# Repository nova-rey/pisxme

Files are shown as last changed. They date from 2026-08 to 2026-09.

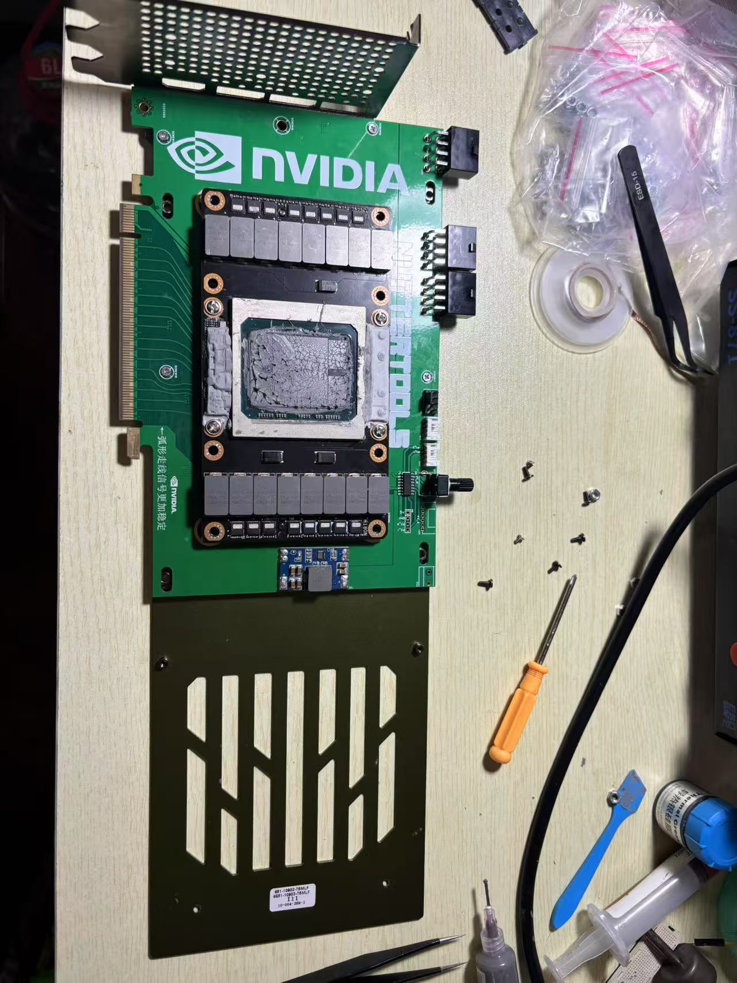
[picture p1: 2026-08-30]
references/LiuXinyu12378-SXM2_to_PCIE_adapter/images/WechatIMG451.jpg

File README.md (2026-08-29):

# PiSXMe

PiSXMe is an open-hardware compute-appliance carrier project for a Raspberry Pi Compute Module 5 and an NVIDIA Tesla V100 SXM2 module.

This public repository is a recovery/preservation snapshot prepared from verified local source files while the original iCloud-backed checkout contained unavailable File Provider placeholders. It preserves the Rev A design evidence and handoff material; it is not a claim that Rev A is fabrication-ready.

Read [HANDOFF_LINUX_WORKSTATION.md](HANDOFF_LINUX_WORKSTATION.md), [TOOLING_STATUS.md](TOOLING_STATUS.md), [references/REFERENCE_INDEX.md](references/REFERENCE_INDEX.md), and [plans/M6_LINUX_RESTART_CHECKLIST.md](plans/M6_LINUX_RESTART_CHECKLIST.md) before changing the design.

The authoritative active-design hashes and unavailable-source manifest are recorded in [RECOVERY_MANIFEST.md](RECOVERY_MANIFEST.md).

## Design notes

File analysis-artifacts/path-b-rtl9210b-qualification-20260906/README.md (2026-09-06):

# Path-B RTL9210B qualification fixture plan

Status: `PLAN_ONLY_NATIVE_FIXTURE_NOT_AUTHORIZED`

This is a disposable, read-only-first qualification artifact for the
RTL9210B-CG Path-B comparison. It is not production CAD, does not replace
Path A, and contains no copied or modified Path-A schematic/PCB content.

## Decision

Do not author a complete native Path-B KiCad fixture yet. The retained
community material is sufficient to state a narrow pin-identity contract, but
not sufficient to safely encode the support circuit, M-key sideband behavior,
power/isolation behavior, or virgin-chip provisioning assumptions. A partial
fixture would risk turning community guesses into electrical authority.

The smallest next fixture is a standalone RTL9210B bring-up board, authored
only after the gates in `fixture-plan.md` are closed. It must remain outside
the production project and must expose SPI-flash, UART/JTAG, reset, power,
mode, and M-key sideband test access.

## Artifact contents

- `fixture-plan.md` — bounded scope, facts, unknowns, gates, and acceptance plan.
- `pin-fact-boundary.csv` — machine-readable known/unknown boundary.
- `next-fixture-spec.json` — proposed smallest future standalone fixture.
- `baseline.md` — tool, stackup, correspondence, and fresh ERC/DRC evidence.
- `evidence-manifest.json` — source hashes and provenance boundaries.

No `.kicad_sch`, `.kicad_pcb`, library, project, rule, or production output is
authored by this artifact.

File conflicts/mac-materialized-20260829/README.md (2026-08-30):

# KiCad Codex Bridge

`kicad-codex-bridge` is a local MCP server that gives Codex a broad, observable control surface for KiCad 10. It uses the supported KiCad IPC API through `kicad-python` for live PCB work, the bundled `kicad-cli` for validation and exports, and a project-root-scoped file layer for KiCad source and generated files.

## Architecture

```text
Codex desktop / CLI
        |
        | Codex MCP config (stdio)
        v
server.py (FastMCP, 61 tools)
   |             |                  |
   |             |                  +--> scoped .kicad_* / libraries / outputs
   |             +--> bundled kicad-cli (DRC, ERC, exports, upgrades)
   +--> kicad-python 0.7.1 --> /tmp/kicad/api.sock --> KiCad PCB Editor
```

## Detected installation

- KiCad: `10.0.5`
- Application: `/Applications/KiCad/KiCad.app`
- CLI: `/Applications/KiCad/KiCad.app/Contents/MacOS/kicad-cli`
- Runtime: `/Users/Cooper/Documents/ChatGPT/sxm2/.venv311/bin/python` (Python 3.11)
- Binding: `kicad-python==0.7.1` (API build `10.0.1-0-g2db9e5a72b`)
- Project root: `/Users/Cooper/Documents/ChatGPT/sxm2`

`kicad-cli` is bundled but is not on the shell `PATH`. The bridge uses its absolute path and accepts `KICAD_CLI_PATH` as an override.

## Prerequisites and installation

KiCad must be installed. On this Mac, Homebrew Python 3.11 is used because the available KiCad Python binding and its dependency wheels are compatible with it.

```sh
cd /Users/Cooper/Documents/ChatGPT/sxm2
/usr/local/bin/python3.11 -m venv .venv311
.venv311/bin/python -m pip install -r requirements.txt
```

The checked-in environment was installed with `cryptography==44.0.3` because the newer source distribution attempted a Rust build on this Intel Mac. The pin is in `requirements.txt`.

## Start KiCad and the bridge

1. Start KiCad and open the target `.kicad_pcb` in PCB Editor.
2. In KiCad preferences, enable the KiCad API server under the Plugins/API settings.
3. Start the bridge as an MCP stdio process:

```sh
cd /Users/Cooper/Documents/ChatGPT/sxm2
KICAD_PROJECT_ROOT=/Users/Cooper/Documents/ChatGPT/sxm2 \
  .venv311/bin/python server.py
```

The process speaks MCP over stdin/stdout. Logs from FastMCP and KiCad are kept on stderr so the protocol stream remains clean.

## Codex registration

The supported local Codex mechanism is the `codex mcp` command, which writes the current user's MCP configuration. Register this exact server with:

```sh
codex mcp add kicad-codex-bridge \
  --env KICAD_PROJECT_ROOT=/Users/Cooper/Documents/ChatGPT/sxm2 -- \
  /Users/Cooper/Documents/ChatGPT/sxm2/.venv311/bin/python \
  /Users/Cooper/Documents/ChatGPT/sxm2/server.py
codex mcp list
```

The equivalent configuration is a `[mcp_servers.kicad-codex-bridge]` entry in `~/.codex/config.toml` with the same `command`, `args`, and an `[mcp_servers.kicad-codex-bridge.env]` table containing `KICAD_PROJECT_ROOT`. Codex desktop/CLI/IDE clients share this MCP configuration. A newly registered server may require a new Codex task or restart before its tools appear in an already-running task.

## Socket discovery and authentication

The bridge checks `KICAD_API_SOCKET` first, then discovers Unix sockets matching `/tmp/kicad/api.sock*` and the platform temporary directory. It connects with the official `kicad-python` client. If no token is supplied, the client follows KiCad's normal handshake: the first request has an empty token, KiCad returns the session token, and the bridge caches it for reconnects. `KICAD_API_TOKEN` can be supplied when an externally provisioned token is required.

KiCad 10's external IPC server requires the GUI/editor. The installed CLI has no headless `api-server` command; the headless API-server path is not claimed here.

## MCP surface

The server exposes 61 tools in the tested build:

- connection, version, open documents, open/reload/save/save-as, actions, selection;
- board summaries, dimensions, layers, stackup, design rules, net classes, nets, region queries;
- named list/inspect tools for footprints, pads, tracks, vias, zones, graphics, plus a generic item inspector;
- native footprint creation, movement, rotation, property edits, deletion, board text, graphics, tracks, vias, and item deletion;
- DRC, ERC, unrouted-item reports, CLI capability discovery, and structured CLI exports;
- scoped project-file list/read/write/validation;
- protobuf descriptor listing, object/method descriptions, property validation, and a raw protobuf call escape hatch.

All live edits use KiCad's create/update/delete and commit APIs where available, preserving native undo transactions. Failures are returned as explicit MCP errors.

The raw layer is descriptor-driven rather than arbitrary shell or memory access. Use `kicad_list_api`, `kicad_describe_object`, `kicad_describe_method`, `kicad_get_property`, `kicad_set_property`, and `kicad_raw_call` with fully qualified protobuf names when needed.

## Filesystem layer and validation

The root is restricted to `KICAD_PROJECT_ROOT`; path traversal outside it is rejected. `.kicad_pro`, `.kicad_sch`, `.kicad_pcb`, library files, project tables, rule files, and generated outputs can be listed/read/written. Direct edits are atomic, but they are not assumed valid: run `kicad_validate_file`, `kicad_drc`, or `kicad_erc` afterward.

The installed official `kicad-python` wheel has broad PCB bindings, but importing its schematic wrapper fails because the generated schematic types are incompatible (`BusEntryType` is missing), and no schematic command modules are shipped in the wheel. Schematic files are therefore available through the scoped file layer and KiCad CLI, not live schematic IPC editing, for this installation.

## End-to-end test

With the disposable board open in PCB Editor and the bridge registered or launched directly:

```sh
cd /Users/Cooper/Documents/ChatGPT/sxm2
.venv311/bin/python scripts/e2e_mcp_test.py
```

The test inspects the active board and layers through MCP, confirms footprint/pad/track/text state, saves, runs JSON DRC, reads the board back, invokes the raw version call, and generates Gerbers with `kicad-cli`. The disposable project is under `test-fixtures/disposable/`.

## Troubleshooting

- `no Unix socket was found`: start KiCad, open PCB Editor, and enable the API server.
- socket present but handshake fails: check that the socket belongs to the intended KiCad instance, close stale KiCad processes, or set `KICAD_API_SOCKET` explicitly.
- no PCB document: open a `.kicad_pcb`; the API server can be alive while the required editor/document is unavailable.
- CLI errors: call `kicad_cli_capabilities` and use the exact KiCad 10 help surface. Some exporters require an output directory, a layer list, or an operation-specific flag such as `--mode-single`.
- schematic IPC errors are expected for the installed `kicad-python==0.7.1` wheel; use scoped source edits plus `kicad-cli sch erc`/exports.

See [`CAPABILITY_MAP.md`](CAPABILITY_MAP.md) for the inventory and authoritative API references.

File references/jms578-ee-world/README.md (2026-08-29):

# EEWorld JMS578/M.2 reference capture

This directory contains a minimal, already-downloaded capture of the EEWorld
“M.2 SATA to hard drive adapter board based on JMS578” implementation used as
secondary engineering evidence for the PiSXMe storage island. The original
page is:

<https://en.eeworld.com.cn/Reference_Designs/detail/5f3ad50c>

The KiCad schematic/PCB/project and the source README are retained for
inspection. Firmware binaries, generated Gerbers, CAD shells, and the source
repository history were intentionally not copied. Treat this as reference
material, not as a PiSXMe-ready block; symbol/footprint/pin mapping and
licensing must be rechecked before reuse.

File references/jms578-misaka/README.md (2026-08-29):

# MiSaKa JMS578 reference capture

This directory preserves the schematic, PCB, extracted netlist, and local
analysis report from the MiSaKa JMS578 USB/SATA implementation used during the
PiSXMe disposable-island studies. It corroborates clock, reset, power, USB3,
and SATA topology but is secondary/empirical evidence. It is not a promoted
PiSXMe source block.

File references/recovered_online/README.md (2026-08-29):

# Locally Recovered Online References

These files were downloaded on 2026-08-29 from the authoritative Raspberry Pi
publication endpoints after the iCloud-backed copies in the working tree became
dataless placeholders. They are preserved here for Linux migration and do not
replace the active PiSXMe source.

| File | Source | SHA-256 |
|---|---|---|
| `CM5IO_rev2.zip` | <https://pip-assets.raspberrypi.com/categories/1098-design-files/documents/RP-008099-DD-1-CM5%20IO%20Board%2C%20revision%202%2C%20KiCAD%20files..zip> | `48b14a6757b0edc0ac110331445f35a4212b5ce432bdcec6605c99431b59496b` |
| `cm5-datasheet.pdf` | <https://datasheets.raspberrypi.com/cm5/cm5-datasheet.pdf> | `80070fefd8db6e8abc6e146c8b7b5fb318ba129cc1e28826936d547fde79c863` |
| `CM5IO_rev2_README.TXT` | Extracted from `CM5IO_rev2.zip` | `fda12849a155e136e43a299ff379dd54eb78375a5cc0e42b540d34400c2169ee` |

The archive contains the CM5IO Rev 2 KiCad schematic, PCB, symbols,
footprints, 3D models, and project files. The active PiSXMe schematic, PCB,
and symbol library remain separate and were not overwritten.

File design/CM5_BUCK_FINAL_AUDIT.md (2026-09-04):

# CM5 buck regulator audit

Selected module: TI `TPSM63606RDLR`, 6 A, 3–36 V input, 1–16 V output, no spread-spectrum variant. Primary authority: [TPSM63606 datasheet](https://www.ti.com/lit/ds/symlink/tpsm63606.pdf) and [TI product page](https://www.ti.com/product/TPSM63606).

## Correct pin contract

| Pins | Function | Required connection |
|---:|---|---|
| 1,16 | VIN1/VIN2 | protected 12 V; place separate close input capacitors at both pins |
| 2 | SW | no external copper beyond the minimum required; keep away from PCIe |
| 3,4 | CBOOT/RBOOT | leave per TI recommended application unless slew-rate tuning is explicitly needed |
| 5 | VLDOIN | tie to an appropriate output-bias point per TI; add the recommended local capacitor |
| 6,11 | AGND | connect to PGND at the module thermal/ground arrangement |
| 7 | VCC | internal LDO output; do not load externally |
| 8,9 | VOUT1/VOUT2 | 5 V output plane and output capacitors |
| 10 | FB | midpoint of feedback divider |
| 12 | RT | resistor to AGND; do not leave open |
| 13 | PG | open-drain power-good with 10–100 kΩ pull-up |
| 14 | EN/SYNC | defined enable/UVLO state; do not leave floating |
| 15 | NC | no-connect or ground exactly as TI permits |
| 17–20 | PGND | input/output capacitor return and thermal ground |

The prior custom symbol incorrectly represented several of these pins and omitted the required RT/VLDOIN semantics. It is not a production-ready buck symbol until corrected.

## Current clean-source correction

The native `REGULATORS.kicad_sch` source was audited against TI datasheet Rev.
B. The U3/U4/U5 pin-5 local labels were corrected from `12V_PROTECTED` to
their respective output rails (`CM5_5V`, `BRIDGE_3V3`, `BRIDGE_1V1`), using
the output as the VLDOIN bias point. Pin 14 remains the separately defined
`EN/SYNC` input on the intended 12 V enable policy. PCB materialization must
be regenerated from this corrected schematic; no PCB-only net swap is
authoritative.

## Rev A operating point

- Input: protected regulated 12 V.
- Output: 5.0 V for CM5, with a conservative 6 A-rated implementation even though CM5's expected requirement is lower.
- Feedback starting values from the TI 5 V example: `RFBT=40.2 kΩ`, `RFBB=10.0 kΩ`; include the required feed-forward capacitor only if it matches the selected layout/application values.
- Switching frequency: start at 1 MHz using the TI example RT value, approximately 13 kΩ, unless the final EMI review chooses a different value.
- Input: at least two close 10 µF, 50 V X7R/X7S capacitors, one associated with each VIN pin, plus local bulk.
- Output: design for at least 30 µF effective capacitance at 5 V after DC-bias and tolerance; use multiple capacitors rather than relying on one nominal value.
- PG pull-up: 10–100 kΩ to a defined logic rail.

## Placement and thermal gate

The module must sit in a dedicated CM5 buck zone, with a solid PGND/thermal copper region, thermal vias as permitted by the package/assembly process, and the shortest VIN/SW/VOUT loops shown in TI's recommended layout. The SW node is a hard keepout from the PCIe L1/L2 corridor. Thermal dissipation and load transient validation remain required on the prototype.

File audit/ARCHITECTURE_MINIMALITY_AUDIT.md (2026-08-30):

# PiSXMe architecture minimality audit

Status: complete, read-only audit of the active review board

Baseline: `c3e009f` / active-board SHA-256 recorded in `BASELINE_HASHES.md`

## Result

The active electrical architecture is minimal with respect to the stated
compute-appliance requirement: one CM5 host, one V100 SXM2 receptacle, one
PCIe Gen2 x1 lane, two independent CM5 USB3 ports, one USB2 service port,
power, cooling, and debug/recovery. No second GPU, NVLink, x16 PCIe, or
card-edge baggage was found in the active net structure.

The board is not yet *component-minimal*: the two Type-C FAST ports each pay
for an orientation mux and duplicate connector-side SuperSpeed branches. The
disposable USB-A trial in `experiments/usb-a-simplification/` demonstrates a
credible lower-complexity alternative. That is an architecture recommendation
for a future variant, not a mutation of this active review board.

## PCIe scope audit

| Check | Evidence | Classification |
|---|---|---|
| One lane electrically used | Active high-speed nets are `/PER0_P`, `/PER0_N`, `/PET0_P`, `/PET0_N`, `/REFCLK_P`, `/REFCLK_N`; control is `/PERST_N` and `/CM5_CLKREQ_N` | REQUIRED |
| Lane index | `design/PCIE_X1_INTERFACE_CONTRACT.md` and active CM5/SXM2 pin map identify lane 0 | REQUIRED |
| Lanes 1-15 | No active board net, segment, coupling capacitor, or footprint support block with lane 1-15 naming was found | ABSENT |
| Unused-lane AC coupling | C1/C2 are the two V100 TX coupling capacitors for lane 0; no additional PCIe lane coupling network remains | ABSENT |
| x16 support | No PCIe switch/bridge, x16 edge connector, lane fanout, or lane-specific support IC exists | ABSENT |
| Reference-clock scope | One differential REFCLK pair only | REQUIRED |

The raw PET0-side names are `/PET0_P_RAW` and `/PET0_N_RAW` at the two
source-side coupling capacitors; they are not additional lanes.

## SXM2/NVLink audit

- Exactly one `J1` `74221-101LF` exists.
- No second SXM2 connector, NVLink lane net, NVLink switch, retimer, or
  second-module power/control block exists.
- `MECH1` is a non-populated mechanical envelope annotation for the one V100
  module/cooler contract. It is not a second connector or an electrical net.
- The active connector net inventory contains no dead NVLink or second-module
  names.

Conclusion: the single-module scope is electrically respected.

## Suspicious or optional footprints

| Item | Current purpose | Classification | Disposition |
|---|---|---|---|
| D1 `SMBJ18A` | PCB-only provisional 12 V source TVS placeholder; excluded from BOM | UNKNOWN / pre-fabrication gate | Must be given schematic/BOM provenance or removed before fabrication; unchanged in this audit |
| TP1 | PERST# debug access marker | OPTIONAL_BUT_INTENTIONAL | Retain for bring-up; no high-speed stub |
| TP2 | REFCLK access marker/documentation point | OPTIONAL_BUT_INTENTIONAL | Retain only as a marker; no probe stub |
| TP3 | CM5 nRPIBOOT/recovery access | REQUIRED for recovery, optional for production assembly | Retain as the internal recovery path |
| R1 | DNP/POP CLKREQ link option | OPTIONAL_BUT_INTENTIONAL | Keep as a documented population option; do not populate without the defined strap decision |
| MECH1 | V100/SXM2 cooler/backplate envelope | OPTIONAL_BUT_INTENTIONAL | Keep as a mechanical contract annotation, never as a BOM item |

No item was proven to be legacy x16/NVLink baggage. D1 is a real release
closure issue, but its defect is provenance/implementation status rather than
evidence of a second-GPU architecture.

## CM5 feature minimality

| Feature | Active implementation | Classification |
|---|---|---|
| PCIe | One x1 lane plus clock/reset/request control | REQUIRED |
| USB3 | Two independent native ports, exposed as FAST-A/B Type-C | REQUIRED / intentionally exposed |
| USB2 | One SERVICE Type-C with DRP/recovery support | REQUIRED / intentionally exposed |
| eMMC | Consumed inside the CM5; no carrier circuitry needed | REQUIRED by recommended CM5 SKU, not separately routed |
| UART | Internal J8 header | REQUIRED debug |
| Recovery | nRPIBOOT and service-role circuitry | REQUIRED debug/recovery |
| Cooling | Two fans and optional pump header | REQUIRED for a 300 W-class appliance |
| Native Ethernet | Not implemented on PiSXMe | INTENTIONALLY_UNUSED; USB NIC is the selected modular path |
| HDMI/MIPI | Not implemented | UNUSED_AND_NOT_IMPLEMENTED |
| microSD | Not implemented | UNUSED_AND_NOT_IMPLEMENTED; eMMC/USB cover boot/storage |
| HAT/general GPIO expansion | Not implemented as a user connector | UNUSED_AND_NOT_IMPLEMENTED |
| Wi-Fi external circuitry | None | UNUSED_AND_NOT_IMPLEMENTED; Wi-Fi remains SKU-dependent |
| RTC/extra CM5 reference-board blocks | None identified | UNUSED_AND_NOT_IMPLEMENTED |

## Audit conclusion

The active board does not contain a hidden x16 or multi-GPU architecture. The
main inherited complexity is the chosen reversible Type-C implementation, not
unused accelerator circuitry. The USB-A disposable variant is therefore a
legitimate simplification candidate, but it should be treated as a new
architecture revision rather than silently applied to the current RC1.

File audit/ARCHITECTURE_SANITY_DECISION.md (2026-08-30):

# Architecture sanity decision

## Decision

**SWITCH_FAST_PORTS_TO_USB_A**

Architecture classification: **SIMPLIFICATION_RECOMMENDED_BEFORE_EXTERNAL_REVIEW**

This recommendation applies to a future PiSXMe architecture revision. The
active board and schematic were not modified by this audit.

## Basis

1. Raspberry Pi’s official CM5IO routes both native 5 Gbps CM5 USB3 ports
   directly to Type-A, with an explicit P/N naming swap for routing.
2. The official CM5 documentation makes the two USB3 ports independent; the
   connector shape does not reduce their rate or consume PCIe bandwidth.
3. The disposable two-port direct Type-A trial achieved 0 signal vias, 0
   unconnected items, and 0 DRC violations with maximum SuperSpeed skew
   0.109838 mm.
4. The active reversible Type-C design uses 80 USB3 signal vias, two muxes,
   duplicated connector-side branches, CC/source support, and four
   SuperSpeed ESD placements. Those are functional Type-C costs, not CM5
   transport requirements.
5. FAST-A storage and FAST-B commodity 2.5GbE are fully supported by ordinary
   USB3 Type-A at 5 Gbps. No USB-PD, reversible insertion, or PCIe storage
   path is required by the product requirement.

## Quantified simplification opportunity

For the two FAST ports, a fixed-host USB-A revision can remove:

- 2 HD3SS3212 muxes;
- 2 Type-C FAST CC/source control paths, subject to retaining suitable host
  VBUS switches;
- 2 of the 4 active SuperSpeed ESD branch devices if one SS ESD array per
  port is retained, or all 4 if the future protection review follows the
  official CM5IO USB3 sheet;
- 64 connector-side SuperSpeed signal vias, before any rerouting choice;
- the duplicated reversible branch conductors and local fanout constraints.

The focused trial removes 80 signal vias relative to the active two-port
USB3 signal-via total, but it omits final power/ESD and therefore must not be
used as a manufacturing BOM delta. A future schematic must re-add and verify
VBUS current limiting, USB2 companion behavior, ESD, connector footprints,
and the complete CM5 net mapping.

## Function lost

The only confirmed product-level loss is reversible USB-C plug orientation.
USB3 bandwidth, independent-port operation, storage use, optional 2.5GbE
USB-NIC use, and PCIe allocation are preserved. An internal dual-USB3 header
remains a valid enclosure-specific alternative but shifts SI/mechanical risk
into a cable and daughterboard, so it is not the primary recommendation.

## Active-board boundary

The active Type-C PiSXMe files remain byte-identical to the baseline. This
decision is a recommendation for the next design revision, not permission to
silently rewrite the current external-review package.

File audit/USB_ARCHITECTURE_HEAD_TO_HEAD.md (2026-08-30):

# USB architecture head-to-head

| Metric | Current PiSXMe USB-C | Disposable USB-A variant | Official CM5IO reference |
|---|---|---|---|
| Ports | 2 | 2 | 2 (one stacked J12) |
| Speed/port | 5 Gbps native CM5 USB3 | 5 Gbps native CM5 USB3 | 5 Gbps native CM5 USB3 |
| High-speed mux ICs | 2 HD3SS3212 | 0 | 0 |
| CC ICs | TPS25821 integrated FAST source paths; Type-C support | 0 for fixed host | 0 for Type-A |
| USB3 ESD | 2 four-line arrays/port in active board | omitted from focused trial; future variant may retain 1/port | no USB3 ESD TPD4 identified in highspeed sheet |
| USB2 companion ESD | 1/port | omitted from focused trial | no USB3-sheet companion ESD identified |
| Signal vias | 80 total (40/port) | 0 in trial | 16 total, 1.33/conductor |
| Return/stitching | 6 categorized active GND vias | 0 in focused coupon | 476 board-wide GND vias |
| Active ICs in one FAST port | mux + VBUS controller + 3 ESD devices = 5 | 0 in trial; direct variant needs chosen VBUS/ESD protection | shared VBUS switch allocation; no mux |
| Direct SuperSpeed topology | mux plus reversible branch fanout | host launch → Type-A | CM5 → stacked Type-A |
| DRC trial quality | accepted production USB-C routing, but complex | 0/0 direct SS trial | official fabricated design |
| User functionality | reversible plug | fixed/keyed plug | fixed/keyed plug |

The Type-A variant preserves the CM5 link capability and intended SSD/NIC
function while materially simplifying the SuperSpeed topology. The active
board remains unchanged and its Type-C architecture remains the current
review artifact.

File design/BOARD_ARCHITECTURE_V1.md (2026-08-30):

# PiSXMe board architecture V1

Status: placement and partitioning concept only. No production PCB placement, plane geometry, or routing is included.

## Zones

1. **SXM2 socket/module zone:** populated Meg-Array, V100 module mechanical envelope, adjacent ground/current contacts, and cooler contact keepout.
2. **PCIe x1 corridor:** one TX pair, one RX pair, REFCLK pair, and short reset escape. L1 over solid L2 GND; no high-current switching components.
3. **CM5 connector/module zone:** two board-to-board connectors, 40 × 55 mm module keepout, M2.5 mounting access, and external-antenna/RF decision.
4. **V100 high-current power zone:** dual high-current 12 V entry, fuse/protection, bulk capacitance, current distribution, and the V100 enable/power-good supervisor.
5. **CM5 5 V conversion zone:** 12 V-to-5 V synchronous buck, input/output bulk, EMI containment, and 5 V test points. Place it outside the PCIe corridor.
6. **Ethernet/USB I/O zone:** connector access, cable bend space, USB power switching, and magnetics. Route this around the PCIe corridor.
7. **Fan/pump/control zone:** fan headers, tach/PWM, pump header, temperature monitoring, and status LEDs.
8. **Debug/bring-up zone:** CM5 UART, reset/power-good test points, V100 enable visibility, and low-speed strap/control resistors.

## Placement relationships

```text
V100 thermal + SXM2 power  →  PCIe corridor  →  CM5 B2B/module  →  Ethernet/USB/debug edge
                         CM5 buck is lateral to the module, not beneath the corridor
```

The corridor is a protected geometric reservation, not merely a net class. The only high-speed components permitted in it are the two external 220 nF V100-TX capacitors. Keep inductors, switch nodes, MOSFET power loops, high-current vias, magnetics, and mounting-hole antipads out of it.

## Stack and return-path policy

- L1: PCIe/REFCLK and selected short controls.
- L2: uninterrupted GND beneath the corridor.
- L3/L6: power distribution and low-speed power islands, arranged so they do not split L2.
- L4: control and general signals.
- L5: solid GND.

The exact width/gap is deferred to the selected fabricator's controlled-impedance calculator and coupon. The official CM5IO 4-layer design is useful evidence that 90 Ω routing is practical, but it is not a geometry source for this different board.

## Modular USB-C I/O revision

The former generic Ethernet/USB placeholder is replaced by three real board-edge interfaces:

- `J9 USB3-A` / FAST A: independent CM5 USB3 port 0 for storage, including its USB2 companion D+/D− path.
- `J10 USB3-B` / FAST B: independent CM5 USB3 port 1 for a commodity USB 2.5GbE adapter, including its USB2 companion D+/D− path.
- `J11 SERVICE`: USB2 dual-role/recovery port with hardware VBUS interlock.

The ports occupy the right board edge outside the PCIe corridor. A second
`TPSM63606RDLR` module (`U16`) supplies the USB peripheral 5V rail; the CM5
rail remains isolated. No USB hub, native RJ45, microSD, or USB-PD circuitry is
part of this revision.

## Bring-up provisions

- CM5 UART/debug access and boot/configuration access.
- `TP_PERST`, `TP_CLKREQ`, `TP_PWR_EN`, `TP_V100_PWR_GOOD`.
- Low-speed reset control option and power-good indicators.
- V100 rail voltage/current test points and optional shunt monitor.
- Fan/tach and pump headers if cooling requires them.
- No direct probe stubs on PET/PER/REFCLK; high-speed measurement requires dedicated launch structures only in a later SI plan.

## Explicit exclusions

- no lanes 1–15;
- no conventional PCIe card edge;
- no slot-presence emulation;
- no redriver/retimer in V1;
- no final production USB-C vendor-CAD overlay until connector verification and assembly review;
- no production plane or route geometry in this phase.

## Rev-A cooler-agnostic placement update

The board now uses a formal cooler-owned contract rather than a selected V100
cooler. The serviceable provisional outline is 220 mm × 140 mm. Reserve
150 mm × 95 mm and at least +45 mm above the board for external cooling, with
the same XY footprint below for a possible backplate and retention hardware.
Keep CM5, power entry, tall inductors, I/O, and debug outside that volume.

The placement study contains actual part choices: Amphenol `74221-101LF`, two
Amphenol `10164227-1004A1RLF` CM5 connectors, dual Molex `39301082` Mini-Fit
headers, TI `TPSM63606RDLR` rails, TI `LM74700QDBVRQ1` + `CSD19536KCS`, three
Amphenol USB-C receptacles, and JST/Molex cooling/debug headers. The board is
six-layer, unrouted, and has no final power pours. The full contract is in
[`mechanical/COOLING_MECHANICAL_CONTRACT.md`](../mechanical/COOLING_MECHANICAL_CONTRACT.md).

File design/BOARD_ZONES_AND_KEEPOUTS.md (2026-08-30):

# PiSXMe board zones and keepouts

The placement-study board `pisxme/PiSXMe.kicad_pcb` is intentionally unrouted.
Zones are represented as `Dwgs.User`/`Cmts.User` rectangles. The cooler and
backplate rectangles are deliberately not KiCad copper/pad keepout zones,
because the SXM2 connector itself must occupy that XY region. Electrical
keepouts will be added after the real connector/retention geometry is frozen.
There are no production pours or final power planes.

## Provisional coordinate map

Board origin is the lower-left of a 220 mm × 140 mm serviceable outline.

| Name | Study rectangle (mm) | Purpose |
|---|---|---|
| `TOPSIDE_COOLER_KEEP_OUT` | x 10–160, y 22.5–117.5 | External cooler-owned top volume; 150 × 95 mm XY reservation |
| `UNDERSIDE_BACKPLATE_KEEP_OUT` | same XY footprint | Backplate, bolt, nut, washer, and underside component reservation |
| `SXM2_MODULE_ZONE` | inside cooler reservation | SXM2 receptacle, V100 package envelope, retention datum work |
| `PCIE_X1_CORRIDOR` | x 141–168, y 54–86 | One PCIe TX pair, one RX pair, REFCLK pair, reset escape |
| `CM5_ZONE` | x 160–210, y 45–108 | CM5 40 × 55 mm land pattern/body envelope and service edge |
| `HIGH_CURRENT_POWER_ZONE` | x 5–70, y 5–140 | Dual Mini-Fit inputs, fuses, reverse protection, V100 distribution |
| `CM5_BUCK_ZONE` | x 175–215, y 108–138 | TPSM63606 and its power-loop components |
| `IO_ZONE` | x 160–210, y 5–45 and I/O edge | Ethernet/USB access outside PCIe corridor |
| `COOLING_CONTROL_ZONE` | x 190–218, y 5–38 | 2 fan headers, pump/aux header, thermal/control wiring |
| `DEBUG_ZONE` | east/south service edge | UART, reset/power-good test points, indicators |

## Layer policy

- `L1/F.Cu`: future PCIe/REFCLK route and selected short controls; keep the
  corridor geometrically boring.
- `L2`: continuous GND under the PCIe corridor; no high-current split or
  switching return interruption.
- `L3/L4`: power and low-speed partitioning as determined by the final fab
  stackup; do not use the study stackup as production impedance authority.
- `L5`: preferred additional GND reference/return plane.
- `L6/B.Cu`: low-speed and power access, subject to the cooler/backplate and
  service constraints.

## Corridor prohibitions

The PCIe corridor prohibits switching inductors, buck switch nodes, high-
current connector pin fields, high-current via arrays, magnetic Ethernet
components, unrelated clocks, copper-plane transitions, test stubs, and
mounting-hole antipads. The two V100-transmitter AC-coupling capacitors may
sit at the corridor entrance only when the final impedance and return-path
review approves their exact placement.

## Mechanical representation limits

The current board contains representative CM5 STEP geometry from the official
CM5 package and a preserved reference SXM2 connector model. It does not contain
an authoritative V100 module/cooler/backplate model. The rectangle keepouts are
therefore deliberate collision contracts, not proof of fit for a named cooler.

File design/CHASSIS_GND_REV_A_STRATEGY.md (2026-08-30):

# USB-C shield / chassis strategy for Rev A

## Selected strategy

`DIRECT_USB_C_SHELL_TO_GND`

J9, J10, and J11 S1/S2 shell pads are intentionally bonded to the board
`/GND` net. No separate `/CHASSIS_GND` copper trunk, RC link, or chassis
bridge component is used in Rev A.

## Why this is the selected closure

- All five prior shell connectivity relationships close without a new copper
  route through the USB3/USB2 connector fields.
- A direct-GND trial produced no new short, clearance, crossing, or pad
  overlap class relative to the final-plane baseline.
- `cm5MiniITX` provides working open-hardware precedent for USB-C shell pads
  tied directly to GND.
- The alternate isolated-shell and edge-trunk choices are not electrically
  complete in the current placement; the edge trunk crossed accepted
  high-speed/service geometry.

## Mechanical/EMI note

The board-level connection does not define the enclosure bonding method. A
metal enclosure should receive its own controlled mechanical bond if it is
used as a shield. A plastic enclosure has no enclosure return to bond. This
is a Rev-A simplification and a documented EMI risk, not an unresolved PCB
connectivity record.

## Verification gate

The six shell pads must appear on `/GND` in the active PCB, and the three
schematic shell labels must be `GND`. The final DRC may retain inherited
library/cosmetic/dangling findings, but it must contain no
`CHASSIS_GND` unconnected record and no new true electrical class.

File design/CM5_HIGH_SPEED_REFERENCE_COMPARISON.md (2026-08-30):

# CM5 high-speed reference comparison

Date: 2026-08-23

## Official Raspberry Pi CM5IO

The official CM5IO project is the highest-authority CM5 carrier evidence in
this set. It uses Type-A connectors rather than a Type-C orientation mux, so it
does not provide a direct mux fanout template. It does provide two important
facts:

* `CM5_HighSpeed.kicad_sch` explicitly says `USB 3 Pairs P/N swapped to help
  routing`.
* Its USB3 footprint mapping visibly assigns the physical Type-A pad order to
  swapped P/N net names, confirming that physical polarity remapping is part of
  the official CM5 carrier layout practice.

A read-only PCB inspection found a small number of USB3 layer transitions: the
two ports use F.Cu/B.Cu as needed, with roughly one or two vias per conductor
depending on the path. This is evidence that a via is acceptable when needed,
not a target for PiSXMe’s short local fanout.

## ModuCard CM5 Module

Source: MIT-licensed `references/cm5/moducard-cm5-module/`, commit
`2d96d2e238e6e020c98220d49595c7a6028a35cf`. The README reports fabrication,
assembly and bring-up completion.

Read-only PCB metrics for the USB SuperSpeed nets:

| Group | Observation |
|---|---|
| `USB_SS_0` | F.Cu only, zero vias, approximately 8.3–9.9 mm paths in the local CM5-to-connector/hub region |
| `USB_SS_1` | F.Cu/B.Cu, one via per net, approximately 31–45 mm paths |

This is useful working-hardware evidence that direct CM5 USB3 routing can be
short and simple, but its connector and board geometry differ from PiSXMe.

## cm5MiniITX

Source: `references/cm5/cm5MiniITX/`, commit
`479fee1dd5831eab652e72c031d0c806a2091c44`. The checkout describes itself as a
prototype and has no clear project-level license, so it is reference-only.

Read-only metrics show longer USB3 paths, with some F.Cu/B.Cu transitions and
several vias on one port. This demonstrates that a working-looking carrier can
trade length/vias for board-level placement, but it is not a justification for
PiSXMe’s former 40–46-via Type-C fanout.

## Lessons applied to PiSXMe

1. CM5 physical escape order must be treated as a first-class constraint.
2. P/N labels are not sacred physical order; the official CM5IO itself records
   swaps for routing.
3. A zero-via or low-via local route is plausible when mux/ESD/connector order
   is designed together.
4. A second layer is an allowed fallback, not a substitute for fixing an
   avoidable polarity/order mismatch.
5. No CM5 reference justifies altering the frozen PCIe routing in this phase.

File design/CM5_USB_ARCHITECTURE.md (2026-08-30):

# CM5 USB architecture

Status: **Rev-A architecture resolved; PCB remains placement-only and unrouted.**

Primary authority: Raspberry Pi, [Compute Module 5 datasheet](https://pip.raspberrypi.com/categories/944-raspberry-pi-compute-module-5/documents/RP-008180-DS/cm5-datasheet.pdf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), and [Compute Module documentation](https://www.raspberrypi.com/documentation/computers/compute-module.html).

## Confirmed CM5 interfaces

| PiSXMe port | CM5 pins | CM5 function | Intended role |
|---|---|---|---|
| USB-C FAST A | 128/130 RX, 134/136 D+/D-, 140/142 TX | USB3 port 0 | USB 3 storage |
| USB-C FAST B | 157/159 RX, 163/165 D+/D-, 169/171 TX | USB3 port 1 | USB 3 Ethernet adapter |
| USB-C SERVICE | 103/105 D-/D+, 101 USB_OTG_ID | independent USB2 | host/service and recovery |
| CM5 control | 111 VBUS_EN, 93 nRPIBOOT | USB power enable and boot strap | fast-port power / rpiboot procedure |

The datasheet specifies two independent USB3 interfaces, each capable of 5Gbps and capable of simultaneous operation, plus one independent USB2 high-speed interface. The PCIe interface is a separate Gen2 x1 host interface; the USB architecture does not consume PCIe bandwidth.

FAST A and FAST B are therefore not two connectors behind a hub or a shared USB upstream link. Each has its own CM5 SuperSpeed TX/RX pair, USB2 companion pair, Type-C CC/source controller, SuperSpeed orientation mux, VBUS switch, two four-line `TPD4EUSB30` SuperSpeed ESD arrays (one per orientation branch), and one `TPD2EUSB30A` USB2 companion-pair ESD array. The companion D+/D− pair is required to terminate the USB3 Type-C port correctly; it is not the separate CM5 USB2 interface.

## SERVICE role

SERVICE is a USB2-only Type-C dual-role port using `TUSB320LAIRWBR`. In normal appliance operation it is configured as a host and can drive a small hub or keyboard/mouse. For CM5 provisioning, the board exposes the CM5 USB2 path and preserves `nRPIBOOT` and internal UART access. Raspberry Pi's documented flow is to assert `nRPIBOOT`, connect the USB slave path to a host, run `rpiboot`, and use the resulting mass-storage gadget to provision eMMC.

The service VBUS switch is hardware-interlocked with the TUSB320 ID/status signal. It is enabled only when the CM5 is acting as a source/host, preventing VBUS backfeed when the port is used as a device for recovery. The exact bootloader/firmware mode remains a bring-up configuration item; the schematic does not claim that a single port can simultaneously be host and device.

CM5 USB2 host mode can be selected with the documented `dtoverlay=dwc2,dr_mode=host` configuration. The internal UART remains available even if SERVICE is occupied or USB enumeration fails.

## Important constraints

- CM5 pins 94/96 are CM5 power-input PD CC pins, not the external USB port CC pins; they are not reused here.
- CM5 pin 111 is a 3.3V active-high USB3 power-enable control shared by the two fast-port source switches.
- CM5 USB3 TX coupling is internal per the datasheet; no second external TX capacitor is added.
- USB3 and USB2 are routed as 90-ohm-class interfaces. USB3 reversible orientation is handled by `HD3SS3212`; USB2 does not need a SuperSpeed mux.
- No USB hub, native RJ45, USB-PD profile, or microSD slot is added.

## Confidence

CM5 interface count, pin numbers, independence from PCIe, and USB2 OTG/recovery signals are **official Raspberry Pi documentation**. SERVICE dual-role implementation is an engineering implementation using TI's Type-C controller and hardware VBUS interlock; it still requires Rev-A software/bring-up validation.

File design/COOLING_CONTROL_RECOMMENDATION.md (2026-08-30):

# Cooling-control recommendation

Rev-A should expose three standard 4-pin headers:

- `J5` fan 1: 12 V, GND, tach, PWM.
- `J6` fan 2: 12 V, GND, tach, PWM.
- `J7` pump/aux: 12 V, GND, tach, PWM, with a cooler-specific current limit.

The selected header family is JST `B4B-XH-A`, 2.50 mm pitch. The board should
provide local bulk/decoupling and a documented current limit, but it should
not promise that the raw V100 12 V rail can start an arbitrary pump. A later
power review may add a separate protected pump branch or a soft-start switch.

For Rev-A, CM5 software control is preferred over adding an MCU: it avoids a
new firmware/update path and is sufficient for a non-safety-critical prototype
if the system has a hardware thermal shutdown independent of fan software.
Use the tach inputs for monitoring and PWM for command. A dedicated fan
controller or external pump controller remains a user-defined option for an
enclosure that must regulate cooling while CM5 is off or booting.

Do not place high-speed probe points or stubs in the PCIe/REFCLK corridor. If a
future thermal monitor is needed, add low-speed sensor headers in the cooling-
control zone.

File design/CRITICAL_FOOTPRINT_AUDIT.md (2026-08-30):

# Critical footprint audit

## Status

**Incomplete; not a fabrication signoff.** The project contains architectural/custom footprints and several critical manufacturer footprints whose pad numbering, mating height, or 3D model orientation has not been verified against current manufacturer drawings in the hydrated KiCad project.

| Item | Selected part | Audit result |
|---|---|---|
| SXM2 | Amphenol `74221-101LF` | Electrical identity and 400-position count corroborated; exact land pattern, module mating height, and 3D orientation still require manufacturer CAD/drawing review. |
| CM5 BTB | 2 × Amphenol `10164227-1004A1RLF` | 100-position, 0.4 mm, 4 mm stack verified from manufacturer page; exact STEP and final land-pattern review remain open. |
| 12 V header | Molex `39301082` | Corrected from the erroneous `39301062`; pad pitch/orientation and mating-housing clearance must be checked in the actual footprint. |
| 12 V receptacle | Molex `39012085` | Mating housing selected; cable/contact sourcing and assembly access remain to be validated. |
| Fuse | Littelfuse `178.6165.0001` + `0297015.U` | Rating choice documented; holder footprint, fuse extraction clearance, and thermal copper remain open. |
| Ideal diode | LM74700-Q1 + CSD19536KCS | Current schematic placeholder is not acceptable; exact symbol pin numbering, MOSFET orientation, and gate loop need replacement and review. |
| Buck | TPSM63606RDLR | TI pinout and layout requirements identified; current custom symbol must be corrected. |
| AC coupling | Murata `GRM21BR71H224KA01#` candidate | 220 nF/50 V/0805 verified from Murata; validate DC-bias and footprint before release. |
| Fan headers | Molex `22-23-2041` | 4-pin, 2.54 mm, vertical, partially shrouded, 4 A/contact from Molex data; use as standard PC-fan-compatible candidate. |

Critical footprints are not cleared until their actual pad numbering, courtyard, solder-mask/paste rules, 3D orientation, mating direction, and rework access are checked in KiCad and against the manufacturer drawing.

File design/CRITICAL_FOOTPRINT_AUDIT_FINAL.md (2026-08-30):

# Critical footprint audit — final pre-routing pass

Date: 2026-08-21
Decision: **CLOSED FOR ROUTING; USB CONNECTOR CAD OVERLAY REMAINS A RELEASE GATE**

No fabrication-critical item remains `LIBRARY_ONLY` or `UNRESOLVED`. The
classifications below mean either manufacturer land-pattern authority was
checked directly or the package was checked against the manufacturer
datasheet/reference layout. This is not a final PCBA quote or stencil release.

| Ref / part | Active footprint / status | Classification | Evidence and remaining process note |
|---|---|---|---|
| J1 / Amphenol 74221-101LF | `SXM2_74221-101LF_MANUFACTURER_DERIVED`; 400 pads, 1.27 mm grid | **MANUFACTURER_VERIFIED** | Manufacturer drawing/spec/application spec; see SXM2 land-pattern signoff. Hidden joints require X-ray/AOI and stencil review. |
| J2A, J2B / Amphenol 10164227-1004A1RLF | `CM5_10164227-1004A1RLF_MANUFACTURER_DERIVED`; 2 × 50-pad rows, 0.4 mm pitch | **MANUFACTURER_VERIFIED** | Official 10164227 drawing; 0.20 × 1.50 mm lands, row centers ±1.19 mm in model; instances deliberately rotated 90° mechanically, not mirrored. |
| J3, J4 / Molex 39301082 | `MiniFitJr_8_RA` placement footprint; 2 × 4 positions at 4.20 mm pitch | **DATASHEET_DERIVED_AND_CHECKED** | Molex product/drawing data checked for 8-circuit right-angle family, keying and through-hole assembly intent. Final cable-entry and solder-fill review remains required. |
| J3/J4 mating / Molex 39012085 | cable housing, no PCB land pattern | **DATASHEET_DERIVED_AND_CHECKED** | Mating-housing record checked; it is not a PCB footprint. |
| U1 / TI TPSM63606RDLR | `TPSM63606RDLR_MANUFACTURER_DERIVED`; 20 pads with central PGND 17–20 | **DATASHEET_DERIVED_AND_CHECKED** | TI RDL package drawing and reference layout checked. Thermal-via array and paste segmentation are intentionally deferred to routing/assembly phase. |
| U2, U3 / TI LM74700QDBVRQ1 | `LM74700_DBV` SOT-23-6 | **DATASHEET_DERIVED_AND_CHECKED** | TI DBV package/pin numbering checked. |
| Q1, Q2 / TI CSD19536KCS | `CSD19536KCS_TO220` | **DATASHEET_DERIVED_AND_CHECKED** | TI TO-220 pin order and body/lead orientation checked; heatsink/assembly envelope remains a manufacturing note. |
| F1, F2 / Littelfuse 178.6165.0001 | `ATO_FLR_1786165_0001_MANUFACTURER_DERIVED`; 8 solder holes + central retention NPTH | **DATASHEET_DERIVED_AND_CHECKED** | Official 1786165 drawing checked: 1.4 mm solder holes at ±5.8/±2.3 mm and ±1.25 mm; 2.4 mm retention hole. Eight duplicate-numbered pads are the deliberate parallel-leg grouping for the two-pin fuse symbol. |
| C1, C2 / Murata GRM21BR71H224KA01# | 0805 / 2012 metric | **DATASHEET_DERIVED_AND_CHECKED** | Murata 0805 land-pattern class checked; voltage/DC-bias/SI suitability remains a circuit review item. |
| J5–J7 / Molex 22-23-2041 intent | `Fan_2x2_2.54mm`, 1 × 4 at 2.54 mm pitch | **DATASHEET_DERIVED_AND_CHECKED** | Pin order is documented GND/+12V/TACH/PWM; final shroud/key choice must be confirmed with assembly vendor. |
| J8 / JST B4B-PH-K-S intent | `UART_1x04`, 1 × 4 at 2.0 mm pitch | **DATASHEET_DERIVED_AND_CHECKED** | JST PH pitch and 1×4 land pattern checked; cable/keying remains a harness detail. |
| J9/J10 / Amphenol 10137064-00011LF | `USB_C_FAST_10137064`, 24 contacts, 0.5 mm contact pitch | **DATASHEET_DERIVED_AND_CHECKED** | Official Amphenol product page and drawing URL establish USB3 Gen2, 24P, 5A VBUS, 1.5A GND, 0.8mm PCB and 10k cycles. Local placement model uses the manufacturer drawing family; obtain the vendor CAD overlay before release. |
| J11 / Amphenol 10171746-00021LF | `USB_C_SERVICE_10171746`, 16 contacts | **DATASHEET_DERIVED_AND_CHECKED** | Official Amphenol product page and drawing URL establish USB2 Type-C 16P, 5A, 0.60mm PCB and 10k cycles. Local placement model preserves A/B duplicated USB2 contacts; obtain the vendor CAD overlay before release. |
| U4/U8 / TI TPS25821DSSR | `TPS25821_DSS`, WSON/DSS 12 | **DATASHEET_DERIVED_AND_CHECKED** | TI pin configuration, DSS body and exposed-pad requirements checked from official datasheet. |
| U5/U9 / TI HD3SS3212IRKSR | `HD3SS3212_RKS`, VQFN/RKS 20 | **DATASHEET_DERIVED_AND_CHECKED** | TI RKS pin configuration and high-speed channel numbering checked from official datasheet. |
| U6/U7/U10/U11 / TI TPD4EUSB30 | `TPD4EUSB30_DQA`, USON/DQA 10 | **DATASHEET_DERIVED_AND_CHECKED** | TI package/pinout and two orientation-branch arrays per reversible FAST port checked. |
| U17/U18 / TI TPD2EUSB30A | `TPD2EUSB30A_DQA`, USB2 ESD 10-pad model | **DATASHEET_DERIVED_AND_CHECKED** | TI USB2 companion-pair package/pinout and connector-side placement checked. |
| U12 / TI TUSB320LAIRWBR | `TUSB320LAI_RWB`, X2QFN/RWB 12 | **DATASHEET_DERIVED_AND_CHECKED** | TI package/pinout and DRP/ID behavior checked. |
| U13 / TI TPS2553DBVR | `TPS2553_DBV`, SOT-23/DBV 6 | **DATASHEET_DERIVED_AND_CHECKED** | TI DBV package/pinout and ILIM pin checked. |
| U14 / TI SN74LVC1G04DCKR | `SN74LVC1G04_DCK`, SC70/DCK 5 | **DATASHEET_DERIVED_AND_CHECKED** | TI DCK package/pinout checked. |
| U15 / TI TPD2EUSB30A | `TPD2EUSB30A_DQA` | **DATASHEET_DERIVED_AND_CHECKED** | TI USB2 ESD package family checked; exact vendor CAD overlay remains a release gate. |
| U16 / TI TPSM63606RDLR | `TPSM63606_USB` | **DATASHEET_DERIVED_AND_CHECKED** | Same manufacturer-derived RDL0020 package basis as U1; dedicated USB rail placement added without changing U1 topology. |
| R5/R6/R7 / 0603 resistors | `Resistor_SMD:R_0603_1608Metric` | **DATASHEET_DERIVED_AND_CHECKED** | Standard IPC/JEDEC 0603 land-pattern class; manufacturer MPNs recorded in schematic/BOM. |

## Mechanical and assembly checks

- J1's 5.10 mm perimeter rework allowance is represented and remains clear.
- J2A/J2B hidden 0.4 mm joints remain accessible only through the intended
  module installation path; X-ray is recommended.
- F1/F2 are through-hole/retention-style components and may require selective
  solder or hand placement.
- U1's exposed thermal area is represented by the four central PGND lands;
  the final copper/via implementation is a routing-phase task, not a reason to
  use a library-only package.
- USB-C receptacles are on the right board edge outside the cooler-owned and
  PCIe zones; J8 was moved inward for cable/debug clearance.
- No current critical component overlaps the cooler-owned or underside
  backplate volume in the placement study.

## Preserved manufacturer resources

- `references/manufacturer/Amphenol_74221-101LF/`
- `references/manufacturer/Amphenol_10164227-1004A1RLF/`
- `references/manufacturer/Littelfuse_1786165/`
- `references/manufacturer/TI_power_parts/`
- `references/manufacturer/TI_USB/`

Amphenol USB drawing links and access status are recorded in
`references/manufacturer/MANUFACTURER_RESOURCES_MANIFEST.md`. The direct CDN
download returned HTTP 403 in this environment; this is why the USB rows are
classified datasheet/drawing-derived rather than claiming an imported vendor
CAD overlay.

The board is still a placement study with zero production tracks, vias, and
copper zones. Final assembly approval remains distinct from routing readiness.

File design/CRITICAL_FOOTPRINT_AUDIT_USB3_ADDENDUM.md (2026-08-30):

# Critical USB3 footprint audit addendum

Date: 2026-08-23

This addendum supersedes any earlier “library-only” or “usable with
reorientation” conclusion for the two local USB3 fanout packages.

| Reference family | Active footprint | Evidence | Final status |
|---|---|---|---|
| HD3SS3212IRKSR | `PiSXMe:HD3SS3212_RKS` | TI HD3SS3212 RKS0020A package drawing and imported TIDA-00987 source | **NOT_VERIFIED — geometry mismatch** |
| TPD4EUSB30 | `PiSXMe:TPD4EUSB30_DQA` | TI TPD4EUSB30 official DQA package drawing | **NOT_VERIFIED — geometry mismatch** |

The mismatch is physical pad placement, not merely a missing 3D model or
silkscreen detail. These two footprints are fabrication-critical and must be
replaced/verified before USB3 copper is authorized.

The other previously closed footprint audits are not reopened by this
addendum. PCIe, SXM2, power, CM5, and board-edge mechanical anchors were not
changed.

## Source-archive closure update — 2026-08-23

The attached TI source archive was imported and the corrected analysis-only
footprints were checked in a disposable coupon. The coupon passes with zero
violations and zero unconnected items under its explicit bounded local escape
rule. This validates the corrected package model and flow-through ESD
experiment; it does not reclassify the active footprints. The active board
remains unchanged and the two active USB3 footprints remain `NOT_VERIFIED`.

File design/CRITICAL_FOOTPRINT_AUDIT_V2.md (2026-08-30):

# Critical footprint audit v2

Date: 2026-08-20

## Decision

The audit is **not a fabrication signoff**. The project-local footprints are structurally parseable, but several are synthetic placement-study footprints and the manufacturer land patterns have not all been matched to released drawings. No critical item is labelled `LIBRARY_ONLY`; unresolved items are explicitly `UNRESOLVED` rather than being promoted by assumption.

## Audit method

Each footprint was inspected in the KiCad source and compared with the manufacturer's public product page, datasheet/specification, or released drawing where available. The Amphenol CDN returned HTTP 403 to direct command-line downloads on this host, so the official URLs are preserved in `references/manufacturer/MANUFACTURER_RESOURCES_MANIFEST.md`; the PDFs were read through the official web publication where text extraction was available. A blocked download is not treated as a verified land pattern.

## Critical items

| Design item | MPN / local footprint | Local structural observation | Manufacturer evidence | Confidence |
|---|---|---|---|---|
| SXM2 receptacle J1 | Amphenol `74221-101LF` / `SXM2_74221-101LF` | 400 pads, 40×10 array, 1.27 mm nominal pitch, 0.64 mm circular pads; local footprint is a placement-study reconstruction | Official product/spec confirms 400-position 4 mm MEG-Array receptacle, 1.27 mm grid, 0.45 A/contact; the released GS-12-100 spec also defines its stated all-contact/single-contact test cases. Official drawing/app-spec links are preserved but the exact land-pattern/mask/paste/orientation match is not locally captured | **UNRESOLVED** |
| CM5 carrier connectors J2/J3 | Amphenol `10164227-1004A1RLF` / `CM5_1004` and embedded A/B variants | 100-position connector geometry is represented twice; local combined study footprint has 200 signal pads | Official CM5 datasheet specifies 100-pin connectors and this MPN as 4.0 mm stack height with 2.5 mm underneath clearance; the exact released Amphenol land pattern is not yet overlaid against the local footprint | **DATASHEET_DERIVED / RELEASE CHECK OPEN** |
| 12 V headers J3/J4 | Molex `39301082` / `MiniFitJr_8_RA` | corrected to 8 through-hole pads on 4.2 mm pitch, 12.6×4.2 mm contact-center rectangle; drill, shroud, locator, courtyard, and pin-1 orientation are still not matched to the released drawing | Official Molex page confirms 8 circuits, two rows, right-angle, polarized/shrouded, 4.20 mm pitch, 13 A/contact | **DATASHEET_DERIVED / RELEASE CHECK OPEN** |
| Cable housing | Molex `39012085` | no separate PCB footprint | Official Molex page confirms 8-circuit, two-row, 4.20 mm mating pitch; cable assembly still requires pin-1 keying review | **DATASHEET_DERIVED** |
| CM5 buck U1 | TI `TPSM63606RDLR` / `TPSM63606` | local 20-pad module footprint, 0.5 mm pad pitch, thermal/layout study footprint; schematic now references the local footprint | TI datasheet and reference layout are the authority; pad land, paste segmentation, exposed thermal area, and via pattern must be checked against the current datasheet revision before routing | **DATASHEET_DERIVED** |
| Ideal-diode controllers U2/U3 | TI `LM74700QDBVRQ1` / local `LM74700_DBV` available | local footprint has six pads; schematic uses the KiCad SOT-23 library footprint and needs one final library-vs-datasheet match | TI DBV package drawing is the authority; no manufacturer drawing locally preserved | **DATASHEET_DERIVED** |
| Protection MOSFETs Q1/Q2 | TI `CSD19536KCS` / local `CSD19536KCS_TO220` | three through-hole pads represented | TI package drawing and pinout are available; heatsink/assembly clearance not yet manufacturer-matched | **DATASHEET_DERIVED** |
| Fuse holders F1/F2 | Littelfuse `178.6165.0001` | study footprint is a generic two-pad holder outline | Manufacturer holder/fuse drawings and current interrupt/inrush selection not matched | **UNRESOLVED** |
| PCIe AC capacitors C1/C2 | Murata `GRM21BR71H224KA01#` | 0805 schematic footprint; two 220 nF coupling parts | Murata MPN/package authority is recorded; final DC-bias/SI and assembly land pattern still needs release check | **DATASHEET_DERIVED** |
| Buck capacitors C3–C6 | TDK/Murata selected MPNs | schematic references were corrected to installed KiCad `C_1206_3216Metric` for C3/C4 and `C_1210_3225Metric` for C5/C6 | component package families are consistent with selected MPN naming, but final vendor land/courtyard check remains | **DATASHEET_DERIVED** |
| Fan/pump J5–J7 | Molex `22-23-2041` intent / embedded `Fan_2x2_2.54mm` study footprint | 4-pin 2.54 mm concept; local library file is not present under that name | Standard fan pinout is known; exact selected MPN footprint is not yet matched to manufacturer drawing | **UNRESOLVED** |
| UART J8 | JST `B4B-PH-K-S` / `JST_PH_4` | local 4-pin study footprint | JST part/land pattern not independently matched in this phase | **UNRESOLVED** |
| Ethernet/USB J9 | study `USB3_HOST` | board contains a placement-study connector, not a frozen connector MPN | no selected manufacturer part | **UNRESOLVED** |

## Amphenol SXM2-specific finding

The local `74221-101LF` footprint passes the coarse structural checks: 400 pads exist, the pad centers are on a 1.27 mm grid, and the 40×10 naming spans the expected connector array. That is not equivalent to manufacturer land-pattern verification. The local pad diameter, solder-mask margin, paste aperture strategy, courtyard, and A1/orientation convention remain unverified against the Amphenol drawing. The official [MEG-Array GS-12-100 specification](https://cdn.amphenol-cs.com/media/wysiwyg/files/documentation/gs-12-100.pdf) supplies contact-performance test conditions, not a substitute for the part-specific land-pattern overlay. Because the connector is hidden BGA-style after reflow, this is a routing blocker.

## Molex correction

The previous local Mini-Fit study footprint had a 4×2 pad arrangement spread over 12.6×12.6 mm, inconsistent with Molex's official 4.20 mm two-row pitch. The local and embedded placement footprints were corrected to a 4×2 array at 4.20 mm pitch, with the 39301082 MPN in the local value. The contact-center geometry is now consistent with the official page, but exact drill, locator, shroud, and pin-number orientation still require the released Molex drawing.

## Corrections made in this phase

- The schematic and placement PCB now identify the selected buck footprint as
  `PiSXMe:TPSM63606`; the previous PCB-only `TI_RDL_20_5x5.5mm` name was a
  stale study identifier.
- The SXM2 audit now treats K19 as an unresolved auxiliary/pull-up contact,
  not GND, because the preserved reference schematic and article show a local
  +3V3 pull-up network.
- The Mini-Fit study footprint was corrected to the official 4.20 mm two-row
  contact geometry, but is not yet an assembly release footprint.

## Signoff gate

`74221-101LF`, the CM5 fine-pitch connectors, the fuse holders, fan headers, and the Ethernet/USB study connector are not yet manufacturer-verified. Do not route or release this board until each `UNRESOLVED` item is replaced by an approved manufacturer land pattern and the KiCad footprint is checked against it.

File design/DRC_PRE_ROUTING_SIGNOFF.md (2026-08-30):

# DRC pre-routing signoff — modular USB-C I/O revision

Date: 2026-08-21  
Decision: **PASS — ZERO GENUINE PRE-ROUTING BLOCKERS**

Receipt: `validation/DRC_PRE_ROUTING_RECEIPT.md`  
Current board: `pisxme/PiSXMe.kicad_pcb`

The lock-free KiCad 10.0.5 pass reports 36 warnings, all
`lib_footprint_issues` caused by the isolated CLI configuration not enabling
the project-local `PiSXMe` nickname. It reports zero geometric errors,
zero courtyard overlaps, zero clearance/pad overlaps, zero solder-mask
bridges, zero silkscreen violations, and zero unconnected items.

The generated placement study remains deliberately unrouted:

- tracks: 0
- vias: 0
- copper zones: 0

The three USB-C receptacles are outside the cooler/backplate contract and the
PCIe corridor. The USB revision therefore adds no pre-routing placement
blocker. Full DRC is required again after controlled-impedance routing,
power copper, and final vendor CAD overlays are introduced.

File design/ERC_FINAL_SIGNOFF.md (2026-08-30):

# ERC final signoff — routed high-speed rework

Date: 2026-08-22  
Decision: **PASS WITH DOCUMENTED TOOL-CONTEXT WARNINGS**

Receipt: `validation/ERC_ROUTED_REWORK_RECEIPT.md`  
Current schematic: `pisxme/PiSXMe.kicad_sch`

| Gate | Result |
|---|---:|
| ERC errors | **0** |
| ERC warnings | **46**, all explained |
| Multiple-net-name findings | **0** |
| Pin-not-connected errors | **0** |
| Dangling no-connect markers | **0** |
| Warnings requiring design change | **0** |

Warning debt is limited to 30 reproducible KiCad CLI local-footprint-library
context warnings and 16 intentional isolated boundary labels. A routed-board
rerun found and corrected the only real violation in the pre-fix copy: J2 pin
104 (`PCIE_nWAKE`) had been left without a no-connect marker while a stale
marker remained at a different coordinate. The corrected marker is at
`(233.68, 121.92)`.

The remaining warning classes are documented in the routed rework receipt and
are not evidence of a missing electrical connection.

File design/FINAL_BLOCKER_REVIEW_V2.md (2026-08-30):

# Final blocker review v2

Date: 2026-08-20
Question: is there any evidence-backed reason that routing now would be
premature?

## Findings

| Area | Hostile check | Result |
|---|---|---|
| KiCad validation | Can ERC/DRC produce machine-readable evidence? | Yes, via lock-free copy; results are not clean (185 ERC warnings, 231 DRC findings). |
| SXM2 pins | Are K18/K19 classifications consistent with the preserved source? | Corrected: K18/K19 are unresolved auxiliary/protection contacts; K19 is no longer incorrectly classified as GND. |
| SXM2 footprint | Is the 400-pad land pattern manufacturer-matched? | No. Coarse pitch/count passes, exact land/mask/paste/orientation/courtyard remains open. |
| contact current | Does the 0.45 A/contact arithmetic fail? | No: 25–27.5 A V100 load distributes to 0.192–0.212 A per 12 V contact and 0.147–0.162 A per ground contact. PCB thermal/current sharing remains open. |
| PCIe topology | Are TX/RX, coupling, REFCLK, reset, and CLKREQ internally consistent? | Yes at contract level. V100 endpoint acceptance and timing remain empirical. |
| V100 sequence | Is there public NVIDIA timing/enable authority? | No. OCP/OEM material supports platform concepts; simple-carrier evidence supports a direct first attempt. Hardware validation remains required. |
| impedance | Is 85 Ω geometry calculated from a real stackup? | Yes, JLC API returned 84.9966 Ω at 5.2 mil / 2.7847 mil. Fab tolerance and rounded release geometry are not yet quote-confirmed, and the official CM5 90 Ω guidance still needs reconciliation with the requested 85 Ω target. |
| footprints | Are all critical footprints release quality? | No. SXM2, CM5 connector, fuse, fan, UART, and I/O study footprints remain open or unresolved. |
| power | Is high-current input fully pin/thermal resolved? | No. The topology is defined, but final LM74700/MOSFET/fuse/bulk implementation and copper are not routed or thermally signed off. |
| placement | Does the corridor remain plausible? | Yes conceptually; the placement PCB still has no production traces, vias, or zones and has DRC placement violations. |

## Why routing remains premature

1. The hidden 400-joint SXM2 connector has not been matched to an official
   land pattern in the local KiCad footprint.
2. ERC warnings and placement DRC errors are observable, reproducible, and not
   all benign.
3. The JLC calculator result is strong routing input but not a final fab
   tolerance/coupon confirmation.
4. K18/K19 and exact V100 power/reset sequence are still module-validation
   questions. The corrected audit prevents a wrong K19-to-GND connection but
   does not prove that leaving both contacts NC is safe.
5. Several assembly-critical footprints are still study geometry.

## Review result

There is an evidence-backed reason to defer routing. The correct status is
**NOT_READY_FOR_ROUTING**.

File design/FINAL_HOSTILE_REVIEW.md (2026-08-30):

# Final hostile electrical/manufacturing review

## Findings

- **SXM2:** lane-0, REFCLK, PERST#, 12 V, and ground identities are sufficiently mapped for a contract, but the public source is reverse-engineered and K18/K19 remain unresolved.
- **PCIe:** TX/RX direction and CM5 pin identities are coherent. The clock is common-clock and direct. V100 endpoint acceptance of CM5 SSC/clock-management behavior is still a bring-up risk.
- **AC coupling:** the old capacitor MPN was wrong by three orders of magnitude; it is a confirmed design issue and must be corrected before schematic release.
- **CLKREQ#:** the local ground strap makes CM5 request the clock continuously, but it does not prove V100 low-power compatibility. Firmware must initially disable clock power management/ASPM.
- **PERST#:** direct connection is reasonable as a topology, but timing and voltage-domain behavior are not experimentally verified for the V100 module.
- **Power:** the prior connector MPN was wrong; the high-current schematic is still no-pin/architectural in places. This alone prevents routing readiness.
- **Buck:** the prior custom TPSM63606 symbol omitted or misrepresented pins. VIN1/VIN2, VLDOIN, VCC, RT, PG, EN/SYNC, AGND, PGND, and SW must be corrected before ERC can mean anything.
- **Manufacturing:** real six-layer candidates exist, but the current geometry is not a fab-returned impedance result. The 74221-101LF and 0.4 mm CM5 connectors need DFM/X-ray review.
- **Mechanics:** the cooler-agnostic and backplate contracts remain compatible with adjacent CM5 placement in concept, but the exact assembly collision model is not a reason to relax electrical signoff.

## Disposition

No production routing should start from the current schematic/PCB. Correct the component MPNs and pin-level symbols, hydrate the project, rerun ERC/DRC in KiCad, obtain the fab-returned stackup/geometry, and repeat the review.

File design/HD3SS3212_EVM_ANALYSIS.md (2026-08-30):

# HD3SS3212 EVM analysis

Date: 2026-08-23  
Source: `references/usb3/TIDA-00987/HD3SS3212EVM-user-guide.pdf`, TI product
documentation, and the HD3SS3212 datasheet.

## What the EVM isolates

The EVM uses SMP connectors for the high-speed A/B/C interfaces rather than a
reversible Type-C receptacle. This removes the Type-C A/B contact fanout from
the experiment and exposes the preferred mux package treatment directly.

The user guide specifies:

* equal-length signal traces of 1119 mil;
* 50-ohm single-ended trace intent for the SMP environment;
* equal calibration-trace length so calibration fixtures do not dominate the
  measurement;
* 220 nF capacitors on B/C by default and a 0-ohm path on A in the EVM setup,
  because the mux requires the appropriate biasing arrangement.

## What the EVM does not prove

The acquired guide does not include an editable KiCad/Altium PCB source or
full Gerber package. It therefore does not provide a second independently
measured 0.5 mm Type-C fanout geometry. It is strong evidence for the mux
being a transparent high-speed device and for disciplined equal-length
calibration routing, but not a numeric source for PiSXMe’s local escape rule.

## PiSXMe lesson

Use the EVM as a package/measurement precedent:

1. keep the A/B/C paths electrically symmetric where they are intended to be
   compared;
2. do not place coupling capacitors on both sides without considering the
   mux biasing requirement;
3. accept a symmetric layer transition if needed rather than creating an
   asymmetric P/N transition;
4. keep the fine-pitch package region short and transition to the intended
   main-route geometry quickly.

This supports a coupon gate, not automatic authorization to use the EVM’s
50-ohm SMP trace value on the PiSXMe USB3 route.

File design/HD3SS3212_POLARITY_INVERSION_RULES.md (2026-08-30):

# HD3SS3212 polarity-inversion rules

Date: 2026-08-23  
Authority: [HD3SS3212 datasheet](https://www.ti.com/lit/ds/symlink/hd3ss3212.pdf)
and TI TIDA-00987 documentation.

## Datasheet rule

The HD3SS3212 tolerates differential polarity inversion on all differential
signals of Ports A, B and C. The critical constraint is relational: for a
selected channel, the polarity presented on Port A must be maintained
consistently on the corresponding B/C paths. In other words, if the A-side
signal is inverted for a channel, the corresponding B and C paths must use the
same inversion relationship. The mux is otherwise a transparent SuperSpeed
switch; no USB protocol conversion is involved.

The device data sheet also makes the Port-A-versus-Ports-B/C relationship
explicit: a polarity inversion is legal on the differential channels, but the
same polarity relationship must be maintained across the selected path. This
does not mean that arbitrary B/C lane reassignment is free; B/C selection is
still controlled by `SEL`. PiSXMe keeps the existing B/C branch identities and
only remaps P/N within each corresponding channel.

## Design consequences

* A P/N swap may be used to avoid a physical crossover at the mux, ESD array or
  Type-C receptacle.
* A swap must be applied to the complete selected channel relationship, not to
  a single isolated conductor.
* The CM5 does not need a software setting to know about the physical swap.
  USB3 polarity handling is part of the electrical path.
* USB2 D+/D− is separate and is not changed by a SuperSpeed P/N remap.
* The remap does not authorize crossing the TX and RX channels or changing the
  selected A/B/C channel topology. It only changes differential polarity.
* ESD devices remain shunt protection devices. A physical trace-through
  arrangement around/through the footprint must not be represented as a
  series electrical connection to an NC pin.

## PiSXMe application rule

PiSXMe will use the following trial rule: keep one polarity relationship for
each HD3SS3212 channel across A and B/C, make any swap visible in the
schematic/net map, and validate the resulting physical fanout on disposable
copies before changing the active design. This is a routing optimization, not
a license to hide a net swap in PCB-only pad assignments.

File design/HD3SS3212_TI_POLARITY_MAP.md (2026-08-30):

# HD3SS3212 polarity map in TI TIDA-00987

Date: 2026-08-23  
Primary evidence: `references/usb3/TIDA-00987/TIDRND0A-schematic.pdf`,
`TIDUC55A-design-guide.pdf`, and `HD3SS3212-datasheet.pdf`.

The table below is transcribed from the TI schematic. `P/N` in a TI net name
describes the intended USB signal identity; it is not a requirement that every
physical mux pin be approached in the nominal visual order.

## Mux mapping

### Direct TI design-guide observation

TI's design guide identifies the apparent polarity mismatch as deliberate. In
its HD3SS3212 table, the B0/C0 TX paths are named with the opposite polarity
from the nominal mux pin suffixes, and the corresponding A-side TX polarity is
switched as well. This is the precise mechanism used to keep the mux-to-ESD-
Type-C fanout straight; it is not a transcription error. The B1/C1 RX paths
retain the corresponding non-inverted relationship.

| HD3SS3212 port/pin | TI net | Physical Type-C signal | TI polarity relative to nominal name | Corresponding relationship |
|---|---|---|---|---|
| A0P pin 3 | `SSRX_P` | host/device receive path | normal | A0 vs B0/C0 is consistent |
| A0N pin 4 | `SSRX_N` | host/device receive path | normal | same |
| A1P pin 7 | `SSTX_N` | host/device transmit path | intentionally inverted | A1 inversion is also represented on the B/C TX paths |
| A1N pin 8 | `SSTX_P` | host/device transmit path | intentionally inverted | same |
| B0P pin 19 | `SSTX2_N` | Type-C B orientation TX | intentionally inverted | matches A1 TX polarity relationship |
| B0N pin 18 | `SSTX2_P` | Type-C B orientation TX | intentionally inverted | same |
| B1P pin 17 | `SSRX2_P` | Type-C B orientation RX | normal | matches A0 RX polarity relationship |
| B1N pin 16 | `SSRX2_N` | Type-C B orientation RX | normal | same |
| C0P pin 15 | `SSTX1_N` | Type-C A orientation TX | intentionally inverted | matches A1/B0 TX relationship |
| C0N pin 14 | `SSTX1_P` | Type-C A orientation TX | intentionally inverted | same |
| C1P pin 13 | `SSRX1_P` | Type-C A orientation RX | normal | matches A0/B1 RX relationship |
| C1N pin 12 | `SSRX1_N` | Type-C A orientation RX | normal | same |

## Type-C/ESD correspondence

TI’s J3 labels are:

| Type-C pins | TI signal |
|---|---|
| A2/A3 | `SSTX1_P/N` |
| A10/A11 | `SSRX2_N/P` |
| B2/B3 | `SSTX2_P/N` |
| B10/B11 | `SSRX1_N/P` |

The two TPD4E05U06 DQA arrays use the signal pads as follows:

| TI ESD device | D1+ pin 1 | D1− pin 2 | D2+ pin 4 | D2− pin 5 |
|---|---|---|---|---|
| U5, Type-C B branch | `SSTX2_N` | `SSTX2_P` | `SSRX2_P` | `SSRX2_N` |
| U6, Type-C A branch | `SSTX1_N` | `SSTX1_P` | `SSRX1_P` | `SSRX1_N` |

The TPD4E05U06 NC pins 6/7/9/10 are not electrically connected to those
signals. They are available to permit a straight physical trace path through
the package area when the layout uses them as a pass-through corridor.

## B/C selection constraint

The HD3SS3212 select input still defines which side is selected: Port B for
the low select state and Port C for the high select state. The polarity study
therefore does **not** swap the B and C branch identities. It only changes the
P/N relationship within a differential channel. A B/C branch swap would also
require an explicit select/control change and is outside this study.

## What is being reused

PiSXMe does not copy TI net names or coordinates. It reuses the validated
electrical principle: choose the polarity relationship across A versus B/C so
the physical branch order is straight, then make the remap explicit in the
schematic. The PiSXMe channel assignment and endpoint geometry are different,
so its optimized mapping is documented separately and remains trial-pending.

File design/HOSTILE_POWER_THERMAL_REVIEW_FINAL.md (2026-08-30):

# Hostile power / thermal review after high-speed studies

Date: 2026-08-22

## Findings

| Attack | Result |
|---|---|
| 12 V branch rating | Two 15 A protected branches are adequate for the nominal arithmetic only when both are present; the 13.75 A stress branch leaves little margin. |
| SXM2 contacts | 0.192/0.212 A average per +12 V contact is below the 0.45 A Amphenol test rating, but sharing and spreading are unmeasured. |
| distributed feed | 13 feed transitions at 1.92/2.12 A idealized average are plausible; 26 vias imply two per feed, but local current crowding remains possible. |
| narrowest copper | `/VPROT_12V` contains short 0.25 mm pad-escape segments. They are the controlling local bottlenecks. |
| protection | LM74700/MOSFET and fuse dissipation remain unmeasured and can dominate local heating. |
| CM5/USB buck | Both TPSM63606 regions have a 6 A rating and local support routing; actual loss/airflow/transient performance is unmeasured. |
| high-speed interaction | No active power edit was made during this phase; the baseline high-current manifolds remain outside the intended PCIe corridor. |

## Decision

The power architecture is plausible for a monitored Rev-A bring-up, with
documented current/thermal risk. It is not enough to override the high-speed
blockers or to claim fabrication readiness. The first prototype would require
temperature measurements at the SXM2 connector field, fuse terminals,
protection MOSFETs, and both regulator modules under sustained load.

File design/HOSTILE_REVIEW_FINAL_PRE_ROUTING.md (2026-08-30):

# Hostile review — final pre-routing gate

Date: 2026-08-21
Question: is there a concrete evidence-backed reason not to route the board?

## Findings

| Attack area | Result | Evidence |
|---|---|---|
| SXM2 pad count/orientation | PASS | active J1 is the 400-pad Amphenol-derived model; A1, 1.27 mm pitch, 0.635 mm pad, 0.150 mm mask margin, no pad vias, and rework courtyard are recorded. |
| CM5 connector orientation | PASS | official 10164227 drawing-derived two-row 100-pad model is active on J2A/J2B; both are deliberate 90° placements, not mirrored. |
| TX/RX and polarity | PASS AS REV-A BASIS | standard endpoint contract remains internally consistent: CM5 TX→V100 RX and V100 TX→CM5 RX; V100 TX has two external 220 nF capacitors. |
| REFCLK/PERST/CLKREQ | PASS AS REV-A BASIS | direct common-clock REFCLK, direct active-low PERST#, local CM5 CLKREQ# assertion; no mandatory V100-side CLKREQ or WAKE route identified. |
| Impedance definition | PASS | live JLC calculation for JLC06161H-7628 gives 90 Ω at W1 0.13208 mm and S1 0.085328 mm; independent coated calculation is 90.14944 Ω. |
| ERC | PASS WITH EXPLANATIONS | 0 errors, 184 warnings; 0 multiple-net names; every remaining warning is grouped and documented as tool limitation or intentional boundary labeling. |
| DRC placement | PASS | 0 errors, 0 courtyard/clearance/silk/unconnected findings; 20 local-library warnings only. |
| Power path | PASS FOR ROUTING | contact-current arithmetic remains below the Amphenol all-contact test rating under nominal and 330 W V100 scenarios; copper spreading and thermal design remain routing tasks. |
| Cooler/backplate contract | PASS | no fixed placement violates the published topside or underside reserved volume; final cooler remains user-defined. |
| Manufacturability | PASS FOR ROUTING | critical footprints are manufacturer-verified or datasheet-derived-and-checked; hidden joints/X-ray and selective solder are production controls. |

## Residual risks, not blockers

- V100-specific power sequencing is supported by working-carrier empirical
  evidence and the standard-endpoint policy, but has not been exercised on the
  user's hardware.
- Private NVIDIA timing documentation is unavailable; Rev-A uses conservative
  common-clock/reset behavior and records that limitation.
- U1 thermal-via/paste implementation and high-current copper geometry still
  require the next routing phase.
- KiCad CLI reports 12 PCB footprint-link warnings and 12 corresponding
  schematic link warnings because of project-local library resolution in the
  isolated CLI context. These are reproducible and explicitly classified.

## Decision

No concrete unresolved design defect was found. The board is ready for
controlled-impedance routing, subject to the explicit “no Gerbers/order” stop
condition of this phase.

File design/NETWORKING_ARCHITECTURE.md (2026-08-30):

# Networking architecture

Native RJ45 is omitted from PiSXMe Rev A. FAST B is reserved as a native CM5 USB3 host port for a commodity USB 2.5GbE adapter.

## Why this is practical

USB3 Gen1 provides a 5Gbps physical link, enough headroom for a 2.5GbE adapter after protocol overhead. Real throughput is adapter-, host-load-, driver-, and enclosure-dependent; the design does not promise line-rate 2.5GbE.

Common adapters use Realtek RTL8156/RTL8156B-class or ASIX 2.5GbE USB3 controllers. Linux support is generally available in modern kernels, but the deployed CM5 image must include the relevant driver and firmware behavior. Adapter thermals and link negotiation remain external deployment concerns.

FAST B has its own CM5 USB3 port 1 pins. FAST A can simultaneously host storage on USB3 port 0 without sharing a single USB hub upstream. The V100 still uses the independent PCIe Gen2 x1 link.

## Mechanical consequence

Removing RJ45 avoids magnetics, high-speed Ethernet routing, a large board-edge connector, and a fixed enclosure cutout. Builders may use direct onboard USB-C, a short panel-mount USB-C extension, or an internal adapter.

The board does not require Wi-Fi. A CM5 SKU with optional Wi-Fi can be used, but Ethernet remains an explicit external USB accessory.

Confidence: CM5 USB-port independence is official Raspberry Pi documentation; practical 2.5GbE compatibility is an ecosystem/driver conclusion and should be tested with the chosen adapter during deployment.

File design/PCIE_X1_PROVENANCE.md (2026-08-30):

# PCIe x1 clean-room provenance

Status: observation record and design-provenance guardrail. This file documents what was studied and what may be used as evidence; it does not grant rights to redistribute third-party files.

## Clean-room rule

The future V100-to-CM5 board must start from a new, blank KiCad project. No PCB file from a routed commercial, OSHWHub, or reverse-engineered carrier may be imported, cropped, mechanically transformed, used as a tracing canvas, or edited into the project. No distinctive bend, meander, via field, component placement, or substantial layout section may be reproduced.

The design team may use the references to extract:

- logical connectivity and signal naming;
- observed connector identity and mechanical datums;
- high-level layer, plane, power-zone, and manufacturing lessons;
- publicly documented CM5 electrical requirements;
- independent physical constraints for our own one-lane board.

The resulting x1 architecture deliberately changes the problem: no PCIe card edge, one lane, CM5 adjacent/under the former edge region, and a newly derived corridor.

## Evidence classes

| label | meaning | allowed design use |
|---|---|---|
| OBSERVED | read directly from a source file, live KiCad state, or image | quote as an observation; do not treat as a passing design |
| AUTHOR CLAIM | statement by an author/seller/project maintainer | record with attribution; never use alone as an electrical guarantee |
| INFERRED | conclusion derived from observations | use as a hypothesis, marked for validation |
| SPEC-DERIVED | official Raspberry Pi, PCI-SIG, or fab documentation | use to set requirements, subject to endpoint compatibility |
| UNKNOWN | insufficient evidence | do not silently fill with a reference-board assumption |

## Primary SXM2 source

| source | acquisition/pin | what was used | what was not used |
|---|---|---|---|
| [bbenchoff/SXM2toPCIe](https://github.com/bbenchoff/SXM2toPCIe) | immutable clone at `/Users/Cooper/Documents/ChatGPT/sxm2/references/SXM2toPCIe`; commit `3173b02c085218d66c4a2a9e5492853fb53ee097`; acquired 2026-08-20 | J2/J3 connector identity, source pin map, net names, partial lane landmarks, declared stackup, KiCad parse/DRC/ERC evidence | no PCB geometry, no trace coordinates, no via placement, no component placement, no claim that its copper is a complete high-speed route |
| [Benchoff reverse-engineering article](https://bbenchoff.com/pages/SXM2PCIe.html) | accessed 2026-08-20 | author-reported SXM2 pin table, `PERST#` E18, populated single Meg-Array, absent NVLink connector, conventional slot presence tie, power/fan observations | no NDA material, no unverified undocumented pin behavior treated as fact |
| [l4rz field report](https://l4rz.net/running-nvidia-sxm-gpus-in-consumer-pcs/) | accessed 2026-08-20 through Benchoff link | independent evidence that commercial SXM2-to-PCIe adapters have been operated with V100-class modules; high-level connector/power context | no layout copying; photographs are not measurements of our board |

The primary KiCad source was opened and inspected through KiCad 10.0.5 in a separate working copy. The live bridge reported 38 footprints, 1,104 pads, 129 tracks, 7 vias, 5 zones, 429 graphics, 558 nets, and four copper layers. DRC reported 73 violations and 285 unconnected items; ERC reported 472 violations. These are **OBSERVED** properties of that source and remain unmodified.

The source's lane-0 route is incomplete: only partial edge/capacitor-row copper exists. Its 0.1016 mm/0.127 mm `PCIe_Diff` class is not an impedance proof, has no explicit length/skew/impedance constraints, and does not consistently match post-coupling net names. This is why the source is a pinout/mechanical/topology reference, not a known-good high-speed layout.

The source repository has no root `LICENSE` file in the pinned commit. Benchoff's article states that the hardware files are WTFPL 3.0 and the article text is CC-BY-SA-4.0; the embedded SnapMagic model file has separate terms. This project preserves the clone as immutable reference material and does not redistribute or modify its files in the new design.

## Additional SXM2 carrier evidence

| source | status | extracted fact | classification and limit |
|---|---|---|---|
| [LiuXinyu12378/SXM2_to_PCIE_adapter](https://github.com/LiuXinyu12378/SXM2_to_PCIE_adapter) | shallow clone at `/Users/Cooper/Documents/ChatGPT/sxm2/references/LiuXinyu12378-SXM2_to_PCIE_adapter`; commit `27dd1229889f4f0c03324b419931d2d466fccde4`; no license file found | README claims V100/P100 compatibility, x16 operation, 3×8-pin plus PCIe power with theoretical 525 W, and offers 4-layer and 6-layer ENIG boards; photographs show high-current connectors and a separate power module on one revision | README performance/power claims are **AUTHOR CLAIM**; photographs are **OBSERVED** high-level placement/power evidence only; no route geometry or coordinates used |
| [OSHWHub routed/tested carrier](https://oshwhub.com/chenrunyu/sxm2-pcie-adapter-turbo-fan-vers) | direct OSHWHub fetch was unavailable with HTTP 403; reviewed the linked [LCSC article](https://www.szlcsc.com/info/16304.html) and its photographs | article states P100/V100/A100 support, 300 W+ power, active cooling, NVLink extension, TPS56624x regulator, LMK00334 level converter; photographs show a real fabricated board | performance and topology statements are **AUTHOR CLAIM**; image observations are coarse and not layout measurements; no source geometry imported |
| [current commercial six-layer listing](https://www.ai-cooling.com/?product=198) | seller page accessed 2026-08-20 | seller claims dual 6+2-pin power, 300 W tested without downclocking, six-layer impedance optimization, and zero signal loss | **AUTHOR CLAIM** only; not used to set trace width, impedance, or current capacity |

These routed/fabricated references are corroboration that power delivery, cooling, and controlled high-speed construction are real design concerns. They are not templates for our board.

## Official CM5 sources

| source | use | classification |
|---|---|---|
| [Raspberry Pi CM5 datasheet](https://datasheets.raspberrypi.com/cm5/cm5-datasheet.pdf) | PCIe Gen2 host limitation; optional/unsupported Gen3; TX/RX crossing for direct IC connection; 220 nF AC-coupling ownership; 90 Ω; 0.1 mm within-pair match; required `CLKREQ#` and `PERST#`; `WAKE#` software limitation; CM5 pins 102, 104, 106, 109–124; module mechanics | **SPEC-DERIVED** |
| [Raspberry Pi CM5IO datasheet](https://datasheets.raspberrypi.com/cm5/cm5io-datasheet.pdf) | official carrier block diagrams, M.2 sideband topology, 5 V CM5 power context, and official reference-design status | **SPEC-DERIVED / OBSERVED** |
| Raspberry Pi official CM5IO revision-2 KiCad archive, acquired 2026-08-20 from the [official design-files page](https://pip.raspberrypi.com/categories/1098-design-files) | preserved locally at `/Users/Cooper/Documents/ChatGPT/sxm2/references/RaspberryPi-CM5IO-rev2`; ZIP SHA-256 `48b14a6757b0edc0ac110331445f35a4212b5ce432bdcec6605c99431b59496b`; inspected `CM5IO.kicad_pcb`, `CM5IO.kicad_pro`, and PCIe schematics | official 4-layer example uses 1.6 mm board data and a `90R` class with 0.147 mm width, 0.253 mm differential gap, 0.45/0.20 mm vias; its M.2 schematic connects `CLKREQ#`, `WAKE#`, `PWR_EN`, and `PERST#` to CM5. These are **OBSERVED official reference-design facts**, not copied geometry |

KiCad CLI 10.0.5 successfully parsed the official CM5IO schematic and exported a netlist. It also parsed the board and produced a DRC report with 67 violations and 0 unconnected items in this environment. Those DRC results are not a cleanliness claim about the official design and were not used to change it.

The official CM5IO design archive is kept outside the outer Git history and ignored as a large reference. Its local presence does not change the clean-room rule.

## Official PCIe and fabrication sources

| source | use | classification |
|---|---|---|
| [PCI-SIG PCIe 2.0 FAQ](https://pcisig.com/faq?field_category_value%5B%5D=pci_express_2.0) | 2.5/5.0 GT/s backward-compatible Gen2 behavior | **SPEC-DERIVED** |
| [PCI-SIG PCIe generation FAQ](https://pcisig.com/faq?field_category_value%5B%5D=pci_express_3.0) | 8.0 GT/s Gen3 context and manufacturability tradeoff | **SPEC-DERIVED** |
| [JLCPCB impedance-calculator guide](https://jlcpcb.com/help/article/user-guide-to-the-jlcpcb-impedance-calculator) | official input model: finished thickness, copper weights, target impedance, pair spacing, layer, and reference planes | **SPEC-DERIVED** |
| [JLCPCB controlled-impedance stackup reference](https://jlcpcb.com/impedance) | published 4-layer and 6-layer impedance-control stackup families | **SPEC-DERIVED**, subject to current fab quotation |
| [PCBWay standard layer-stack reference](https://www.pcbway.com/pcb_prototype/What_is_layer_stack_up.html) | alternative mainstream-fab stackup comparison | **SPEC-DERIVED**, subject to current fab quotation |

No production trace width is taken from a search result, photograph, or reference PCB. The final width/gap will be generated from the selected fabricator's current laminated stackup and impedance coupon request.

## Independent derivations recorded in this phase

1. **Lane 0 candidate:** lane 0 is the leftmost/topmost and shortest natural route to the former edge region in the source geometry. This is an **INFERRED** placement convenience, not a claim that the source lane is routed or electrically validated.
2. **CM5 placement:** adjacent CM5 is provisionally preferred for access, cooling, and assembly; underside CM5 remains plausible if the 4.0 mm connector/2.5 mm underside-clearance option and V100 cooler envelope permit it. **INFERRED / UNKNOWN.**
3. **Six layers:** six layers are recommended primarily for the 300 W-class power distribution and clean ground planes, not because one short Gen2 lane needs x16-style escape density. **INFERRED.**
4. **No redriver/retimer:** a short Gen2 x1 channel does not presently justify an active repeater. Add one only after SI/bring-up evidence. **INFERRED.**

## Forbidden provenance shortcuts

- Do not copy the Benchoff, OSHWHub, Liu, l4rz, or seller-board PCB into a new project.
- Do not crop the former card-edge area and call it the x1 starting layout.
- Do not reproduce distinctive commercial bends, meanders, via rows, fanouts, or power placement.
- Do not infer that multiple commercial boards independently prove a detail if they may share one source design.
- Do not call a seller's “zero signal loss,” “300 W tested,” or “stable” statement a measured SI/current rating.
- Do not call the pinned Benchoff PCB a completed routed reference; live DRC and track evidence contradict that interpretation.

## Provenance gate for the next phase

The next KiCad phase may create a new schematic and mechanical study only after this document and [PCIE_X1_DERIVED_REQUIREMENTS.md](PCIE_X1_DERIVED_REQUIREMENTS.md) are accepted as the design authority. The new layout must be independently generated around the x1 topology, CM5 placement, chosen stackup, and V100 power/thermal constraints.

## Phase 2: interface and mechanical provenance

The official CM5 electrical and mechanical data used for the interface contract were obtained from the [CM5 datasheet](https://datasheets.raspberrypi.com/cm5/cm5-datasheet.pdf), [CM5IO datasheet](https://datasheets.raspberrypi.com/cm5/cm5io-datasheet.pdf), [firmware overlay documentation](https://github.com/raspberrypi/firmware/blob/master/boot/overlays/README), and the [official Raspberry Pi design-files page](https://pip.raspberrypi.com/categories/1096-design-files). The CM5 STEP ZIP was preserved locally at `/Users/Cooper/Documents/ChatGPT/sxm2/references/RaspberryPi-CM5-step/`; its SHA-256 is `2b4d26c6b30607c68099ad60df6fb8b8c8d04e9461f325c7c77dc421d2855005`.

The independent schematic at `/Users/Cooper/Documents/ChatGPT/sxm2/pisxme/PiSXMe.kicad_sch` was created from KiCad's generic blank EuroCard template, not from any SXM2 carrier or CM5IO schematic. The template supplied only the KiCad document container; the interface text, nets, coupling components, local clock-request policy, and power/debug notes were authored for this project. No reference PCB geometry, routed pair, via field, component placement, or restricted layout fragment was imported.

Public NVIDIA data was used only to bound the V100 power/mechanical risk. The [V100 datasheet](https://images.nvidia.com/content/technologies/volta/pdf/tesla-volta-v100-datasheet.pdf) identifies the SXM2 system interface as NVIDIA NVLink and gives a 300 W-class maximum for the SXM2 product; it does not publish the reverse-engineered standalone PCIe clock/sideband contract. That gap is recorded as a bring-up gate rather than filled from commercial geometry.

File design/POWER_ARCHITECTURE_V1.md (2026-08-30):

# PiSXMe power architecture V1

Status: coherent first-schematic power policy, not a released 300 W power design. Copper width, thermal rise, connector derating, fuse curves, and sequencing must be validated before hardware release.

## Recommended input architecture

Use one regulated external 12 V supply feeding two keyed, high-current Mini-Fit-family 8-position connectors (GPU-style dual 8-pin harness arrangement). Molex documents the Mini-Fit family at up to 13 A per circuit depending on the exact terminal, wire, and application conditions; the final connector, crimp, PCB land, temperature, and harness derating remain design inputs. **SPEC-DERIVED family capability:** [Molex Mini-Fit connectors](https://www.molex.com/en-us/products/connectors/wire-to-board-connectors/mini-fit-connectors).

At 300 W, the V100 load is approximately 25 A at 12 V before conversion and transient margin. Splitting the input across two connectors gives a practical contact/current path and avoids obsolete peripheral Molex wiring. A modern 12V-2x6 connector is technically attractive but less convenient for a first prototype and should be reconsidered if the enclosure/harness requires it.

The input chain should be:

```text
dual 12 V connectors
      │
      ├─ branch fusing / current distribution (value TBD by measured inrush)
      ├─ reverse-polarity / ideal-diode protection
      ├─ TVS and input bulk sized to the actual PSU/harness
      ├─ V100 12 V plane + local bulk/ceramic decoupling
      └─ 12 V → CM5 5 V synchronous buck
```

Do not route the input switch node or its high-current return through the PCIe corridor. Keep the bulk-current return adjacent to the SXM2 power contacts and use L2/L5 ground continuity under the high-speed channel.

## CM5 rail

The CM5 datasheet specifies a regulated 5 V input, a monotonic rise, and a design budget accommodating up to approximately 2.5 A on 5 V. **SPEC-DERIVED:** [CM5 datasheet](https://datasheets.raspberrypi.com/cm5/cm5-datasheet.pdf). Use a dedicated 12 V-to-5 V synchronous buck rated for at least 5 A continuous in the final thermal environment, with current limit, soft-start, UVLO, and power-good. The 5 A choice is margin, not a claim that the CM5 consumes 5 A continuously.

Target first-pass budget:

| rail | load assumption | policy |
|---|---:|---|
| V100 12 V | up to 300 W / ~25 A nominal, with transient margin | direct protected distribution; verify actual module power behavior |
| CM5 5 V | up to 2.5 A design envelope plus margin | 5 A buck target; route separately from PCIe corridor |
| CM5 3.3 V / 1.8 V | CM5-generated and limited external loads | do not use as a high-power peripheral rail |
| fans/pump/USB | application-specific | separate switched branches and current monitoring where useful |

The modular USB revision resolves the USB portion of this table: `U16`
provides a dedicated 5V peripheral rail, FAST A/B each have a 1.5A Type-C
source switch, and SERVICE has a 0.5A USB2 current limiter with source/sink
backfeed interlock. See `design/USB_POWER_BUDGET.md`.

CM5 power sequencing follows the datasheet: 5 V rises first, `PMIC_EN`/power control then permits internal rails, with the documented minimum timing relationship. The exact PiSXMe supervisor implementation is still to be selected.

## V100 enable and sequencing

`PCIE_PWR_EN` from CM5 pin 106 goes only to a low-voltage supervisor/control block. It must not directly drive the SXM2 300 W rail. The V100 rail should be enabled after input protection is valid and before CM5 releases `/PERST`; `V100_PWR_GOOD` should be a defined input to the reset policy. Exact V100 enable polarity, current-limit behavior, and module-specific sequencing are **UNKNOWN** and must be established from the actual module or a validated carrier.

## Protection and monitoring

Reserve, but do not freeze values yet:

- input fuses or resettable/current-limited branches;
- reverse-polarity/ideal-diode stage;
- TVS selected for the actual 12 V supply and cable inductance;
- input and SXM2-side bulk capacitors with ripple-current rating;
- CM5 buck UVLO/soft-start/current limit;
- shunt or Hall current monitor on the V100 branch;
- V100 12 V, CM5 5 V, and supervisor power-good test points;
- temperature sensors at the V100 power entry, buck inductor, and board hot spots.

## High-current geometry policy

- Use broad, short copper from both connector branches to the SXM2 contacts.
- Keep switch-node copper minimal and physically far from L1 PCIe/REFCLK.
- Do not place power MOSFET thermal vias or an inductor directly beneath L1 PCIe pairs if they would disrupt the L2 return plane.
- Use multiple ground contacts and stitching around power transitions, but do not punch arbitrary via fences through the high-speed corridor.
- Validate temperature rise with the actual connector, copper weight, plane neck-downs, and enclosure airflow.

## Power blockers

The 300 W figure is an NVIDIA V100 SXM2 maximum-power specification, not proof that a chosen module needs exactly 300 W in this board. **SPEC-DERIVED maximum:** [NVIDIA V100 datasheet](https://images.nvidia.com/content/technologies/volta/pdf/tesla-volta-v100-datasheet.pdf). Before release, measure module behavior, confirm the rail/enable interface, and validate the connector and fuse system under load. The power architecture is therefore coherent enough for a schematic, but not yet a production current rating.

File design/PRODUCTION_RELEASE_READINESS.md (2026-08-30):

# Production release readiness

Date: 2026-08-22  
Board: `pisxme/PiSXMe.kicad_pcb`

## Decision

**NOT_READY_FOR_REV_A_FAB_PACKAGE**

This phase deliberately preserved the routed board after rejecting shorter
PCIe and lower-skew FAST-B trial geometries that introduced real DRC errors.
The current board is therefore not a silently changed release candidate; it
remains the auditable first-pass routed study.

The first production-quality routing pass is materially complete and
reviewable, but the board is not ready to package for fabrication.

## Gate matrix

| Gate | Result | Evidence |
|---|---|---|
| PCIe x1 routed | POOR PHYSICAL ROUTE | `routing/HIGH_SPEED_FINAL_METRICS.md`, `routing/PCIE_REWORK_RECEIPT.md` |
| USB3 FAST-A/B routed | FAST-A reviewable; FAST-B NOT ACCEPTABLE | `routing/HIGH_SPEED_FINAL_METRICS.md`, `routing/USB3_FAST_B_REWORK_RECEIPT.md` |
| 12 V V100 distribution | PASS WITH DOCUMENTED THERMAL RISK | `routing/THERMAL_CURRENT_ANALYSIS.md` |
| CM5/USB power | PASS TO THERMAL REVIEW | power-route receipts and current budget |
| Routed DRC | PASS WITH DOCUMENTED CONTEXT | 0 geometric errors; 54 local-library warnings; 22 remaining intentional connectivity records |
| Routed ERC | PASS WITH DOCUMENTED WARNINGS | 0 errors; 46 explained warnings in `validation/ERC_ROUTED_REWORK_RECEIPT.md` |
| PCB/schematic parity | NOT MACHINE-CLEAN | 321 warnings, including 199 intentional J1 full-connector abstraction records; see `validation/PCB_SCHEMATIC_PARITY_RECEIPT.md` |
| Mechanical contract | PASS | cooler/backplate keepouts remain preserved |
| BOM/CPL/release files | NOT RELEASED | this phase does not generate release Gerbers or send files externally |

## Concrete blockers

1. FAST-B SuperSpeed pair matching and connector-side breakout are not
   sufficiently demonstrated for a conservative USB3 production release.
2. PCIe remains in the project's POOR band: 107--122 mm with two transitions
   per conductor. The fixed J2/cooler relationship must be reconsidered before
   a controlled-impedance production route can be called deliberate.
3. The routed board still contains 22 DRC connectivity records across the
USB shield net, F.Cu GND-zone islands, and USB VBUS zones, plus 54
project-local library warnings. The shared `/NC` net defect is fixed; the
remaining records need a deliberate shield/zone copper disposition rather
than a blanket waiver or treating DRC exit code 0 as a clean release.
4. The 400-pad J1 connector is electrically assigned on the PCB but is
   intentionally abstracted in the schematic; full machine parity must be
   resolved or explicitly waived in the release review.
5. Thermal qualification of the 300 W-class SXM2 feed and regulator regions
   is still a hardware/fab-build validation task.

## Accepted prototype risks

The standard PCIe endpoint assumption, V100 sequence behavior, hidden-joint
reflow quality, and exact cooler implementation remain Rev-A prototype risks.
They are not being represented as proven production facts.

## Next gated work

Rework or field-solve the USB3 layer strategy, rerun the high-speed audit,
rerun KiCad ERC/DRC on the exact board, then regenerate a fabrication-only
package review. Do not order this revision from the current state.

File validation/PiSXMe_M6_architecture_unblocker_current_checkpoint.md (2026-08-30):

# PiSXMe M6 Architecture-Unblocker Current Checkpoint

Date: 2026-08-28

Status: DISPOSABLE STUDIES COMPLETE; M6 NOT PASSED; ACTIVE SOURCE UNCHANGED

## Scope

This receipt supersedes the earlier provisional Ethernet/SATA replan evidence for
current-source parity. The active Rev A schematic and PCB were not modified. No
architecture was promoted and no M7-M10 work was started.

Source basis:

- staged M2 source snapshot: `/private/tmp/pisxme_m6_staged_m2_source.kicad_pcb`
- SHA-256: `b6e7e78ec8fa516eff15bbfda51dd848399073d2d4b47474e1d7e6fbf1a2fc78`
- outline: 240 x 140 mm in the staged M2 snapshot
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

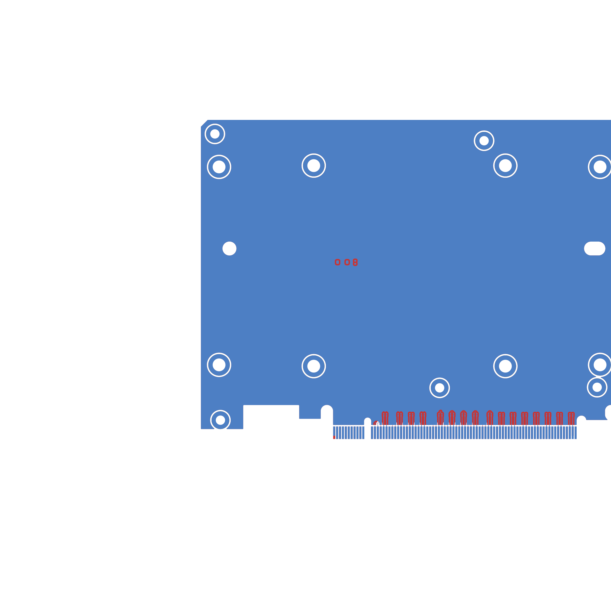
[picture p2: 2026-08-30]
analysis-artifacts/SXMtoPCIe-front.svg.png

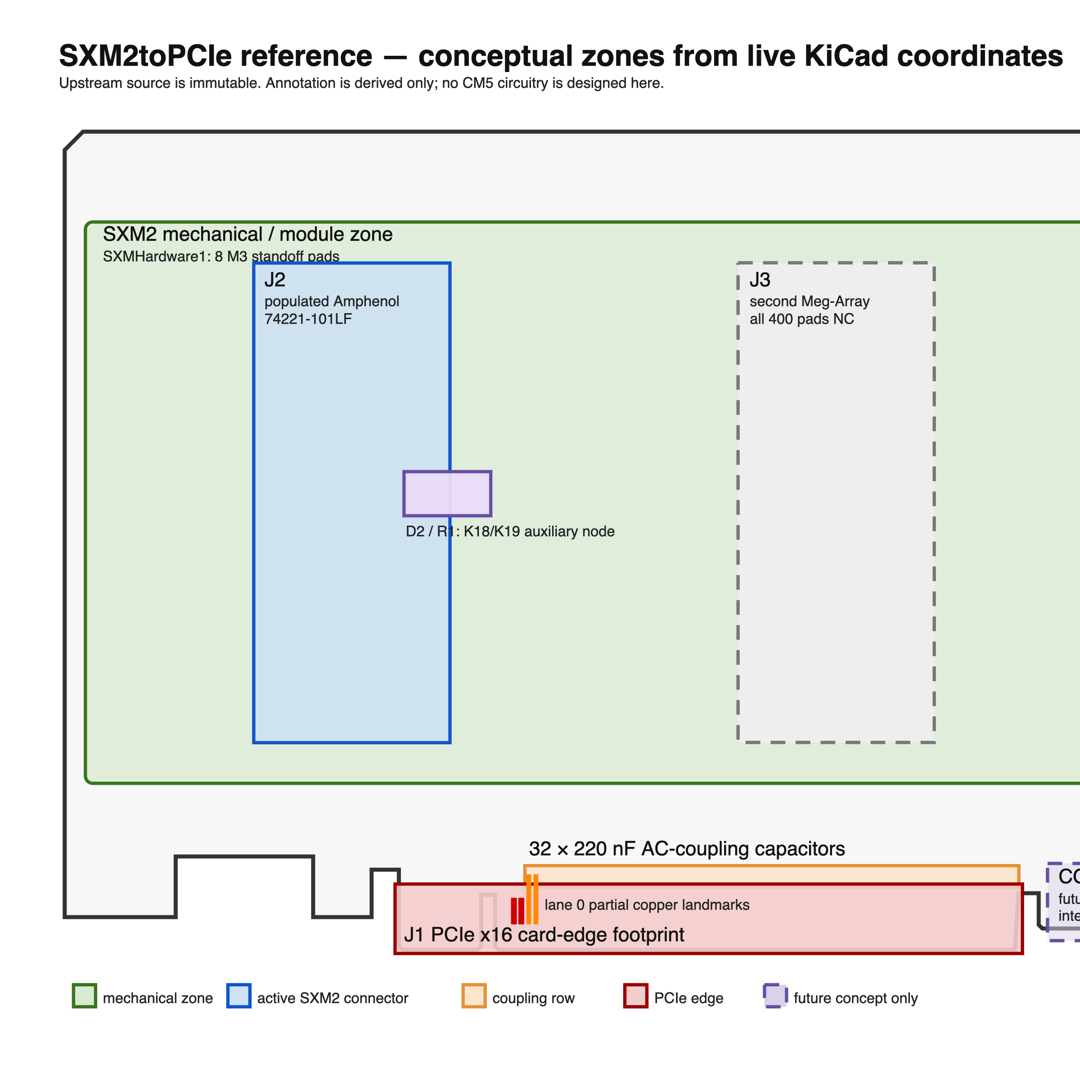
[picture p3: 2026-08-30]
analysis-artifacts/SXM2-reference-zones.svg.png

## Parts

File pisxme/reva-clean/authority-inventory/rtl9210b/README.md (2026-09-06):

# RTL9210B-CG Path-B qualification evidence

Retrieved 2026-09-06 for the isolated Path-B comparison. This directory is
not production CAD and does not replace Path A.

## Evidence retained

| Artifact | Provenance | Use | Limitation |
|---|---|---|---|
| `community-lz1/rtl9210b.pdf` | HynixCJR/LZ-1-Backplane, commit `18444b9d584036ff8e0221d5eacb3fb2a0d3fbd5` | Rev. 1.1 pin, mode, power, timing and package evidence | Community-hosted copy; verify with Realtek before release |
| `community-lz1/RTL9210b_0.kicad_sch` | Same repository | Corroborating complete implementation | Repository labels the PCB WIP; not a production oracle |
| `community-lz1/easyeda2kicad.kicad_sym` | Same repository | Corroborating symbol/pin naming | Requires independent pin audit |
| `community-lz1/QFN-68...kicad_mod` | Same repository | Package geometry cross-check | Incorrectly marked `through_hole`; never reuse unchanged |
| `firmware-tools/README.md` and configs | bensuperpc/rtl9210, commit `265d4727a29e9c443f5ff567107556924c1879c2` | Firmware/config/programming/recovery procedure | Community tools, Windows-only updater, device-specific configs |
| `firmware-tools/*bin` and `RTL9210B_CG_upqi.cfg` | damnnfo/rtl9210b-firmware, commit `c381c0e56ad37ab40d5e56f690417d0942c061d7` | Demonstrates obtainable firmware artifacts | Provenance/licensing and virgin-chip compatibility remain open |

The PDF is the strongest available technical source in this qualification;
the CAD and firmware repositories are corroboration, not manufacturer
authorization. SHA-256 values for retained files are recorded in the
procurement/qualification report and should be regenerated before release.

KiCad 10.0.5 natively exported XML netlists from the retained
`RTL9210b_0.kicad_sch` and `M.2_0.kicad_sch`; the receipts are
`RTL9210B_0.xml` and `M.2_0.xml`. They confirm native parsing and expose the
community schematic's RTL9210B pin/net names and M.2 PEDET contact 69. This
is schematic parse evidence, not a completed PCB or ERC/DRC pass.

The HynixCJR project root was also copied into `community-lz1/root-reference`
with its RTL9210B and M.2 child sheets. KiCad 10.0.5 exported a native root
XML receipt as `RTL9210B_ROOT.xml`, confirming the hierarchy names and child
sheet references. Missing unrelated child sheets mean this is hierarchy and
source-lineage evidence only, not a complete root ERC/netlist closure.

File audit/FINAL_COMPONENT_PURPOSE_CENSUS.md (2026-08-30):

# Final component-purpose census

All 54 active PCB footprints are listed. “Remove candidate” means a future
variant question, not authorization to modify the active board.

| Ref | Part/value | Block | Purpose | Required? | Historical origin | Remove candidate? |
|---|---|---|---|---|---|---|
| J1 | Amphenol 74221-101LF | SXM2 | One V100 module receptacle | Yes | SXM2 interface | No |
| J2 | 2× Amphenol 10164227-1004A1RLF | CM5 | CM5 host connectors | Yes | CM5 carrier | No |
| J3,J4 | Molex 39301082 | 12 V input | Dual high-current input | Yes | power architecture | No |
| J5,J6 | Molex 22-23-2041 | cooling | Four-wire fan headers | Yes | cooling contract | No |
| J7 | Molex 22-23-2041 | cooling | Optional pump/auxiliary fan | Intentional | cooling contract | Optional |
| J8 | JST B4B-PH-K-S | debug | Internal UART | Yes | bring-up contract | Optional only after hardware maturity |
| J9,J10 | Amphenol 10137064-00011LF | FAST USB3 | USB-C external fast host ports | Current design yes | modular Type-C decision | Future USB-A variant candidate |
| J11 | Amphenol 10171746-00021LF | SERVICE | USB2 DRP/service port | Yes | recovery/service requirement | No |
| U1 | TPSM63606RDLR | CM5 power | CM5 5 V buck | Yes | power tree | No |
| U2,U3 | LM74700QDBVRQ1 | 12 V protection | ideal-diode/reverse protection | Yes | power tree | No |
| U4,U8 | TPS25821DSSR | FAST USB3 power | Type-C host VBUS/source control | Current Type-C design yes | modular Type-C decision | Removed in fixed-host Type-A variant |
| U5,U9 | HD3SS3212IRKSR | FAST USB3 | reversible SuperSpeed mux | Current Type-C design yes | Type-C orientation requirement | Removed in fixed-host Type-A variant |
| U6,U7,U10,U11 | TPD4EUSB30 | FAST USB3 | four-line ESD arrays for Type-C orientations | Current protection yes | Type-C branch implementation | Reduce/re-evaluate in Type-A variant |
| U12 | TUSB320LAIRWBR | SERVICE | USB-C DRP/CC controller | Yes | service recovery design | No |
| U13 | TPS2553DBVR | SERVICE | USB2 VBUS limiter | Yes | service power safety | No |
| U14 | SN74LVC1G04DCKR | SERVICE | VBUS role interlock inverter | Yes | service dual-role design | No |
| U15 | TPD2EUSB30A | SERVICE | USB2 ESD | Yes | service protection | No |
| U16 | TPSM63606RDLR | USB power | dedicated USB peripheral 5 V buck | Yes | modular USB power budget | No |
| U17,U18 | TPD2EUSB30A | FAST USB3 | USB2 companion ESD | Current Type-C design yes | fast-port protection | Re-evaluate in Type-A variant |
| Q1,Q2 | CSD19536KCS | 12 V protection | low-loss power MOSFETs | Yes | ideal-diode path | No |
| F1,F2 | Littelfuse 178.6165.0001 / 0297015.U | 12 V input | per-input fusing | Yes | high-current safety | No |
| C1,C2 | GRM21BR71H224KA01# | PCIe | V100 TX AC coupling | Yes | PCIe endpoint contract | No |
| C3,C4 | 10 uF 50 V | buck input | local buck input bypass | Yes | regulator layout | No |
| C5,C6 | 22 uF 25 V | buck output | local buck output bypass | Yes | regulator layout | No |
| C7 | 100 nF VLDOIN | CM5 power | regulator VLDOIN bypass | Yes | TI layout | No |
| C8,C9 | 100 nF LM74700 VCAP | 12 V protection | controller charge-pump bypass | Yes | ideal-diode layout | No |
| R1 | 0R CLKREQ link | PCIe control | documented DNP/POP option | Intentional option | PCIe bring-up | Yes, if strap is frozen |
| R2 | 40.2 k | CM5 power | buck feedback | Yes | regulator setting | No |
| R3 | 10.0 k | CM5 power | buck feedback | Yes | regulator setting | No |
| R4 | 13.0 k | CM5 power | buck RT | Yes | regulator setting | No |
| R5,R6 | 100 k | FAST USB3 | TPS25821 REF support | Current Type-C design yes | Type-C controller support | Removed with Type-C path |
| R7 | 52.3 k | SERVICE | TPS2553 current limit | Yes | service power safety | No |
| D1 | SMBJ18A | 12 V input | provisional un-netted TVS placeholder | Unknown/provisional | source protection study | Yes after replacement/provenance closure |
| TP1 | PERST# marker | debug | low-speed reset observation | Optional intentional | bring-up | Optional |
| TP2 | REFCLK marker | debug | documentation/access marker without probe stub | Optional intentional | bring-up | Optional |
| TP3 | nRPIBOOT marker | recovery | internal CM5 recovery access | Yes for recovery | bring-up contract | No |
| MECH1 | V100/SXM2 envelope | mechanical | cooler/backplate contract | Intentional mechanical | mechanical validation | Not a BOM item; may be omitted from release library |

The grouped rows expand to 54 physical references. No footprint’s only reason
was an x16 carrier, second GPU, NVLink, card-edge, Ethernet, HDMI, MIPI, or
microSD feature. The Type-C-specific rows are the only broad simplification
cluster identified.

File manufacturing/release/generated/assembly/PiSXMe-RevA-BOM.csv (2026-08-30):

reference | value | footprint | manufacturer | mpn | dnp
C1 | 220nF X7R 50V PCIe AC coupling | Capacitor_SMD:C_0805_2012Metric | Murata | GRM21BR71H224KA01# | no
C2 | 220nF X7R 50V PCIe AC coupling | Capacitor_SMD:C_0805_2012Metric | Murata | GRM21BR71H224KA01# | no
C3 | 10uF 50V X7R buck input capacitor 1 | Capacitor_SMD:C_1206_3216Metric | TDK | CGA6P1X7R1H106K250AC | no
C4 | 10uF 50V X7R buck input capacitor 2 | Capacitor_SMD:C_1206_3216Metric | TDK | CGA6P1X7R1H106K250AC | no
C5 | 22uF 25V X7R buck output capacitor 1 | Capacitor_SMD:C_1210_3225Metric | Murata | GRM32ER71E226ME15L | no
C6 | 22uF 25V X7R buck output capacitor 2 | Capacitor_SMD:C_1210_3225Metric | Murata | GRM32ER71E226ME15L | no
C7 | 100nF 50V X7R VLDOIN capacitor | Capacitor_SMD:C_0603_1608Metric | Murata | GRM188R71H104KA93D | no
C8 | 100nF 50V X7R LM74700 VCAP capacitor A | Capacitor_SMD:C_0603_1608Metric | Murata | GRM188R71H104KA93D | no
C9 | 100nF 50V X7R LM74700 VCAP capacitor B | Capacitor_SMD:C_0603_1608Metric | Murata | GRM188R71H104KA93D | no
F1 | Littelfuse 178.6165.0001 + 0297015.U branch A | PiSXMe:ATO_FuseHolder | Littelfuse | 178.6165.0001 + 0297015.U | no
F2 | Littelfuse 178.6165.0001 + 0297015.U branch B | PiSXMe:ATO_FuseHolder | Littelfuse | 178.6165.0001 + 0297015.U | no
J1 | Amphenol 74221-101LF SXM2 receptacle | PiSXMe:SXM2_74221-101LF | Amphenol | 74221-101LF | no
J10 | Amphenol 10137064-00011LF USB-C USB3 FAST B | PiSXMe:USB_C_FAST_10137064 | Amphenol | 10137064-00011LF | no
J11 | Amphenol 10171746-00021LF USB-C USB2 SERVICE | PiSXMe:USB_C_SERVICE_10171746 | Amphenol | 10171746-00021LF | no
J2 | 2x Amphenol 10164227-1004A1RLF BergStak 4mm | PiSXMe:CM5_1004 | Amphenol | 10164227-1004A1RLF x2 | no
J3 | Molex 39301082 Mini-Fit Jr 8-circuit input A | PiSXMe:MiniFitJr_8_RA | Molex | 39301082 | no
J4 | Molex 39301082 Mini-Fit Jr 8-circuit input B | PiSXMe:MiniFitJr_8_RA | Molex | 39301082 | no
J5 | Molex 22-23-2041 2.54mm PC PWM fan header 1 | PiSXMe:Fan_2x2_2.54mm | Molex | 22-23-2041 | no
J6 | Molex 22-23-2041 2.54mm PC PWM fan header 2 | PiSXMe:Fan_2x2_2.54mm | Molex | 22-23-2041 | no
J7 | Molex 22-23-2041 2.54mm pump/aux header | PiSXMe:Fan_2x2_2.54mm | Molex | 22-23-2041 | no
J8 | JST B4B-PH-K-S CM5 UART/debug | PiSXMe:JST_PH_4 | JST | B4B-PH-K-S | no
J9 | Amphenol 10137064-00011LF USB-C USB3 FAST A | PiSXMe:USB_C_FAST_10137064 | Amphenol | 10137064-00011LF | no
Q1 | CSD19536KCS 100V low-loss N-MOSFET branch A | Package_TO_SOT_THT:TO-220-3_Vertical | Texas Instruments | CSD19536KCS | no
Q2 | CSD19536KCS 100V low-loss N-MOSFET branch B | Package_TO_SOT_THT:TO-220-3_Vertical | Texas Instruments | CSD19536KCS | no
R1 | 0R POP CLKREQ always-requested clock strap | Resistor_SMD:R_0603_1608Metric | Yageo | RC0603FR-070RL | no
R2 | 40.2k 1% feedback upper resistor | Resistor_SMD:R_0603_1608Metric | Yageo | RC0603FR-0740K2L | no
R3 | 10.0k 1% feedback lower resistor | Resistor_SMD:R_0603_1608Metric | Yageo | RC0603FR-0710KL | no
R4 | 13.0k RT frequency resistor | Resistor_SMD:R_0603_1608Metric | Yageo | RC0603FR-0713KL | no
R5 | 100k 0.5% TPS25821 REF resistor FAST A | Resistor_SMD:R_0603_1608Metric | Yageo | RC0603FR-07100KL | no
R6 | 100k 0.5% TPS25821 REF resistor FAST B | Resistor_SMD:R_0603_1608Metric | Yageo | RC0603FR-07100KL | no
R7 | 52.3k 1% TPS2553 0.5A current-limit resistor | Resistor_SMD:R_0603_1608Metric | Yageo | RC0603FR-0752K3L | no
TP3 | CM5 nRPIBOOT / internal rpiboot test point | PiSXMe:TestPoint | Keystone Electronics | 5000 | no
U1 | TPSM63606RDLR 6A 12V-to-5V module | PiSXMe:TPSM63606 | Texas Instruments | TPSM63606RDLR | no
U10 | TPD4EUSB30 FAST B SuperSpeed ESD array 1 | PiSXMe:TPD4EUSB30_DQA | Texas Instruments | TPD4EUSB30 | no
U11 | TPD4EUSB30 FAST B SuperSpeed ESD array 2 | PiSXMe:TPD4EUSB30_DQA | Texas Instruments | TPD4EUSB30 | no
U12 | TUSB320LAIRWBR SERVICE USB-C DRP controller | PiSXMe:TUSB320LAI_RWB | Texas Instruments | TUSB320LAIRWBR | no
U13 | TPS2553DBVR SERVICE VBUS current limiter | PiSXMe:TPS2553_DBV | Texas Instruments | TPS2553DBVR | no
U14 | SN74LVC1G04DCKR SERVICE VBUS role inverter | PiSXMe:SN74LVC1G04_DCK | Texas Instruments | SN74LVC1G04DCKR | no
U15 | TPD2EUSB30A SERVICE USB2 ESD array | PiSXMe:TPD2EUSB30A_DQA | Texas Instruments | TPD2EUSB30A | no
U16 | TPSM63606RDLR 6A dedicated USB peripheral 5V rail | PiSXMe:TPSM63606_USB | Texas Instruments | TPSM63606RDLR | no
U17 | TPD2EUSB30A FAST A USB2 companion ESD array | PiSXMe:TPD2EUSB30A_DQA | Texas Instruments | TPD2EUSB30A | no
U18 | TPD2EUSB30A FAST B USB2 companion ESD array | PiSXMe:TPD2EUSB30A_DQA | Texas Instruments | TPD2EUSB30A | no
U2 | LM74700QDBVRQ1 branch A reverse-current controller | Package_TO_SOT_SMD:SOT-23 | Texas Instruments | LM74700QDBVRQ1 | no
U3 | LM74700QDBVRQ1 branch B reverse-current controller | Package_TO_SOT_SMD:SOT-23 | Texas Instruments | LM74700QDBVRQ1 | no
U4 | TPS25821DSSR FAST A Type-C source controller | PiSXMe:TPS25821_DSS | Texas Instruments | TPS25821DSSR | no
U5 | HD3SS3212IRKSR FAST A SuperSpeed orientation mux | PiSXMe:HD3SS3212_RKS | Texas Instruments | HD3SS3212IRKSR | no
U6 | TPD4EUSB30 FAST A SuperSpeed ESD array 1 | PiSXMe:TPD4EUSB30_DQA | Texas Instruments | TPD4EUSB30 | no
U7 | TPD4EUSB30 FAST A SuperSpeed ESD array 2 | PiSXMe:TPD4EUSB30_DQA | Texas Instruments | TPD4EUSB30 | no
U8 | TPS25821DSSR FAST B Type-C source controller | PiSXMe:TPS25821_DSS | Texas Instruments | TPS25821DSSR | no
U9 | HD3SS3212IRKSR FAST B SuperSpeed orientation mux | PiSXMe:HD3SS3212_RKS | Texas Instruments | HD3SS3212IRKSR | no

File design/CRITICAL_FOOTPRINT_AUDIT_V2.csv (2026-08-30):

item | mpn | local_footprint | local_observation | manufacturer_evidence | confidence | blocking
SXM2 receptacle | 74221-101LF | SXM2_74221-101LF | 400 pads; 40x10; 1.27 mm grid; 0.64 mm local pads | Official 400-position/4 mm/0.45 A data; exact land pattern not matched | UNRESOLVED | YES
CM5 connectors | 10164227-1004A1RLF | CM5_1004 | Two 100-position connector regions | Official CM5 datasheet confirms 4.0 mm stack and 2.5 mm underside clearance; drawing match pending | DATASHEET_DERIVED | YES
12V headers | 39301082 | MiniFitJr_8_RA | 8 pads corrected to 4.20 mm two-row pitch | Official Molex page confirms 8 circuits, right-angle, polarized/shrouded, 4.20 mm pitch | DATASHEET_DERIVED | YES
Cable housing | 39012085 | N/A | No PCB footprint | Official Molex page confirms 8-circuit 4.20 mm mating pitch | DATASHEET_DERIVED | NO
CM5 buck | TPSM63606RDLR | TPSM63606 | 20-pad 0.5 mm local study footprint | TI datasheet/reference layout authority; final land/paste check pending | DATASHEET_DERIVED | YES
Ideal diode | LM74700QDBVRQ1 | LM74700_DBV | 6-pad DBV local footprint available | TI DBV drawing authority; final match pending | DATASHEET_DERIVED | YES
MOSFET | CSD19536KCS | CSD19536KCS_TO220 | 3-pad through-hole study footprint | TI package drawing authority; clearance pending | DATASHEET_DERIVED | YES
Fuse holder | 178.6165.0001 | ATO_FuseHolder | Generic two-pad study outline | Holder drawing not matched | UNRESOLVED | YES
PCIe AC capacitors | GRM21BR71H224KA01# | C_0805_2012Metric | 0805 study footprint | Murata package/MPN recorded; final land check pending | DATASHEET_DERIVED | YES
Buck capacitors | CGA6P1X7R1H106K250AC and GRM32ER71E226ME15L | C_1206_3216Metric/C_1210_3225Metric | Package references corrected | Manufacturer package family still needs release check | DATASHEET_DERIVED | YES
Fan headers | 22-23-2041 | Fan_2x2_2.54mm | 4-pin 2.54 mm study footprint | Exact Molex drawing/land pattern not matched | UNRESOLVED | YES
UART | B4B-PH-K-S | JST_PH_4 | 4-pin study footprint | JST drawing not matched | UNRESOLVED | YES
Ethernet/USB | N/A | USB3_HOST | Study connector; MPN not frozen | No manufacturer part selected | UNRESOLVED | YES

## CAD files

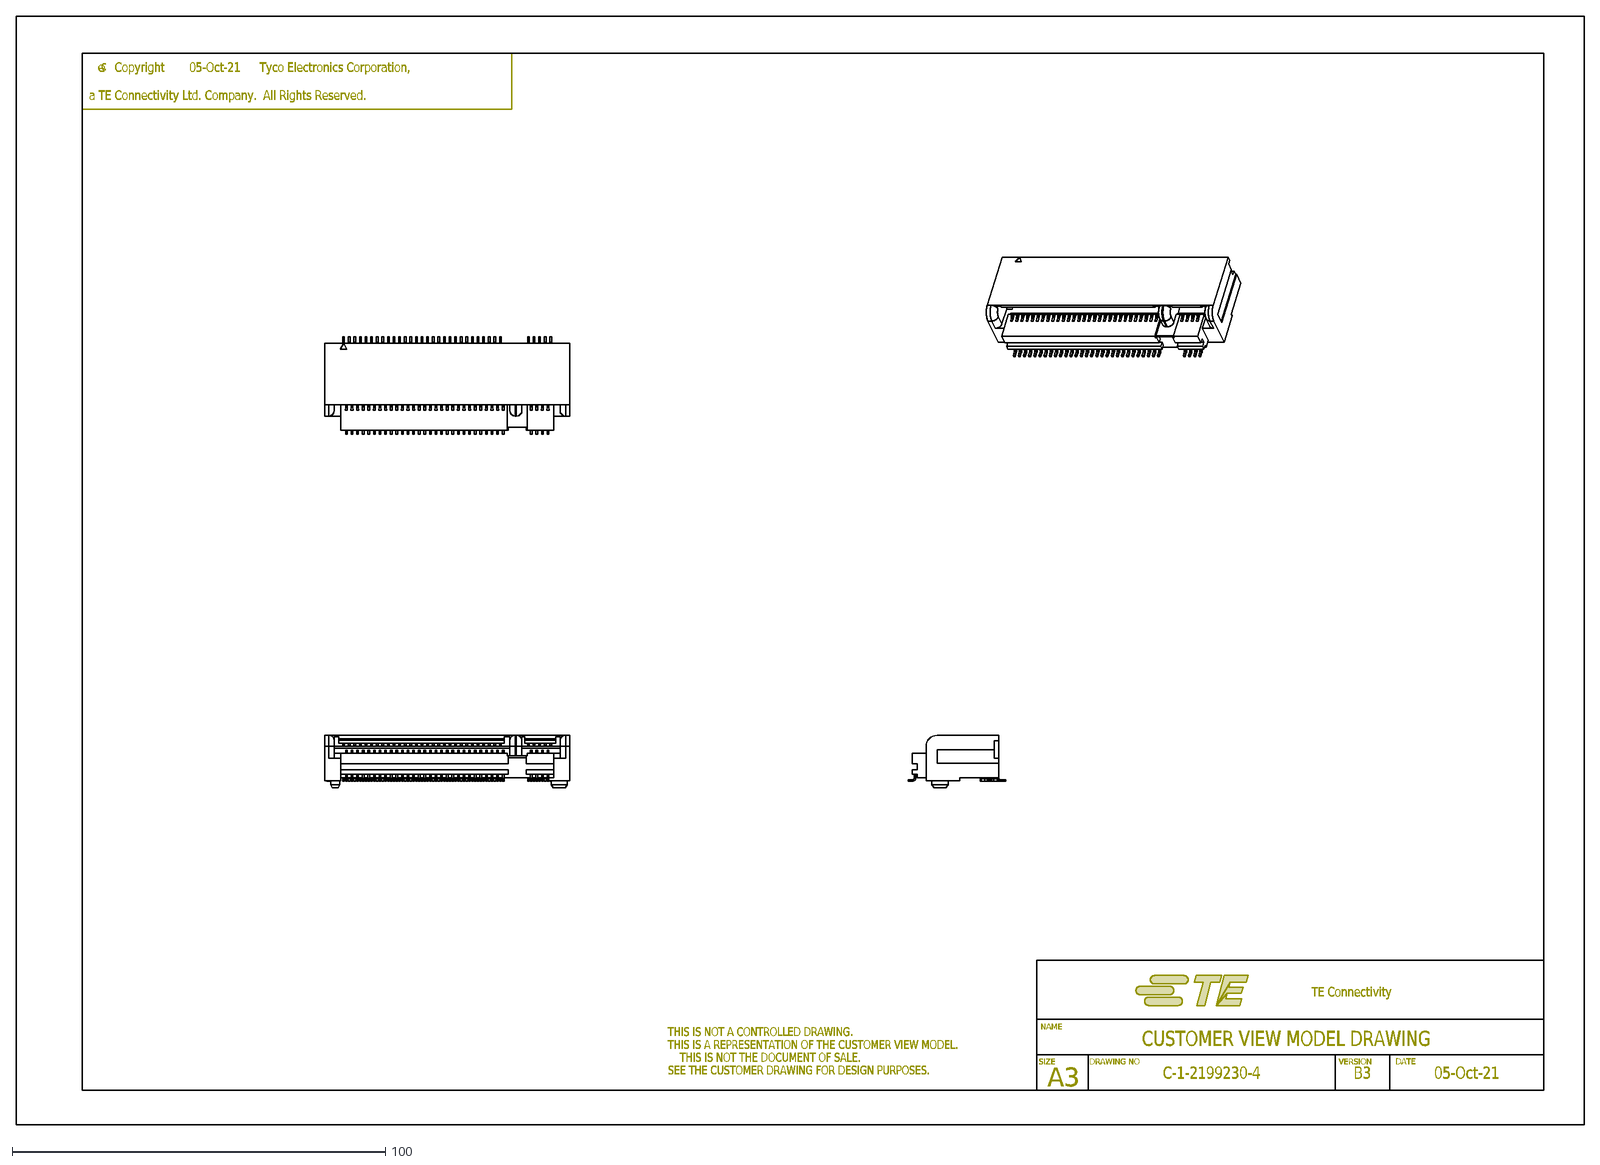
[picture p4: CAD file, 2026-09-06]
pisxme/reva-clean/authority-inventory/primary-docs/storage-upgrade/connectors/te/cad/c-1-2199230-4-b3-2d.dxf
SIZE
DRAWING NO
VERSION
NAME
A3
CUSTOMER VIEW MODEL DRAWING
TE Connectivity
DATE
THIS IS NOT A CONTROLLED DRAWING.
THIS IS A REPRESENTATION OF THE CUSTOMER VIEW MODEL.
THIS IS NOT THE DOCUMENT OF SALE.
SEE THE CUSTOMER DRAWING FOR DESIGN PURPOSES.
c
C-1-2199230-4
B3
05-Oct-21
Copyright
Tyco Electronics Corporation,
a TE Connectivity Ltd. Company. All Rights Reserved.

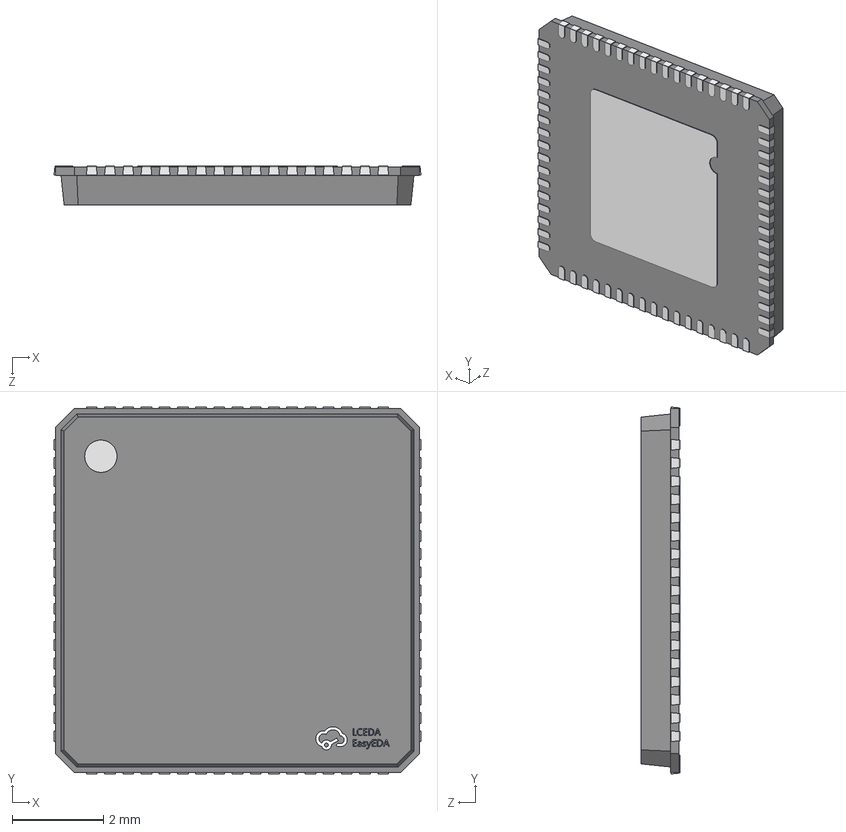
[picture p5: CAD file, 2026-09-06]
pisxme/reva-clean/authority-inventory/rtl9210b/community-lz1/QFN-68_L8.0-W8.0-P0.40-BL-EP4.8.step
8.06 x 8.06 x 0.861 mm

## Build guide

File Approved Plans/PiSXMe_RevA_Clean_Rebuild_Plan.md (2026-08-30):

# PiSXMe Rev A Clean Rebuild Plan

## Summary

Create the new design at `pisxme/reva-clean/` as `PiSXMe_RevA_Clean`. Freeze the existing `pisxme/PiSXMe.*`, legacy libraries, experiments, conflicts, and validation artifacts as `LEGACY_DONOR_REFERENCE`; never route or repair them further.

Phase 0 is currently open: NYX is on `recovery/mac-import-20260829` at `359a568`, with `bible.md` modified and 172 recovered files untracked. The recovery staging checksum passes for all 208 entries, the legacy KiCad sources retain their handoff hashes, KiCad 10.0.5 and the SKiDL→PCB fixture pass, and the recovered bridge suite is 11/12 due to one hard-coded Mac path.

Create private `nova-rey/pisxme-private` for checkpoint branches. Keep public `origin` unchanged until the external-review gate.

## Project and Interface Contract

- New project-local schematic, rules, symbols, footprints, models, validation receipts, and generated connectivity live under `pisxme/reva-clean/`.
- All new or transplanted custom assets use the project-local library namespace `PiSXMeRevAClean`, backed by `PiSXMe_RevA_Clean.kicad_sym` and `PiSXMe_RevA_Clean.pretty`.
- No legacy `PiSXMe:` symbol or footprint library identifier may appear in the clean schematic or PCB. Donor assets must be copied into the new namespace and independently revalidated before use.
- Official KiCad library identifiers may be used only when intentionally selected and included in the library/asset audit; no unresolved or machine-local global-library dependency may pass Phase 3.
- Hierarchy: `CORE_CM5`, `V100_PCIE`, `V100_POWER`, `POWER_INPUT`, `REGULATORS`, `ETHERNET`, `STORAGE`, `SERVICE`, `COOLING`, and `DEBUG`.
- CM5 exposes only PCIe Gen2 x1, native Gigabit Ethernet, one USB3 storage path, USB2 SERVICE, required control/debug, and power. No USB hub, USB Ethernet, 2.5GbE, external USB3, NVLink, PCIe switch, or unused PCIe lanes.
- Storage is CM5 USB3 → selected USB/SATA bridge → underside B-key SATA M.2. Use 2280 as the primary envelope and allow a 2242 retention point if it remains mechanically clean. Mark the board `M.2 SATA ONLY — NVMe NOT SUPPORTED`.
- SERVICE is USB2 UFP only: DP/DM, connector-boundary ESD, two 5.1 kΩ Rd resistors, and host VBUS sense/test. It never sources VBUS.
- Power contract: two mandatory 12 V inputs from a regulated, current-limited cold-plug bench supply; hot-plug is unsupported for Rev A.
- Layer contract: F.Cu signals/components, In1 solid GND, In2 low-voltage power, In3 protected 12 V/high-current power, In4 solid GND, B.Cu secondary signals/components. Ordinary through vias only; no ordinary signals on plane layers.
- SKiDL may own an island only after its hierarchy, custom pin mapping, and generated KiCad parity fixtures pass. Otherwise native hierarchical KiCad owns that island. There will be exactly one connectivity authority per block, with native KiCad reopen/ERC/netlist/PCB parity as the universal acceptance gate.

## Phased Implementation

| Phase | Purpose and allowed work | Frozen areas, deliverable, and pass gate |
|---|---|---|
| 0 — Recovery checkpoint | Classify every recovered file, preserve quarantine, verify hashes/rules/30 footprints, scan checkpoint contents, and create the private mirror. Commit the byte-preserving import first; then branch `reva-clean`, fix the nonportable bridge test, and rerun validation. | No legacy design edits. Push `recovery/mac-import-20260829` and `reva-clean` only to `private`. Pass requires provenance-complete status, 12/12 bridge tests, passing external toolchain fixture, native legacy parse, recorded legacy ERC/DRC baseline, and tag `PISXME_RECOVERY_CHECKPOINT_20260829`. |
| 1 — Donor extraction | Produce `KEEP`, `FIX_WHILE_TRANSPLANTING`, and `DISCARD` manifests for PCIe, SXM2 mechanics/power, CM5, protection, regulators, footprints, and rules. Reconcile stale via and hash records. | Legacy source remains immutable. KEEP includes PER0, PET0 raw legs/caps, REFCLK/PERST architecture, connector land patterns after verification, cooler/backplate contract, and distributed power. Dual-USB routing, proxy nets, old outline assumptions, and inner-plane signals are DISCARD. |
| 2 — Authority inventory | Extract/register the complete official CM5IO archive and obtain exact-revision authorities for the bridge, SATA M.2 mapping, socket, MagJack/ESD, power/protection, CM5/SXM2 connectors, cooler mechanics, and current JLC stack. | No production schematic synthesis. Treat the identical EEWorld/MiSaKa JMS578 files as one lineage. JMS578 remains preferred only if documentation, firmware, Linux UAS, package, and procurement close; otherwise evaluate ASM1153E under the same gate. Use [Raspberry Pi’s CM5IO design authority](https://www.raspberrypi.com/documentation/computers/compute-module.html) and [JMicron’s JMS578 product authority](https://www.jmicron.com/products/list/1) as primary starting points. |
| 3 — Schematic architecture and library isolation | Create the clean hierarchy, interface ledger, net classes, source-authority manifest, and project-local `PiSXMeRevAClean` symbol/footprint libraries. Copy approved donor assets individually into the new namespace; revalidate symbol pins, footprint pads, land patterns, models, and provenance. Prove flat, real hierarchy, custom pin-to-pad, and schematic→PCB fixtures. | No placement or routing. A namespace scan must find zero legacy `PiSXMe:` IDs, unresolved library links, or machine-local paths in the clean source. Pass also requires native KiCad reopen, ERC, netlist export, machine-readable symbol-pin↔footprint-pad parity, and zero PCB-only/proxy nets. |
| 4 — Accelerator transplant | Rebuild only V100 lane 0, transmitter-side AC coupling, REFCLK, PERST, SXM2 mapping, and associated control contract using revalidated `PiSXMeRevAClean` assets. | Conventional islands remain untouched. Pass requires direction/polarity audit, only lane 0 present, no NVLink/x16 baggage, verified SXM2 mapping, and explicit `REV_A_EMPIRICAL_RISK` records. |
| 5 — Power architecture | Build dual input protection, protected 12 V merge, CM5 5 V, storage 3.3 V, other required rails, and distributed V100 feed from vendor circuits. | Accelerator pin contract frozen. Pass requires complete rail/current/sequence budget, correct LM74700 polarity, fuse/TVS coordination for the cold-plug supply, regulator component calculations, PG/fault policy, and no 12 V at M.2. |
| 6 — Ethernet island | Adapt CM5IO pair mapping, MagJack center taps/LEDs, shield, ESD, and support circuitry nearly directly. | CM5 and power contracts frozen. Pass requires exact schematic/pin/footprint parity and traceability to the official CM5IO source; no routing yet. |
| 7 — Storage island | Build CM5 USB3 → bridge → SATA → B-key M.2, including bridge rails, clock, reset, configuration/firmware, and SSD 3.3 V. | Ethernet and prior contracts frozen. Pass requires verified USB/SATA direction and polarity, bridge package mapping, M.2 SATA pins/keying, Linux/UAS assumptions, real socket model, and proof that the selected bridge does not require the CM5 USB2 SERVICE link. |
| 8 — SERVICE island | Build the minimal USB2 recovery interface and recovery/rpiboot controls. | Storage and prior islands frozen. Pass requires UFP role proof, VBUS isolation, connector-boundary ESD, two Rd resistors, and no DRP/source/SuperSpeed circuitry. |
| 9 — Mechanical models | Load exact models for SXM2, V100 cooler/backplate, CM5 and cooler, MagJack, USB-C, M.2/SSDs, fuses, 12 V and cooling connectors. Define cable and mating envelopes. | Electrical connectivity frozen. Courtyards alone are not evidence; missing critical models block progression. |
| 10 — CM5 orientation study | Build topside and underside arrangements against identical V100, connector, and enclosure anchors. | No production routing. Reject any candidate with cooler, floor, SSD, standoff, cable, insertion/removal, or assembly-order conflicts. If both pass, choose fewer high-speed transitions; then shorter aggregate PCIe+USB3+Ethernet corridors; then greater thermal/service independence—prefer the orientation that allows CM5 cooling or removal without disturbing the V100 assembly; finally use general CM5 serviceability as the tie-breaker. |
| 11 — Acreage floorplan | Place functional neighborhoods without a fixed outline, then derive an oversized outline—approximately 300 × 180 mm only if supported by the envelopes. Perform local escape feasibility, not production routing. | Orientation decision frozen. Pass requires direct corridors, local support parts, non-overlapping mechanical zones, clean power flow, and no density-driven compromise. |
| 12 — Hostile floorplan review | Review connector access, mating clearance, cooler/backplate volume, assembly order, crossing corridors, regulator locality, M.2 service, and board-side consistency. | No routing around placement defects. All blockers must be corrected in placement before continuing. |
| 13 — Stack finalization | Refresh and select a current JLCPCB six-layer ordinary-through-via stack. Field-solve PCIe, USB3, SATA, Ethernet, and USB2 geometries; define widths, gaps, antipads, via fields, references, and return-via rules. | Floorplan and layer roles freeze here. No high-speed routing until stack and constraints pass independent review. |
| 14 — V100 power routing | Route input and distributed SXM2 current paths with broad copper and deliberate transition arrays. | Signal corridors and regulator islands protected. Pass requires current-density, voltage-drop, sharing, connector-contact, and thermal evidence with no single-neck feed. |
| 15 — Regulator routing | Route every regulator from its vendor layout: local high-dI/dt loops, feedback, grounding, thermal vias, and keepouts. | V100 power frozen. Pass requires reference-layout overlays and calculated effective capacitance/thermal margins. Later signals may not enter regulator keepouts. |
| 16 — PCIe routing | Preserve PER0’s zero-via geometry where compatible; preserve PET0 raw legs/caps and rebuild post-cap/REFCLK transitions with symmetric local return vias. Route PERST without a high-speed stub. | Power/regulators frozen. Pass requires lane direction/polarity, length/skew/via metrics, continuous references, transition geometry, and a focused PCIe specialist verdict. |
| 17 — Ethernet routing | Adapt CM5IO placement and routing philosophy from CM5 to ESD/MagJack. | PCIe frozen. Pass requires 100 Ω geometry, pair ordering, intra-pair metrics, reference continuity, connector-boundary ESD, shield/return review, and no improvised maze routing. |
| 18 — USB3 routing | Route CM5 to bridge as one short local corridor. | Earlier high-speed routes frozen. Pass requires 90 Ω geometry, bounded skew, symmetric transitions/returns, and no plane-layer signals. |
| 19 — SATA routing | Route bridge to M.2 as a distinct local corridor. | USB3 frozen. Pass requires 100 Ω geometry, polarity/direction, bounded skew, reference continuity, and absence of stubs or connector conflicts. |
| 20 — SERVICE routing | Route USB2 directly from CM5 through ESD to USB-C. | All faster channels frozen. Zero signal vias is the target; pass requires one reference layer, short matched routing, and no switch-node exposure. |
| 21 — Low-speed/control | Route enables, faults, PG, reset, recovery, UART, fan/pump controls, and other required low-speed nets locally. | High-speed and regulator keepouts frozen. No layer-policy violations or unnecessary transitions. |
| 22 — GND/returns/zones | Finalize solid In1/In4, power zones, ESD returns, connector stitching, transition-return clusters, SXM2 grounding, and high-current spreading. | Signal topology frozen. Every standalone via receives a functional category; indiscriminate via sprinkling fails review. |
| 23 — Test/debug | Add safe pads for raw/fused/protected 12 V, CM5 5 V, storage 3.3 V, PG/fault/enable, PERST, recovery, UART, and nearby grounds. | No high-speed stubs. Pass requires accessible probing with the real cooler/enclosure installed. |
| 24 — Acreage validation | Run native ERC/DRC, schematic↔PCB parity, clean-library namespace audit, open/short checks, layer census, route metrics, return review, PI/current/thermal analysis, regulator overlays, 3D/assembly, DFM, and hostile routing review. | No shrinking. Any real defect, missing critical authority, unresolved mapping, legacy-library leakage, or mechanical interference blocks the board. |
| 25 — Acreage freeze | Record hashes, outline, placements, routes, vias, margins, power results, models, assembly sequence, library census, and all validation receipts. | Commit, append `bible.md`, push privately, and tag `ACREAGE_REFERENCE_VALIDATED`. This is design-validation evidence, not fabricated-hardware proof. |
| 26+ — Compression | Shrink only the highest-slack edge by 5 mm per iteration. Make minimal translations and rerun every affected check against the acreage baseline. | Record `SHRINK_ACCEPTED` or `SHRINK_REJECTED`. Reject increases in unjustified high-speed vias, route gymnastics, broken references/vendor layouts, reduced approved clearances, worse power/thermal behavior, congestion, or new DRC difficulty. Also reject meaningful assembly complexity: awkward insertion angles, trapped M.2 screws, unreachable latches, disturbed cooler/service order, inaccessible fasteners, or opposite-side placement that creates avoidable double-sided reflow/fixture problems. The first rejection ends compression; the previous accepted outline is final. |
| Final review | Perform independent schematic, library/mapping, PCIe/SI, PI, thermal, mechanical, assembly, DFM, serviceability, and historical-debt reviews. | `PISXME_REVA_CLEAN_READY_FOR_EXTERNAL_REVIEW` requires no verified P0, clean real ERC/DRC, authoritative connectivity, zero legacy-library leakage, deliberate transitions, valid mechanics and assembly sequence, a validated acreage ancestor, and recorded compression history. Otherwise declare `PISXME_REVA_CLEAN_BLOCKED`. |

## Ownership, Commits, and Validation

- Root coordinates gates and Git. One `kicad_engineer` owns all mutable KiCad work.
- Use `pcb_architect` through the architecture/placement/stack freeze, `power_integrity_engineer` after Phases 14–15, `pcie_specialist` after Phase 16, `dfm_engineer` at Phase 24, and one final `hardware_auditor`.
- Permit one focused correction cycle per specialist gate. Do not continue after `FAIL` or unverifiable critical evidence.
- Make checkpoint commits only for validated recovery, architecture/reference closure, completed source islands, stack freeze, major routed subsystems, acreage freeze, accepted shrink iterations, and final review. Append `bible.md` in every such commit.
- Push pre-review commits only to the private mirror. Do not fabricate/order hardware or push clean-rebuild branches to public `origin` before the external-review gate.
- Preserve `REV_A_EMPIRICAL_RISK` for undocumented V100 endpoint/sequencing behavior. Design evidence cannot claim physical enumeration, thermal success, or hardware operation before fabrication and bring-up.

## Assumptions and Locked Defaults

- Git: protected recovery and `reva-clean` branches backed by new private `nova-rey/pisxme-private`.
- Libraries: custom production assets are isolated under `PiSXMeRevAClean`; legacy `PiSXMe:` IDs are forbidden in the clean project.
- Fabrication basis: refreshed current JLCPCB six-layer stack, ordinary through vias.
- Input power: regulated, current-limited cold-plug 12 V supply; both inputs mandatory.
- Storage: JMS578 preferred but not selected until Phase 2 authority closes; B-key SATA M.2, 2280 primary, optional 2242 retention.
- CM5 side and temporary acreage dimensions remain evidence-derived decisions under the deterministic Phase 10/11 gates.
- The legacy 240 × 140 mm outline, old dual-USB architecture, and historical routing are not constraints on the clean project.

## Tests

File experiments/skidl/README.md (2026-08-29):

# SKiDL spike fixtures

These small source files preserve the Mac-side SKiDL experiments used to test
electrical-authority generation. They are disposable fixtures, not PiSXMe
source and not release artifacts.

Known environment from the experiment: Python 3.11, SKiDL 2.3.0,
kinet2pcb 1.1.4, KiCad 10.0.5. The flat fixture generated a KiCad schematic
and netlist and its disposable PCB mapping was structurally correct. The
hierarchy fixture did not close the native ERC/hierarchy gate; do not treat it
as proof of hierarchical authority. Reproduce on Linux before using SKiDL for
M6.

Some generated outputs may remain in the ignored local `work/skidl_spike/`
directory, but they are not required for a clone. Re-run the checked-in source
files to regenerate them. Do not copy virtual environments or caches into the
repository.

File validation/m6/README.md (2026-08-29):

# Durable M6 evidence

These reports are preserved from the Mac-side disposable studies so the Linux
workstation does not depend on `/private/tmp`. They are evidence, not active
source and not release signoff. The authoritative restart boundary is
`plans/M6_LINUX_RESTART_CHECKLIST.md`.

- `M6_ARCHITECTURE_BLOCKER_REPORT.md` — latest architecture/routability status
- `M6_RECONSTRUCTION_STATUS.md` — source-bound reconstruction disposition
- `M6_ETHERNET_SATA_REPLAN_CHECKPOINT.md` — provisional Ethernet/SATA decision
- `M6_ESD_TRUTH_CHECKPOINT.md` — corrected ESD pad facts
- `M6_USB_REBUILD_CHECKPOINT.md` — failed USB reconstruction evidence
- `U16_BLOCKER_STATUS.md` and `U16_PACKAGE_CHECKPOINT.md` — regulator status
- `SCHEMATIC_ISLAND_ATTEMPT_REPORT.md` — failed source-bound island attempt
- `SCHEMATIC_AUTHORING_TOOLING_REPORT.md` — direct-backend authority gap
- `SKIDL_EVALUATION_RESULT.md` — Mac SKiDL result and Linux gate

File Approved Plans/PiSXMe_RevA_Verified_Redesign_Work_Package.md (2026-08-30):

# PiSXMe Rev A Verified Redesign Work Package

## 1. Verification summary

Audit basis: active branch `codex/usb-a-active-migration`, KiCad 10.0.5. Active-source hashes were captured before review. A disposable copy was opened, zone-refilled, saved by KiCad, and checked without changing the project: 49 DRC violations, 56 unconnected records, 308 schematic/PCB parity records, and 44 ERC violations. Forty-five unconnected records are zone/plane context; eleven are genuine signal discontinuities.

Important corrections:

- “Five GND vias” is literally accurate, although 16 additional GND connector/shell through-hole pads exist.
- The reported blind vias are false positives. All 165 active vias normalize as ordinary through vias.
- FAST-B really uses In3 in the current USB-A design.
- Eleven true signal gaps exist, caused by incorrect ESD symbol/footprint assumptions.
- U16 is a verified P0.
- Additional verified P0s exist in the TPS2553, TUSB320, USB ESD, and LM74700/MOSFET pin maps.
- No contradictory V100 evidence was found; the PCIe concern is empirical, not architectural.

## 2. PCIe design-basis disposition

Retain CM5 → V100 PCIe Gen2 x1 and treat the SXM2 interface as an ordinary PCIe endpoint on a non-standard connector. Absence of private NVIDIA sequencing documentation is not contradictory evidence. Track exact SXM2 pin mapping, common-clock/SSC behavior, reset timing, and V100 power sequencing as `REV_A_EMPIRICAL_RISK`; require external review and first-hardware enumeration evidence, but do not reopen the architecture without new contradictory evidence.

## 3. Corrected severity table

| Finding | Disposition | Priority | Decision |
|---|---|---:|---|
| U16 incomplete regulator | Confirmed | P0 | Rebuild complete TPSM63606 circuit |
| Q1/Q2 source/drain orientation | Confirmed | P0 | Correct LM74700/MOSFET topology |
| TPS2553 U4/U8/U13 pin maps | Confirmed | P0 | Correct symbol/footprint mapping; U13 removed |
| TUSB320 U12 pin map | Confirmed | P0 | Remove under fixed-device SERVICE decision |
| U6/U10 USB3 ESD topology | Confirmed | P0 | Correct DQA mapping and routes |
| U15/U17/U18 package mismatch | Confirmed | P0 | Replace with TPD2EUSB30A DRT |
| Eleven endpoint records | Confirmed true gaps | P0 | Close all signal gaps |
| F1/Q1 cooler intrusion | Confirmed | P0 mechanical | Relocate |
| J5/J6/J7 overlap | Confirmed | P0 mechanical | Re-space |
| U1 | Functional, layout concern | P1 | Keep placement; rebuild local support |
| Signals on In1/In4 | Confirmed | P1 | Make both layers solid GND |
| FAST-B on In3 | Confirmed | P1 | Reroute off In3 |
| USB2 asymmetry | Confirmed | P1 | Reroute all three pairs |
| PCIe transition returns | Confirmed | P1 | Repair PET0/REFCLK transition fields |
| 12 V TVS/bulk/inrush | Partial | P1 | Cold-plug policy; coordinated protection |
| Main 12 V neck-downs | Confirmed | P1 | Widen bulk-current trunks |
| Test/debug access | Confirmed insufficient | P1 | Add rail/control test pads |
| V100 sequencing uncertainty | Confirmed, reduced | REV_A_EMPIRICAL_RISK | External review and first hardware |
| Blind-via count | False positive | — | Normalize to through vias |
| Historical D1/USB-C/mux records | Stale active references | P2 | Purge during regeneration |

## 4. Verified layer/via facts

### GROUND_VIA_VERIFICATION

- Total vias: 165.
- Literal `/GND` vias: 5.
- `/CHASSIS_GND` vias: 0.
- Additional GND connector/shell through-hole pads: 16.
- The five standalone vias are at approximately `(190.8,86.8)`, `(197.8,123)`, `(207.2,139)`, `(205.5,68.5)`, `(197.8,52.2)`.
- None is a close return transition for PCIe PET0 or REFCLK.

The previous “five GND vias” statement was accurate literally, but its functional classification was misleading.

### VIA_CONSTRUCTION_VERIFICATION

The source contains 141 F.Cu–B.Cu records, eight F.Cu–In1, eight F.Cu–In2, and eight F.Cu–In3 records. None is explicitly blind, buried, or microvia. KiCad normalizes all 165 as F.Cu–B.Cu through vias. Use standard through-via fabrication only.

### LAYER_USAGE_VERIFICATION

| Layer | Segments | Length | Actual role |
|---|---:|---:|---|
| F.Cu | 305 | 1484.090 mm | Components, local signals/power, PER0 |
| In1 | 14 | 220.177 mm | Long USB2/control signals inside GND zone |
| In2 | 32 | 680.472 mm | Mixed signals, VPROT, SERVICE, controls |
| In3 | 34 | 623.007 mm | VPROT plus FAST-B USB3 and controls |
| In4 | 45 | 911.025 mm | Long signals inside GND zone |
| B.Cu | 90 | 1266.603 mm | USB3, PET0/REFCLK, power/control |

FAST-A/B USB2 pairs use different inner layers; SERVICE USB2 spans F.Cu/In2/In3/B.Cu. These claims are verified.

## 5. Target layer policy

| Layer | Target role |
|---|---|
| F.Cu | Components, primary breakouts, PCIe/USB, short local signals and regulator loops |
| In1 | Uninterrupted GND only |
| In2 | CM5_5V, USB_5V and 3V3 power zones only |
| In3 | FUSED/VPROT 12 V power zones only |
| In4 | Uninterrupted GND only |
| B.Cu | USB3/PET0/REFCLK trunks and bounded low-speed overflow, referenced to In4 |

All vias remain normal through vias. No blind, buried, microvia, or via-in-pad process is planned.

## 6. Verified schematic fixes

### U16 TPSM63606 — P0

Add 2×10 µF/50 V input capacitors, 2×47 µF/10 V X7R output capacitors, 40.2 kΩ/10.0 kΩ feedback divider, 13.0 kΩ RT resistor, 100 nF VLDOIN bypass, and a 47 kΩ PG pull-up/test point. Correct VCC/NC handling and keep EN/SYNC policy explicit.

### U1 TPSM63606 — P1

The circuit is electrically complete. Keep U1 but place input/output capacitors directly at the module, move the divider adjacent to FB/AGND, and prove worst-case effective output capacitance is at least the TI minimum. Use 2×47 µF/10 V unless DC-bias data proves the existing parts sufficient.

### Q1/Q2 — P0

Connect FUSED_A/B to MOSFET source and VPROT to drain, consistent with LM74700 ANODE/source and CATHODE/drain.

### U4/U8 — P0

Correct TPS2553 DBV pin mapping: 1 IN, 2 GND, 3 EN, 4 FAULT, 5 ILIM, 6 OUT. Add 100 nF input bypass and port-side transient/bulk capacitance.

### USB ESD — P0

U6/U10 use TPD4EUSB30 DQA actual signal pads 1/2/4/5 and GND pads 3/8; pads 6/7/9/10 are NC. U15/U17/U18 use the actual three-pin TPD2EUSB30A DRT implementation.

### SERVICE — fixed recovery UFP

Remove U12 TUSB320, U13 TPS2553 and U14 inverter. Retain J11 as USB2 recovery/device-only port, add 5.1 kΩ Rd resistors from CC1 and CC2 to GND, select device mode explicitly, place 1 µF VBUS-to-GND at the connector, and never source VBUS.

## 7. Proposed floorplan

Use exact manufacturer bodies and mating housings before implementation.

| Block | Approximate target |
|---|---|
| F1/Q1 | `(80,123)` / `(110,123)` below cooler boundary |
| F2/Q2 | `(80,134)` / `(110,134)` second row |
| J5/J6/J7 | Horizontal row near `(174,12)`, `(190,12)`, `(206,12)` |
| U1 | Keep near `(168,128)`; rebuild local field |
| U16 | Lower-right region near `(204,130)` |
| U4/U8 | Immediately beside FAST-A/B VBUS paths |
| U6/U17 | Within 5 mm of FAST-A connector pins |
| U10/U18 | Within 5 mm of FAST-B connector pins |
| SERVICE CC/ESD | Immediately beside J11 |
| Test pads | Board-edge accessible power/control corridors |

F1/Q1 currently intrude approximately 1.5 mm into the cooler keepout. J5/J6/J7 currently overlap at 8 mm pitch; 16 mm pitch is the minimum planning envelope pending housing verification.

## 8. Proposed power redesign

### 12 V input

Rev A is cold-plug bench-only using a regulated, current-limited 12 V source. Per branch:

`J3/J4 → 15 A fuse → post-fuse TVS/CIN → corrected LM74700/MOSFET → VPROT`

Use one branch TVS after each fuse. SMBJ15A-class footprints are the baseline only when the approved PSU maximum is below the TVS stand-off; final selection must keep clamp voltage below downstream absolute maximum. Add 100 nF plus 1 µF local ceramic input capacitance per LM74700 and two 470 µF/25 V low-ESR protected-bus bulk positions plus optional DNP positions. LM74700 EN is not complete forward-path isolation. Both 12 V connectors are mandatory for full V100 operation; single-branch operation is unsupported.

### V100

Preserve distributed SXM2 feeds. Use In3 and broad copper/via arrays, remove duplicate coincident records, widen bulk-current trunks, and validate connector/contact-field temperature and sharing using IPC-2152 and PI analysis.

### CM5 and USB 5 V

Keep separate rails. Complete U1/U16 circuits, use direct pin-adjacent capacitors, and feed each FAST port through corrected TPS2553 switches. Provide at least 120 µF effective port-side bulk per Type-A host path.

## 9. Proposed PCIe changes

- PER0: KEEP exactly; current 74.358/74.389 mm, zero vias, good skew.
- PET0 raw legs and C1/C2: KEEP.
- PET0 after AC capacitors: local transition fix only; colocate P/N transitions and add nearby symmetric GND return vias.
- REFCLK: local transition fix only; symmetric P/N transitions and nearby GND return vias.
- PERST#: clean in place on a permitted signal layer with a short observation branch.

Current PET0 return-via distances are approximately 52–63 mm; REFCLK distances are approximately 35–64 mm. SI, skew, reference continuity and via symmetry must be revalidated.

## 10. Proposed USB3 changes

Reroute FAST-A and FAST-B completely.

- Use F.Cu connector/CM5 breakouts and B.Cu trunks referenced to In4.
- Remove all USB3 routing from In3.
- Target two through vias per conductor: one down near CM5 and one up near the connector/ESD field.
- Add symmetric nearby GND return vias at every pair transition.
- Place ESD within 5 mm of connector pins.
- Route continuously through actual clamp pads; NC pads remain no-connect.
- Target ≤0.5 mm intra-pair mismatch, then validate with final stackup geometry.
- Derive 90 Ω geometry from the selected JLC stackup and solver.

## 11. Proposed USB2 changes

Reroute FAST-A, FAST-B and SERVICE USB2 on F.Cu over solid In1, with zero vias as the target. Keep each P/N pair on one layer/reference, target ≤1 mm mismatch, place corrected DRT ESD parts at the connectors, and avoid switch-node and PCIe transition fields.

## 12. Proposed ground/return redesign

- In1 and In4 become solid GND only.
- Every PCIe/USB3 transition receives symmetric local GND return vias.
- U6/U10 GND pads 3/8 each receive short local return paths.
- U15/U17/U18 each receive an adjacent GND via.
- USB shells tie directly to board GND with bounded connector-edge stitching.
- U1/U16 AGND/PGND and thermal-via patterns follow TI references.
- SXM2 ground pads connect to In1/In4 through distributed arrays aligned with feed corridors.
- Every added via receives a functional category; arbitrary via-count optimization is prohibited.

## 13. Proposed low-speed cleanup

After placement and high-speed work, simplify `PCIE_PWR_EN`, `PERST_N`, `CM5_VBUS_EN`, `FAN_PWM`, `FAN_TACH`, UART, `nRPIBOOT`, regulator PG, and USB switch faults. Use short F.Cu/B.Cu corridors, avoid In1/In4, and keep controls away from high-speed transitions and switch nodes.

## 14. Proposed mechanical fixes

Import fuse, TO-220, USB, fan/pump, J3/J4, J11, CM5 cooler, V100 cooler/backplate and enclosure models. Verify insertion/latch clearance, cable bend radius, fuse access, cooler installation order, UART/recovery access, and assembly sequencing before accepting M2.

## 15. Proposed test/debug additions

Add exposed SMT pads for `TP_RAW12_A/B`, `TP_FUSED12_A/B`, `TP_VPROT12`, `TP_CM5_5V`, `TP_USB_5V`, `TP_3V3`, `TP_CM5_PG`, `TP_USB_PG`, `TP_PERST_N`, `TP_PCIE_PWR_EN`, `TP_USB_A/B_EN`, `TP_USB_A/B_FAULT`, `TP_SERVICE_VBUS`, and several nearby GND pads. Retain J8 UART and TP3/nRPIBOOT. Replace TP1/TP2; do not add high-speed probe stubs.

## 16. Proposed DFM/manufacturing changes

Use standard six-layer through-via fabrication. Apply TI paste-window and thermal-via guidance for TPSM63606. Require X-ray for exposed-pad regulators, dense ESD packages, and inaccessible CM5/SXM2 joints. Review copper balance, warpage, connector mass, stencil apertures, panelization and THT/SMT sequencing with the assembler.

## 17. Preserve list

Preserve the macro outline, mounting holes, SXM2-left/CM5-right zoning, J1/J2 geometry subject to final pin-map check, PCIe Gen2 x1 architecture, PER0, PET0 raw legs/C1/C2, direct USB-A architecture, SERVICE connector location, J3/J4 concept, separate 5 V rails, distributed SXM2 feed, J8/TP3, and the six-layer stack family unless evidence changes.

## 18. Rip-up/rebuild list

Rebuild U16, Q1/Q2 protection, U4/U8, all USB ESD footprints and routes, all FAST-A/B USB3, all USB2 pairs, SERVICE DRP circuitry, all In1/In4 signals, all non-power In2/In3 signals, placement-dependent F1/Q1/F2/Q2 and J5/J6/J7 copper, TP1/TP2, and unjustified no-net keepouts.

## 19. Clean-in-place list

Keep and locally clean PER0, PET0/REFCLK trunks outside transition fields, U1 placement, the SXM2 feed concept, fan/UART/control routes after moves, zones after geometry stabilizes, and silkscreen/readability.

## 20. Dependency graph

```text
Approved PSU/cable envelope + mechanical models
                    |
                    v
M1 schematic/library truth
        |                     |
        v                     v
M2 floorplan          protection values locked
        |                     |
        +----------+----------+
                   v
               M3 power
                   |
                   v
             M4 layer policy
              /             \
             v               v
       M5 PCIe          M6 USB
              \         /
               v       v
             M7 controls/test
                   |
                   v
             M8 planes/returns
                   |
                   v
             M9 integrated validation
                   |
                   v
             M10 review package
```

## 21. Staged execution milestones

### M1 — Schematic and library truth

Modify schematic, symbol/footprint libraries, project rules and `bible.md`. Correct all P0 mappings and circuits, remove SERVICE DRP, and add test-point nets. Freeze PCB geometry. Pass requires zero ERC errors and an approved pin-map table.

### M2 — Mechanical/floorplan

Modify PCB and `bible.md`. Move F1/Q1/F2/Q2, J5/J6/J7, U16, port support and test-pad reservations. Freeze macro outline, J1/J2, PER0, J3/J4 and connector locations. Pass requires full 3D/courtyard clearance.

### M3 — Power implementation

Modify PCB, rules and `bible.md`. Implement branch protection, TVS/CIN/bulk positions, U1/U16, USB switches and V100 distribution. Pass requires polarity audit, current-width worksheet, regulator layout review and preliminary PI/thermal checks.

### M4 — Layer-policy conversion

Evacuate In1/In4, restrict In2/In3 to power, normalize vias, remove stale keepouts and refill zones. Pass requires zero tracks on In1/In4, zero signal tracks on In2/In3, and zero non-through vias.

### M5 — PCIe transitions

Repair PET0 post-cap and REFCLK transition clusters; preserve PER0 and raw PET0. Pass requires skew, reference-plane, return-via and SI review.

### M6 — USB rebuild

Rebuild FAST-A/B USB3, all USB2, corrected ESD and fixed-UFP SERVICE. Pass requires no signal opens, documented impedance/via budgets and CM5IO comparison.

### M7 — Controls and debug

Clean low-speed controls, fan/UART/recovery and add test pads. Pass requires direct topology and no high-speed stubs.

### M8 — Zones/returns

Finalize GND planes, power zones, return vias, ESD returns, SXM2 return arrays and connector stitching. Pass requires a functional via census and no orphan copper.

### M9 — Integrated verification

Run ERC, DRC, parity, SI, PI/current, thermal, mechanical, DFM and 3D review. No generic waiver may hide a true signal defect.

### M10 — RC package

Only after M9, regenerate BOM/CPL/Gerbers/drill/renders/receipts, update `bible.md`, verify hashes/checksums and produce the external-review package. This is not fabrication authorization.

## 22. Validation matrix

| Milestone | Required evidence |
|---|---|
| M1 | ERC, pin-map parity, TI/manufacturer circuit review |
| M2 | Courtyard, 3D, mating-housing and cable review |
| M3 | DRC, IPC-2152/current, PI, regulator and thermal review |
| M4 | Layer/via census, zone and copper-balance review |
| M5 | PCIe skew, SI, return-path and reference review |
| M6 | USB DRC, impedance/skew/via review, CM5IO comparison |
| M7 | Low-speed topology, probe-access and stub review |
| M8 | GND/return walk-through, zone-island and stitching census |
| M9 | Full ERC/DRC/parity/SI/PI/thermal/mechanical/DFM review |
| M10 | Source/output parity, checksums, archive and receipt verification |

## 23. External-review gate

All P0s closed; ERC zero errors; no true DRC signal, short, clearance, hole, keepout or differential defect; every remaining plane-context record individually explained; parity clean except approved connector abstractions; coherent layer policy; complete regulators; deliberate high-speed return paths; collision-free mechanics; documented cold-plug and two-connector policy; sufficient bring-up access; no stale architecture baggage; P1 and empirical risks disclosed.

## 24. Remaining empirical Rev-A risks

V100 pin mapping, common-clock behavior, reset/power sequencing, SXM2 current sharing, TVS/bulk values, regulator effective capacitance/thermal behavior, PCIe/USB compliance, board warpage, and connector temperature remain first-hardware or external-review risks. Bring-up must use current-limited power and staged load.

## 25. Final recommendation

`BOARD_NEEDS_MAJOR_REWORK`

The macro architecture is salvageable. Major rework is required because of verified pin-map/package defects, true USB discontinuities, reversed LM74700/MOSFET orientation, incomplete U16 circuitry, mechanical collisions, and incoherent signal use of ground-reference layers. No design or release file is changed by this plan.

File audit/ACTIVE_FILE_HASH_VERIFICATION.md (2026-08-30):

# Active-design hash verification

The architecture sanity audit was read-only with respect to the active design.

| File | Before audit | After audit | Result |
|---|---|---|---|
| `pisxme/PiSXMe.kicad_pcb` | `de3f3ff6e375029b62e4f4cd4285d9477d88a7dbf1137c34498adb9a6b580f4e` | `de3f3ff6e375029b62e4f4cd4285d9477d88a7dbf1137c34498adb9a6b580f4e` | IDENTICAL |
| `pisxme/PiSXMe.kicad_sch` | `b9ba4290d6274e85caf82b1111fd5f1badba00299a08014cec9e36bdbce92406` | `b9ba4290d6274e85caf82b1111fd5f1badba00299a08014cec9e36bdbce92406` | IDENTICAL |
| `pisxme/PiSXMe.kicad_dru` | `681a9397b053ed62c006af1e01f83fb4994368c1022a30ac9f2760edb727afd9` | `681a9397b053ed62c006af1e01f83fb4994368c1022a30ac9f2760edb727afd9` | IDENTICAL |

The USB-A board and all supporting routing artifacts are disposable and live
under `experiments/usb-a-simplification/`.

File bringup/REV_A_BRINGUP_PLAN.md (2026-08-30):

# PiSXMe Rev-A bring-up plan

Status: `PLANNING ONLY — DO NOT APPLY UNTIL RELEASE GATES CLOSE`

## Before installing CM5 or V100

1. Inspect the assembled board under magnification, especially the SXM2,
   CM5, HD3SS3212/DQA, USB-C, fuse, and Mini-Fit Jr joints.
2. Verify board revision, connector orientation, fuse values, R1 assembly
   choice, and cooler/backplate clearances.
3. Measure resistance from raw 12 V, protected 12 V, CM5 5 V, USB 5 V, and
   3V3 to ground. Do not power through an unexplained low resistance.
4. Check both input branches independently for shorts and correct fuse
   continuity. A single-branch-loss condition is an abort condition for a
   300 W V100 test.

## Current-limited power checks

Use a current-limited regulated 12 V source. With the V100 and CM5 absent,
verify raw/protected 12 V, CM5 5 V, USB 5 V, control enables, and regulator
temperature. Confirm SERVICE VBUS is disabled before connecting an external
recovery host.

## CM5-only bring-up

Install the CM5 with cooling/support hardware in place. Use the internal UART
first. Verify boot from eMMC on the recommended CM5 SKU, SERVICE USB2 host
operation, FAST-A/FAST-B USB3 enumeration, USB storage, USB Ethernet adapter,
fan/pump outputs, reset, and the documented `nRPIBOOT` recovery procedure.

For recovery/device mode, disable the board-side SERVICE VBUS source before
connecting the external provisioning host. Do not assume automatic role
handoff is safe until measured.

## V100 bring-up

Only after the host and cooling control are stable:

1. Install the V100 and cooler.
2. Verify both 12 V input branches are present and current-limited.
3. Confirm fans/pump are running before GPU enable.
4. Check PCIe enumeration with `lspci`.
5. Check the NVIDIA driver with `nvidia-smi`.
6. Start with a tiny workload and observe input current, connector/power
   temperatures, GPU temperature, and fan response.
7. Increase load gradually; abort on unexpected current imbalance, heating,
   loss of cooling, reset loops, or non-enumeration with abnormal rails.

The undocumented V100 endpoint/sequence behavior and exact sustained thermal
rise remain Rev-A empirical risks even after the PCB release gates close.

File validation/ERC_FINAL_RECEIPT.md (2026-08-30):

# Final ERC receipt — modular USB-C I/O revision

Date: 2026-08-21  
KiCad: `10.0.5`  
Project: `pisxme/PiSXMe.kicad_sch`  
Validation method: fresh lock-free copy of the complete `pisxme` project,
executed from the copied project directory with its project and local symbol/
footprint tables present.

## Commands

```text
/Applications/KiCad/KiCad.app/Contents/MacOS/kicad-cli sch erc \
  --format json --output validation/ERC_modular_usbc.json PiSXMe.kicad_sch

/Applications/KiCad/KiCad.app/Contents/MacOS/kicad-cli sch erc \
  --format report --output validation/ERC_modular_usbc.rpt PiSXMe.kicad_sch
```

The commands were run from a temporary project copy; the reports were copied
back to the workspace as receipts.

## Result

| Finding | Count | Classification |
|---|---:|---|
| ERC errors | **0** | pass |
| ERC warnings | **48** | all explained below |
| Multiple-net-name findings | **0** | pass; USB orientation branches are distinct |
| Pin-not-connected errors | **0** | pass; CM5 WAKE# and TPSM63606 NC are marked correctly |
| Dangling no-connect markers | **0** | pass |

Remaining warning groups:

- `footprint_link_issues`: 30. KiCad CLI 10.0.5 does not resolve the local
  `PiSXMe` nickname in its isolated validation context. The active board
  embeds the footprints and the source library is copied into the validation
  project; this is a reproducible CLI context limitation.
- `isolated_pin_label`: 18. These are intentional boundary/optional labels
  for documented power, debug, keepout, USB shield/NC, or CM5 interface
  contracts. They are not floating required electrical nets.

The generator's custom-symbol Y-coordinate defect was corrected. A generated
netlist audit confirms that USB-C FAST A/B RX1, TX1, RX2, and TX2 contacts
remain separate through their HD3SS3212 orientation paths, and that each
FAST USB2 companion pair joins its CM5 D+/D− pins through the connector-side
`TPD2EUSB30A` protection device.

## Gate result

**PASS WITH DOCUMENTED TOOL-CONTEXT WARNINGS.** There are zero errors, zero
multiple-net conflicts, zero unexplained warnings, and zero warnings requiring
a design change. This receipt validates the placement-study schematic; it is
not a substitute for the routed-board ERC pass in the next phase.

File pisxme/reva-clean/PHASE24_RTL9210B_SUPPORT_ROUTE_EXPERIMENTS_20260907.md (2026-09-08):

# RTL9210B support-fixture route experiments — 2026-09-07

## Current 2026-09-08 state — V562/V570

V562 is the retained corrected support baseline. It regenerates the complete
The V35 rotated-U1 support reference was natively re-saved after zone refill
as `PHASE24_RTL9210B_SUPPORT_CLUSTER_MOVE_V35_NATIVE_REFILLED`. Current DRC
is 4 inherited warnings; SPI and XTAL/RSET native audits plus independent
trace-removal controls pass. Retain this as the current source-field reference
for re-authoring, not as production closure.
The V35-derived RTL_5V probes V1/V2 are rejected route-allocation trials.
V2's native DRC has 15 findings, including RTL_5V crossings with SPISI and
RTL_3V3, a QFN-edge contact, and dangling segments. Preserve the raw boards
and receipt; do not interpret this as evidence against the V35 source-field
placement. See `PHASE24_RTL9210B_V35_SOURCE_FIELD_REPORT.md`.
V4 is retained as the RTL_5V sub-primitive: U1.17/U1.33/C5.1 native
connectivity and the trace-removal negative control pass, with native DRC at
the four inherited warnings. The remaining 32 opens are other Path-B support
and external connections, not evidence that RTL_5V is closed globally.
RTL_1V1 field from the saved V342 source without copying duplicate RSET or
crystal copper; native connectivity and the route/zone negative control pass
for all eight U1 1V1 pads plus C4.1. Its native DRC remains open.

V563–V565 reject RTL_5V source classes: west outer F.Cu, lower outboard
F.Cu/B.Cu, and local In2 plane. V566–V569 reject successive local,
upper/lower, and bypass variations. V570 is the best current 5V topology:
U1.17/U1.33/C5.1 are natively connected and the trace-removal negative
control fails as required; native DRC has no shorting or crossing classes.
It still reports 16 violations, including QFN/pad-field and other clearance
findings, so it is not a production-clean candidate. The next action is a
coherent reallocation of the shared QFN source field, not another long 5V
collector. Path A and production CAD remain untouched.

V571 attempted that reallocation by rebuilding the RTL_3V3 field with U1.34
handed east toward U1.39, then reused the V570 5V loop. The saved-board audit
failed the complete 3V3 endpoint group, and native DRC retained QFN/pad-field
clearance plus solder-mask findings. Reject V571; its failed audit is evidence
against this specific east handoff, not against RTL9210B or Path A.

V572 corrects V571's missing In2 bridge and replaces the diagonal U1.34-to-
U1.39 escape with a Manhattan handoff. The native audit passes both complete
5V and 3V3 endpoint groups and both trace-removal negative controls. Native
DRC improves to 14 findings with no shorting or crossing classes, but QFN/
pad-field clearance and inherited support findings remain. Retain V572 as
the current disposable candidate; it is not production-clean.

V573 moved only the lower RTL_5V transition away from U1 pads 31/32, but
native DRC found a short to the retained RTL_3V3 In2 spine. V574 moved the
3V3 spine around that via and reduced native DRC to 12 findings with no
shorting or crossing classes, but its independent saved-board audit failed
the complete 3V3 endpoint group. Reject V573/V574; V572 remains the retained
connected baseline.
V576 restores the two omitted physical In2 3V3 bridges on the V574 coupled
field. Native audits pass complete 5V and 3V3 endpoint groups with independent
trace-removal negative controls. Native DRC remains at 12 findings with no
shorting or crossing classes; retain V576 as the current connected disposable
candidate, not production closure.
V578 replaced the first U1.33 5V departure with an exact-horizontal segment.
Native saved-board connectivity showed dangling 5V branches and DRC still
reported the pad-32 clearance violation. Reject V578; retain V576 as the best
connected candidate. The strict QFN edge escape remains open.
V577 edited the existing V576 U1.34 handoff natively by 0.05 mm. Native DRC
rose to 13 findings and still reported the strict pad-33/pad-34 source-field
clearance and pad-35 clearance. Reject V577; retain V576. The limiting
condition is the intrinsic 0.4 mm QFN edge field, not a missing saved-net
association.
V575 shifted the U1.34 3V3 departure by 0.05 mm on the V574 lineage. Native
DRC retained strict source-field clearance, and the regenerated 3V3 branches
were dangling in saved-board connectivity. Reject V575; the next step is
coordinated QFN escape authoring rather than another scalar coordinate nudge.

V579 removes the diagonal source departure: U1.33 runs straight to an
outboard transition while the V576 coupled 3V3 network is retained. Native
5V/3V3 audits and both trace-removal negative controls pass. Native DRC is
11 findings with 20 opens; the 5V source group is no longer open. Retain
V579 as the current RTL_5V/3V3 candidate, not full Path-B closure.

## Current state and documentation hygiene
V582 re-centered the lower RTL_3V3 In2 spine in the measured gap between the
neighboring RSET and 1V1 transitions. Native 5V/3V3 audits and both
trace-removal negative controls pass; native DRC falls to 10 findings with
19 opens and no shorting or crossing classes. Retain V582 as the current
Path-B rail candidate, not full support closure.
V583 moved only the upper RTL_5V B.Cu corridor from y=50.5 to y=49.5 to
clear the 3V3 via. Native 5V/3V3 audits and both trace-removal negative
controls pass; native DRC falls to 9 findings with 19 opens and no 5V
shorting/crossing or clearance class. Retain V583 as the current rail
candidate, not full Path-B closure.
V589 is rejected: the attempted local B.Cu PEDET route from R2.1 toward U1.8
crossed the retained RTL_5V vertical corridor and RTL_1V1 field. Native DRC
reported 13 violations and 18 opens. The lower open count does not outweigh
the true crossings; PEDET needs a new local source/escape allocation.
V594 completes the full PEDET path with an all-F.Cu outer perimeter. Native
saved-board connectivity joins J1.69, R2.1, and U1.8; the independent
trace-removal negative control fails as required. Native DRC returns to 9
findings with no PEDET crossing. Retain V594 as the current disposable
PEDET-plus-rail candidate, not production closure.
V595 adds the local R3.1→U1.13 CLKREQ escape on F.Cu. Native saved-board
connectivity and its trace-removal negative control pass; native DRC remains
at 9 findings with no new crossing. Retain V595 as the current disposable
PEDET/CLKREQ-plus-rail candidate, not production closure.
V596 is rejected because its proposed SPICS transition occupied the existing
RTL_3V3 via field. V597 is rejected because its all-F.Cu SPICS staircase
crossed the 1V1 escape and shorted SPICS into RTL_3V3. These are route
implementation failures; the next SPI attempt needs a real corridor allocation.
V598 is rejected because its B.Cu transition shorted SPICS to retained 1V1
and 5V fields. V599 is rejected because its direct F.Cu outer departure
crossed the PEDET/5V/3V3/CLKREQ source field. The next pass must co-author the
shared QFN escape rather than add another scalar SPI detour.
V600 is rejected because direct SPI lines after a U2 rotation ran through
U1's interleaved power/control pads. V601 is rejected because its SPISI
transition occupied the RTL_3V3 In2 field. V602 moves the transition west;
U1.18→U2.5 connectivity and its trace-removal negative control pass, while
native DRC is 10 findings with no new short/crossing. Retain V602 as the
SPISI sub-primitive, not full SPI closure.
V603 is rejected because its SPISO3 endpoint entered the lower RTL_3V3 field
and crossed 1V1. V604 moved the endpoint west but crossed/shorted the retained
SPISI launch. The next pass must co-author all SPI source and endpoint channels.
V605/V606/V607/V608 reject successive SPISO3 channel allocations: the first
crossed SPISI, the next two entered lower power or endpoint clearance, and
V608 still collided at the U2 SPICLK pad launch. The remaining SPI task is a
co-authored U1 source plus U2 endpoint dogbone field.
V617-V619 reject SPICLK source/channel variants: source dogbone crossings
persisted against SPISI/RTL_5V even after moving the channel above the retained
field, and lower endpoint transitions entered 3V3. The next pass must
co-author the complete U1 QFN SPI source field.
V616 is rejected: its SPISO lower corridor crossed retained SPISO3/SPISI
channels and its source transition violated the 3V3 clearance envelope. The
remaining SPI task requires complete five-net allocation or coherent U2
support relocation.
V609-V614 rejected successive coordinated SPISI/SPISO3 endpoint variants for
U2 ground, occupied-via, or lower-field contact/clearance. V615 lifts the
SPISI bottom dogbone; both nets pass native connectivity and independent
trace-removal negative controls, with DRC at 10 inherited/local findings and
no new short/crossing. Retain V615 as the coordinated two-net sub-primitive.
V580 attempted ordinary-via returns for U1 ground pads 69, 45, and 66.
Native DRC rejected the placement with true GND-to-USB/3V3 shorts and local
QFN clearance violations. Reject V580; V579 remains the retained rail
candidate.

The JMS583 support network is already instantiated in the live authoritative
storage schematic and in the disposable support candidates. Any earlier note
in this record saying it still needs instantiation is historical/superseded,
not a current TODO. The current promoted rail/control disposable basis is V137
with V131/V122 support sub-primitives; V100 remains historical 1V1 evidence.
Path A and production CAD remain preserved.

## V132–V137 RTL_5V completion trials

V132–V136 are rejected route-allocation experiments. V132 reused an old
RTL_5V path and shorted retained RTL_1V1/CLKREQ fields; V133 co-authored the
rail above SPI but retained an RTL_1V1 short and PERST crossing; V134 hit
ground and CLKREQ vias; V135 entered the inherited CLKREQ corridor and C5
ground; V136 removed the PERST crossing but still contacted CLKREQ. These
reject those geometries only, not RTL9210B.

V137 starts from V131, keeps the validated CLKREQ overpass, and sends the C5
branch below the local control field before returning to C5.1. Native saved
connectivity joins C5.1/U1.17/U1.33. The focused audit and trace-removal
negative control pass, and the native report has no `shorting_items` or
`tracks_crossing`. Promote V137 only as the disposable RTL_5V
sub-primitive; inherited zone/manufacturing/open-support findings remain
unclosed.

V138 and V139 reapply the earlier U1.34 RTL_3V3 handoff on V137. Both join
U1.34 to C3/R2/R3/U1.20 in saved-board connectivity. V138 shorts the promoted
RTL_5V source field; V139 avoids that field but crosses SPISO3. Reject both as
route-allocation evidence. U1.34 remains an open endpoint.
V140 moves the U1.34 source left and raises its B.Cu corridor. It still
shorts SPISO and leaves a crossing in native DRC, so it is rejected. The
remaining U1.34 issue is allocation of the shared QFN source field on the
promoted V137 basis, not missing saved-board connectivity.

## V141 M.2 SSD_3V3 contact-row sub-primitive

V141 joins J1.2/J1.4/J1.6/J1.8 on the V137 basis using native pad-derived
F.Cu segments. Native DRC reports no `shorting_items` or `tracks_crossing`;
the saved-board audit and trace-removal negative control pass. This is only
the M.2 contact collector. It does not close the SSD_3V3 source, inrush,
power-budget, or complete Path-B power gate.

## V142–V143 U1.34 RTL_3V3 source-field allocation

V142 raised the U1.34 B.Cu corridor but contacted the retained SPICS via and
is rejected. V143 moves the source outside the V137 RTL_5V field and takes a
higher outer B.Cu path. Native DRC reports no `shorting_items` or
`tracks_crossing`; the native audit joins U1.34/C3/R2/R3/U1.20 and the
trace-removal negative control fails as required. Promote V143 only as the
U1.34 disposable sub-primitive; complete Path-B closure is still open.

## V144 combined support basis

V144 starts from V143 and reapplies the V141 socket-contact collector. Native
saved connectivity and the negative control pass for both U1.34 RTL_3V3 and
J1.2/J1.4/J1.6/J1.8; native DRC has no `shorting_items` or
`tracks_crossing`. Six intended high-speed endpoint opens remain, and the
SSD_3V3 source/power gate is not closed.
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

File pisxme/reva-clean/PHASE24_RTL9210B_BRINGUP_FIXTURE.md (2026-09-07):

# RTL9210B-CG isolated bring-up fixture — 2026-09-07

Status: **ISOLATED DESIGN-EVIDENCE FIXTURE; NOT PRODUCTION CAD**

Generated by `phase24_make_rtl9210b_bringup_fixture.py` and audited by
`phase24_rtl9210b_bringup_fixture_audit.py`. It is separate from
`STORAGE.kicad_sch` and the clean acreage PCB.

## Captured authority

- corrected RTL9210B-CG qualification SMD QFN-68 footprint, including exposed
  chip pad 69 on `GND`;
- one M-key 2280 socket boundary;
- lane-0 mapping: RTL 68/67 → M.2 49/47 and RTL 64/65 ← M.2 43/41;
- PCIe REFCLK 61/62 → contacts 55/53;
- PERST/CLKREQ → contacts 50/52;
- PEDET pin 8 ↔ M.2 contact 69;
- USB2/USB3, 5 V/3.3 V/1.1 V, RSET, ISOLATEB, clock, SPI flash, reset,
  decoupling, pull-up, SSD-power, and programming/test net boundaries;
- accessible SPI, reset, UART, and ground test pads.

The fixture deliberately does not invent a Realtek application-circuit value
or firmware image. Support components are boundary footprints and named nets;
their final placement/value/layout still requires the authorized/current
application circuit and a traceable prototype part.

## Native result

```text
phase24_rtl9210b_bringup_fixture_audit.py                    PASS
phase24_rtl9210b_bringup_fixture_audit.py --negative-control PASS (fails as intended)
native KiCad DRC                                              0 violations
native KiCad unconnected items                                56 (expected)
```

The 56 unconnected items are intentional at this stage: the fixture captures
the support-net/pad boundary but does not claim routed high-speed copper or a
completed power/return implementation. No shorts, crossings, footprint-rule
violations, or library-resolution warnings remain in the saved DRC report.
The open items are not silently waived; they are the explicit next fixture
gate before any hardware order or production promotion.

## Promotion boundary

This closes the isolated design-evidence step for the corrected package and
mapping. It does not close virgin-chip programming, firmware provenance,
application-circuit authority, SSD 3.3-V inrush/thermal proof, or hardware
SATA/NVMe mode validation. Path A remains intact and the fixture is not used
as a reason to alter the clean board.

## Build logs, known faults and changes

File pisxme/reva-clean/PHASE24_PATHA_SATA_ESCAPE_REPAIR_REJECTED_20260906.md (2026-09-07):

# Phase 24 Path-A SATA escape repair — rejected 2026-09-06

## Classification

`ROUTE_IMPLEMENTATION_FAILURE`. These disposable native experiments did not
change the selected storage architecture, production CAD, or committed mono2
author.

## Experiments

| Candidate | Native DRC findings | Result |
|---|---:|---|
| `PHASE24_U7_REPAIRED_ESCAPES_20260906` | 22 | Rejected |
| `PHASE24_U7_REPAIRED_ESCAPES_V2_20260906` | 23 | Rejected |

The first variant introduced an RX_P-to-U7 power-ground short and TX pair
crossing near the U7 oscillator field. The second moved the TX vias and put
RX_P on B.Cu, but introduced additional crossings and shorts against U7
BRIDGE_1V1/VSSOSC/XO/RX_N geometry. Neither is evidence that the storage
architecture or macro-floorplan is impossible.

## Decision

Both candidates are preserved as raw reports and rejected. The author
`phase24_storage_sata_pair_corridor.py` was restored to the committed mono2
source-order baseline. The next repair must use coordinated QFN escape
channel allocation around the actual pad field, rather than isolated via
translation.

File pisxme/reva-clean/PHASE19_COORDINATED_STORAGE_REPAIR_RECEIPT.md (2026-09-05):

# Phase 19 coordinated storage-island repair receipt

Date: 2026-09-04
Status: `REJECTED_EXPERIMENT`; Phase 19 remains active.

## Authoring-path correction

`phase19_storage_coordinated_fresh.py` now removes donor C30-C33 footprints
before loading the project-local `C_0402_1005Metric` footprint. The Phase 18
ancestor already uses those references for unrelated regulator capacitors.
New socket-side nets receive explicit net codes and are attached to C30-C33
and J3 before the KiCad 10 synchronization save/reload; otherwise KiCad emits
blank or stale unconnected nets.

## Disposable candidate

Candidate: U7 `(150,140)`, rotation 180 degrees; J3 `(180,125)`, rotation 90
degrees; regenerated USB3 and four SATA split-cap paths from the Phase 18
ancestor.

Native evidence:

* generator completed under KiCad 10 Flatpak Python;
* J3 pads 1-4 serialize as `SATA_M2_TX_P/N` and `SATA_M2_RX_P/N`;
* C30 pad 1 is socket-side and pad 2 is bridge-side;
* native DRC: 262 violations, including candidate-introduced SATA launch
  crossings/shorts and interactions with inherited CM5/PERST copper.

The candidate is rejected and is not promoted to the clean acreage board. The
corrected generic authoring path is retained for the next experiment.

## Accepted coordinated V3 continuation (2026-09-05)

The moved-U7 V3 USB3 route was retained and combined with the four
manufacturer-selected inline 0402 SATA coupling capacitors. A local TX_P and
RX_P length-match correction produced
`PHASE19_V3_USB_PROVEN_SPLIT_SATA_TX_MATCH_REFILL.kicad_pcb`.

Native DRC is 190 / 418 versus the inherited V3 198 / 430, with zero focused
crossings or shorts and unchanged PCIe geometry. End-to-end SATA pair skew is
1.200 mm RX and 0.134 mm TX; USB3 maximum pair skew is 3.083 mm. All twelve
high-speed nets use the 0.13208-mm routed width and only F.Cu/B.Cu signal
layers. C30-C33 and J3 serialize the intended split-net path. This is the
accepted Phase 19 acreage checkpoint under inherited-baseline qualification.

## Follow-up escape refinement

The generator was then changed to derive the USB3 landing from serialized U7
coordinates and to avoid routing through the vertical QFN pad field. The
USB-only V3 disposable run completed and reduced the report to 200 native DRC
violations, but retained inherited CM5/PCIe source-corridor crossings and one
candidate USB transition interaction. It is also rejected; the PCIe ancestor
remains unchanged.

## Coordinated corridor refinement

The next V3 run used the corrected USB3 escape, four rotated 0402 coupling
parts, split-net SATA routes, and separate F.Cu/B.Cu pair corridors. Native
DRC measured 206 violations. The candidate still has one stale J3 auxiliary
pad short and two local/PCIe corridor crossings, so it is rejected and not
promoted.

## Best current synchronized corridor

The refined USB3 TX_P lower-corridor escape and separated SATA cap lanes
produced `PHASE19_LIVE3.kicad_pcb`. Native DRC measured 207 violations, with
zero `shorting_items` records and one remaining `tracks_crossing` record in
the USB3 source/landing corridor; inherited clearance, hole, and
unconnected-acreage debt remains. It is not promoted because Phase 19
requires zero true crossings and clean connector/mechanical clearance.

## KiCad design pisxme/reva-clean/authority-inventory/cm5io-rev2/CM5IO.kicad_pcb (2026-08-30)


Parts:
C9, C18: 100n; C_0402_1005Metric; Part Description 0.1uF 10% 16V Ceramic Capacitor X7R 040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
H1, H2, H3, H4, H5, H6, H7, H8: MountingHole; MountingHole_2.7mm_M2.5_DIN965; Part Description M2.5 mounting hole; not fitted
J11: USB_C_Receptacle_USB2.0; USB_C_Receptacle_GCT_USB4105-xx-A_16P_TopMnt_Horizontal; Part Description USBC USB2 data and power connector
R9: 2.2K 1%; R_0402_1005Metric; Part Description Resistor 2.2K M1005 1% 63mW

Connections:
/+5v: C9.1, C18.1, J11.A4 (VBUS), J11.A9 (VBUS), J11.B4 (VBUS), J11.B9 (VBUS), R9.1; also elsewhere on the board
/CC1: J11.A5 (CC1); also elsewhere on the board
/CC2: J11.B5 (CC2); also elsewhere on the board
/USB2_N: J11.A7 (D-), J11.B7 (D-); also elsewhere on the board
/USB2_P: J11.A6 (D+), J11.B6 (D+); also elsewhere on the board
GND: C9.2, C18.2, J11.A1 (GND), J11.A12 (GND), J11.B1 (GND), J11.B12 (GND), J11.S1 (SHIELD), R9.2; also elsewhere on the board

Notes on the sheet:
Connectors ------- Ethernet SDCARD 40way RPI Jumpers Fan Battery
Connectors ------ M2 MKey
Discharge Resistor Needed by some Type C PSUs
TypeC Power connector
Connectors ------- HDMI 0 HDMI 1 CSI/DSI 0 CSI/DSI 1

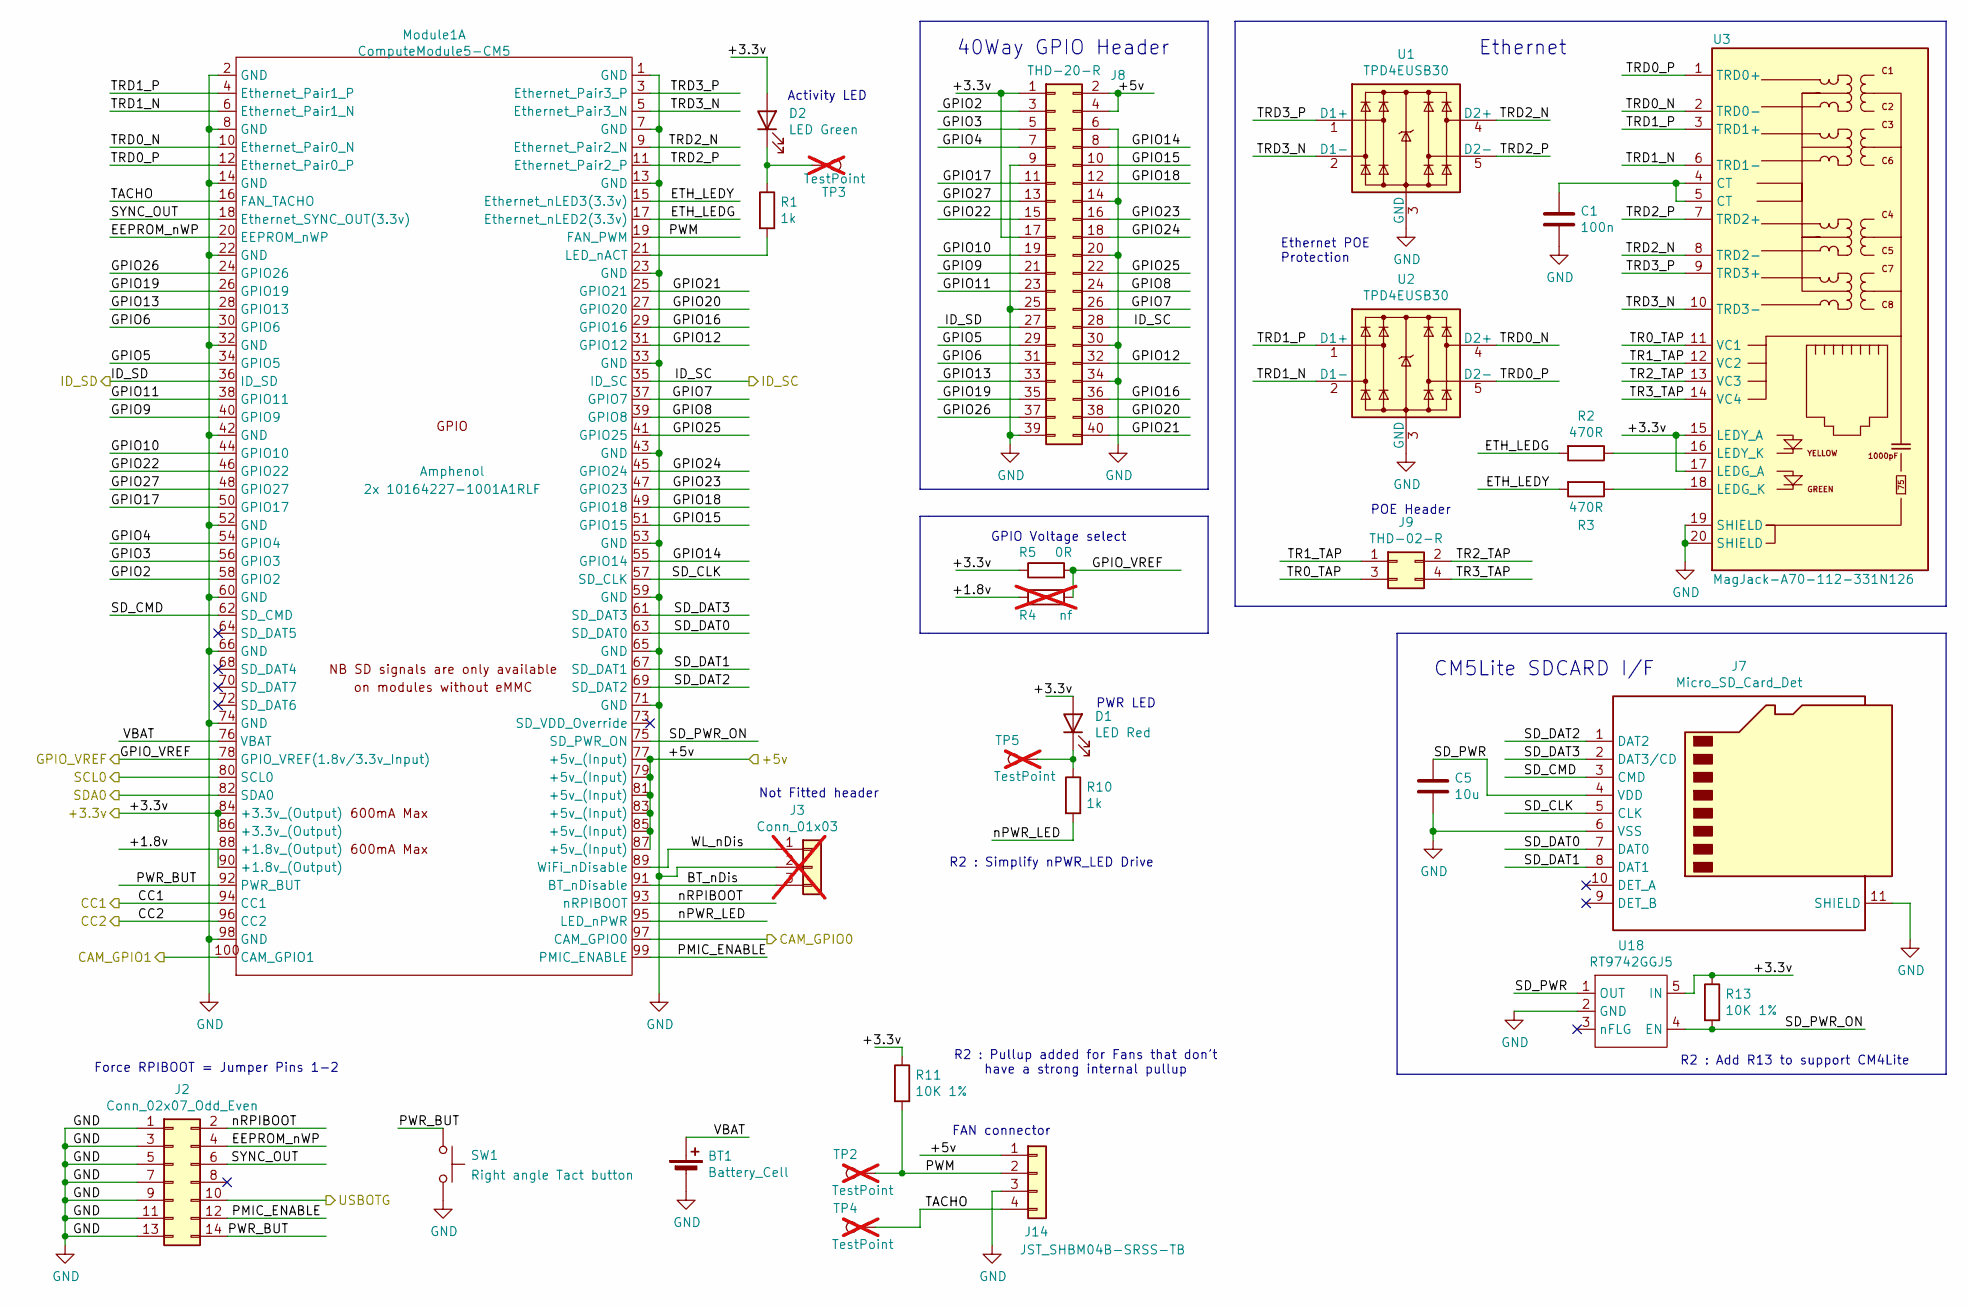
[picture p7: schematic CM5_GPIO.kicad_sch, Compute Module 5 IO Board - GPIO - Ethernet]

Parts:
BT1: Battery_Cell; BatteryHolder_Keystone_3034_1x20mm; Part Description Battery Retainer Coin, 20.0mm 1 Cell SM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
C1: 100n; C_0402_1005Metric; Part Description 0.1uF 10% 16V Ceramic Capacitor X7R 040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
C5: 10u; C_0805_2012Metric; Part Description 10uF 10% 10V Ceramic Capacitor X7R 0805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
D1: LED Red; LED_0603_1608Metric; Part Description Red 620nm LED Indication - Discrete 2.2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
D2: LED Green; LED_0603_1608Metric; Part Description Green 572nm LED Indication - Discrete 2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
J2: Conn_02x07_Odd_Even; PinHeader_2x07_P2.54mm_Vertical; Part Description PinHeader_2x07_P2.54mm_Vertical
J3: Conn_01x03; PinHeader_1x03_P2.54mm_Vertical; Part Description 3pin 0.1" connector; not fitted
J7: Micro_SD_Card_Det; SDCARD_MOLEX_503398-1892; Part Description 9 (8 + 1) Position Card Connector micro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
J8: THD-20-R; PinHeader_2x20_P2.54mm_Vertical; Part Description PinHeader_2x20_P2.54mm_Vertical
J9: THD-02-R; PinHeader_2x02_P2.54mm_Vertical; Part Description PinHeader_2x02_P2.54mm_Vertical
J14: JST_SHBM04B-SRSS-TB; JST_SH_BM04B-SRSS-TB_1x04-1MP_P1.00mm_Vertical; Part Description 4 pin vertical 1mm pitch connector
Module1: ComputeModule5-CM5; Raspberry-Pi-5-Compute-Module; Part Description 100 Position Connector Receptacle, Cent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
R1, R10: 1k; R_0402_1005Metric; Part Description Resistor 1K M1005 1% 63mW
R2, R3: 470R; R_0402_1005Metric; Part Description Resistor 470R M1005 1% 63mW
R4: nf; R_0805_2012Metric_Pad1.20x1.40mm_HandSolder; not fitted
R5: 0R; R_0805_2012Metric_Pad1.20x1.40mm_HandSolder; Part Description Resistor 0R M2012 5%
R11, R13: 10K 1%; R_0402_1005Metric; Part Description Resistor 10K M1005 1% 63mW
SW1: Right angle Tact button; SW_Tactile_SPST_Angled_PTS645Vx58-2LFS; Part Description Right angle through hole Tact switch
TP2, TP3, TP4, TP5: TestPoint; TestPoint_Pad_2.0x2.0mm; Part Description Test point; not fitted
U1, U2: TPD4EUSB30; USON-10_2.5x1.0mm_P0.5mm; Part Description Quad TVS diode for high speed signals (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
U3: MagJack-A70-112-331N126; TRJG0926HENL; Part Description Gigabit Ethernet Magjack
U18: RT9742GGJ5; SOT-23-5; Part Description Power Switch/Driver 1:1 N-Channel 1A TS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

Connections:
/+3.3v: D1.2 (A), D2.2 (A), J8.1, J8.17, Module1.84 (+3.3v_(Output)), Module1.86 (+3.3v_(Output)), R5.1, R11.1, R13.1, U3.15 (LEDY_A), U3.17 (LEDG_A), U18.5 (IN); also elsewhere on the board
/+5v: J8.2, J8.4, J14.1, Module1.77 (+5v_(Input)), Module1.79 (+5v_(Input)), Module1.81 (+5v_(Input)), Module1.83 (+5v_(Input)), Module1.85 (+5v_(Input)), Module1.87 (+5v_(Input)); also elsewhere on the board
/CC1: Module1.94 (CC1); also elsewhere on the board
/CC2: Module1.96 (CC2); also elsewhere on the board
/CM5_GPIO ( Ethernet, GPIO, SDCARD)/+1.8v: Module1.88 (+1.8v_(Output)), Module1.90 (+1.8v_(Output)), R4.1
/CM5_GPIO ( Ethernet, GPIO, SDCARD)/BT_nDis: J3.3, Module1.91 (BT_nDisable)
/CM5_GPIO ( Ethernet, GPIO, SDCARD)/CAM_GPIO0: Module1.97 (CAM_GPIO0); also elsewhere on the board
/CM5_GPIO ( Ethernet, GPIO, SDCARD)/CAM_GPIO1: Module1.100 (CAM_GPIO1); also elsewhere on the board
/CM5_GPIO ( Ethernet, GPIO, SDCARD)/EEPROM_nWP: J2.4, Module1.20 (EEPROM_nWP)
/CM5_GPIO ( Ethernet, GPIO, SDCARD)/ETH_LEDG: Module1.17 (Ethernet_nLED2(3.3v)), R2.2
/CM5_GPIO ( Ethernet, GPIO, SDCARD)/ETH_LEDY: Module1.15 (Ethernet_nLED3(3.3v)), R3.2
/CM5_GPIO ( Ethernet, GPIO, SDCARD)/GPIO2: J8.3, Module1.58 (GPIO2)
/CM5_GPIO ( Ethernet, GPIO, SDCARD)/GPIO3: J8.5, Module1.56 (GPIO3)
/CM5_GPIO ( Ethernet, GPIO, SDCARD)/GPIO4: J8.7, Module1.54 (GPIO4)
/CM5_GPIO ( Ethernet, GPIO, SDCARD)/GPIO5: J8.29, Module1.34 (GPIO5)
/CM5_GPIO ( Ethernet, GPIO, SDCARD)/GPIO6: J8.31, Module1.30 (GPIO6)
/CM5_GPIO ( Ethernet, GPIO, SDCARD)/GPIO7: J8.26, Module1.37 (GPIO7)
/CM5_GPIO ( Ethernet, GPIO, SDCARD)/GPIO8: J8.24, Module1.39 (GPIO8)
/CM5_GPIO ( Ethernet, GPIO, SDCARD)/GPIO9: J8.21, Module1.40 (GPIO9)
/CM5_GPIO ( Ethernet, GPIO, SDCARD)/GPIO10: J8.19, Module1.44 (GPIO10)
/CM5_GPIO ( Ethernet, GPIO, SDCARD)/GPIO11: J8.23, Module1.38 (GPIO11)
/CM5_GPIO ( Ethernet, GPIO, SDCARD)/GPIO12: J8.32, Module1.31 (GPIO12)
/CM5_GPIO ( Ethernet, GPIO, SDCARD)/GPIO13: J8.33, Module1.28 (GPIO13)
/CM5_GPIO ( Ethernet, GPIO, SDCARD)/GPIO14: J8.8, Module1.55 (GPIO14)
/CM5_GPIO ( Ethernet, GPIO, SDCARD)/GPIO15: J8.10, Module1.51 (GPIO15)
/CM5_GPIO ( Ethernet, GPIO, SDCARD)/GPIO16: J8.36, Module1.29 (GPIO16)
/CM5_GPIO ( Ethernet, GPIO, SDCARD)/GPIO17: J8.11, Module1.50 (GPIO17)
/CM5_GPIO ( Ethernet, GPIO, SDCARD)/GPIO18: J8.12, Module1.49 (GPIO18)
/CM5_GPIO ( Ethernet, GPIO, SDCARD)/GPIO19: J8.35, Module1.26 (GPIO19)
/CM5_GPIO ( Ethernet, GPIO, SDCARD)/GPIO20: J8.38, Module1.27 (GPIO20)
/CM5_GPIO ( Ethernet, GPIO, SDCARD)/GPIO21: J8.40, Module1.25 (GPIO21)
/CM5_GPIO ( Ethernet, GPIO, SDCARD)/GPIO22: J8.15, Module1.46 (GPIO22)
/CM5_GPIO ( Ethernet, GPIO, SDCARD)/GPIO23: J8.16, Module1.47 (GPIO23)
/CM5_GPIO ( Ethernet, GPIO, SDCARD)/GPIO24: J8.18, Module1.45 (GPIO24)
/CM5_GPIO ( Ethernet, GPIO, SDCARD)/GPIO25: J8.22, Module1.41 (GPIO25)
/CM5_GPIO ( Ethernet, GPIO, SDCARD)/GPIO26: J8.37, Module1.24 (GPIO26)
/CM5_GPIO ( Ethernet, GPIO, SDCARD)/GPIO27: J8.13, Module1.48 (GPIO27)
/CM5_GPIO ( Ethernet, GPIO, SDCARD)/GPIO_VREF: Module1.78 (GPIO_VREF(1.8v/3.3v_Input)), R4.2, R5.2; also elsewhere on the board
/CM5_GPIO ( Ethernet, GPIO, SDCARD)/ID_SC: J8.28, Module1.35 (ID_SC); also elsewhere on the board
/CM5_GPIO ( Ethernet, GPIO, SDCARD)/ID_SD: J8.27, Module1.36 (ID_SD); also elsewhere on the board
/CM5_GPIO ( Ethernet, GPIO, SDCARD)/PMIC_ENABLE: J2.12, Module1.99 (PMIC_ENABLE)
/CM5_GPIO ( Ethernet, GPIO, SDCARD)/PWM: J14.2, Module1.19 (FAN_PWM), R11.2, TP2.1
/CM5_GPIO ( Ethernet, GPIO, SDCARD)/PWR_BUT: J2.14, Module1.92 (PWR_BUT), SW1.1
/CM5_GPIO ( Ethernet, GPIO, SDCARD)/SD_CLK: J7.5 (CLK), Module1.57 (SD_CLK)
/CM5_GPIO ( Ethernet, GPIO, SDCARD)/SD_CMD: J7.3 (CMD), Module1.62 (SD_CMD)
/CM5_GPIO ( Ethernet, GPIO, SDCARD)/SD_DAT0: J7.7 (DAT0), Module1.63 (SD_DAT0)
/CM5_GPIO ( Ethernet, GPIO, SDCARD)/SD_DAT1: J7.8 (DAT1), Module1.67 (SD_DAT1)
/CM5_GPIO ( Ethernet, GPIO, SDCARD)/SD_DAT2: J7.1 (DAT2), Module1.69 (SD_DAT2)
/CM5_GPIO ( Ethernet, GPIO, SDCARD)/SD_DAT3: J7.2 (DAT3/CD), Module1.61 (SD_DAT3)
/CM5_GPIO ( Ethernet, GPIO, SDCARD)/SD_PWR: C5.1, J7.4 (VDD), U18.1 (OUT)
/CM5_GPIO ( Ethernet, GPIO, SDCARD)/SD_PWR_ON: Module1.75 (SD_PWR_ON), R13.2, U18.4 (EN)
/CM5_GPIO ( Ethernet, GPIO, SDCARD)/SYNC_OUT: J2.6, Module1.18 (Ethernet_SYNC_OUT(3.3v))
/CM5_GPIO ( Ethernet, GPIO, SDCARD)/TACHO: J14.4, Module1.16 (FAN_TACHO), TP4.1
/CM5_GPIO ( Ethernet, GPIO, SDCARD)/TR0_TAP: J9.3, U3.11 (VC1)
/CM5_GPIO ( Ethernet, GPIO, SDCARD)/TR1_TAP: J9.1, U3.12 (VC2)
/CM5_GPIO ( Ethernet, GPIO, SDCARD)/TR2_TAP: J9.2, U3.13 (VC3)
/CM5_GPIO ( Ethernet, GPIO, SDCARD)/TR3_TAP: J9.4, U3.14 (VC4)
/CM5_GPIO ( Ethernet, GPIO, SDCARD)/TRD0_N: Module1.10 (Ethernet_Pair0_N), U2.4 (D2+), U2.7, U3.2 (TRD0-)
/CM5_GPIO ( Ethernet, GPIO, SDCARD)/TRD0_P: Module1.12 (Ethernet_Pair0_P), U2.5 (D2-), U2.6, U3.1 (TRD0+)
/CM5_GPIO ( Ethernet, GPIO, SDCARD)/TRD1_N: Module1.6 (Ethernet_Pair1_N), U2.2 (D1-), U2.9, U3.6 (TRD1-)
/CM5_GPIO ( Ethernet, GPIO, SDCARD)/TRD1_P: Module1.4 (Ethernet_Pair1_P), U2.1 (D1+), U2.10, U3.3 (TRD1+)
/CM5_GPIO ( Ethernet, GPIO, SDCARD)/TRD2_N: Module1.9 (Ethernet_Pair2_N), U1.4 (D2+), U1.7, U3.8 (TRD2-)
/CM5_GPIO ( Ethernet, GPIO, SDCARD)/TRD2_P: Module1.11 (Ethernet_Pair2_P), U1.5 (D2-), U1.6, U3.7 (TRD2+)
/CM5_GPIO ( Ethernet, GPIO, SDCARD)/TRD3_N: Module1.5 (Ethernet_Pair3_N), U1.2 (D1-), U1.9, U3.10 (TRD3-)
/CM5_GPIO ( Ethernet, GPIO, SDCARD)/TRD3_P: Module1.3 (Ethernet_Pair3_P), U1.1 (D1+), U1.10, U3.9 (TRD3+)
/CM5_GPIO ( Ethernet, GPIO, SDCARD)/USBOTG: J2.10; also elsewhere on the board
/CM5_GPIO ( Ethernet, GPIO, SDCARD)/VBAT: BT1.1 (+), Module1.76 (VBAT)
/CM5_GPIO ( Ethernet, GPIO, SDCARD)/WL_nDis: J3.1, Module1.89 (WiFi_nDisable)
/CM5_GPIO ( Ethernet, GPIO, SDCARD)/nPWR_LED: Module1.95 (LED_nPWR), R10.2
/CM5_GPIO ( Ethernet, GPIO, SDCARD)/nRPIBOOT: J2.2, Module1.93 (nRPIBOOT)
/CM5_HighSpeed/SCL0: Module1.80 (SCL0); also elsewhere on the board
/CM5_HighSpeed/SDA0: Module1.82 (SDA0); also elsewhere on the board
GND: BT1.2 (-), C1.2, C5.2, J2.1, J2.3, J2.5, J2.7, J2.9, J2.11, J2.13, J3.2, J7.6 (VSS), J7.11 (SHIELD), J8.6, J8.9, J8.14, J8.20, J8.25, J8.30, J8.34, J8.39, J14.3, Module1.1 (GND), Module1.2 (GND), Module1.7 (GND), Module1.8 (GND), Module1.13 (GND), Module1.14 (GND), Module1.22 (GND), Module1.23 (GND), Module1.32 (GND), Module1.33 (GND), Module1.42 (GND), Module1.43 (GND), Module1.52 (GND), Module1.53 (GND), Module1.59 (GND), Module1.60 (GND), Module1.65 (GND), Module1.66 (GND), Module1.71 (GND), Module1.74 (GND), Module1.98 (GND), SW1.2, U1.3 (GND), U1.8 (GND), U2.3 (GND), U2.8 (GND), U3.19 (SHIELD), U3.20 (SHIELD), U18.2 (GND); also elsewhere on the board
unnamed: C1.1, U3.4 (CT), U3.5 (CT)
unnamed: D1.1 (K), R10.1, TP5.1
unnamed: D2.1 (K), R1.1, TP3.1
unnamed: Module1.21 (LED_nACT), R1.2
unnamed: R3.1, U3.18 (LEDG_K)
unnamed: R2.1, U3.16 (LEDY_K)

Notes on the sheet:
40Way GPIO Header
Activity LED
R2 : Simplify nPWR_LED Drive
FAN connector
R2 : Add R13 to support CM4Lite
Ethernet POE Protection
GPIO Voltage select
R2 : Pullup added for Fans that don't have a strong internal pullup
Not Fitted header
POE Header
Force RPIBOOT = Jumper Pins 1-2
PWR LED
Ethernet
CM5Lite SDCARD I/F


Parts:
C2, C7, C8: 10u; C_0805_2012Metric; Part Description 10uF 10% 10V Ceramic Capacitor X7R 0805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
C3: 100uF; CP_EIA-7343-31_Kemet-D; Part Description Capacitor, SP-Cap, 100u, 6.3V, 15mR ESR
C12, C13: 100n; C_0402_1005Metric; Part Description 0.1uF 10% 16V Ceramic Capacitor X7R 040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
J5, J16: Conn_01x22_Female; Hirose_FH12-22S-0.5SH_1x22-1MP_P0.50mm_Horizontal; Part Description 22 Position FFC, FPC Connector Contacts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
J6: THD-02-R; PinHeader_2x02_P2.54mm_Vertical; Part Description PinHeader_2x02_P2.54mm_Vertical
J10, J22: 690-019-298-412; EDAC 690-019-298-412; Part Description HDMI Connector, Right Angle, 19 Contact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
J12: USB3_A; MTCONN_UBAF30-D2011; Part Description Dual USB 3 connector
Module1: ComputeModule5-CM5; Raspberry-Pi-5-Compute-Module; Part Description 100 Position Connector Receptacle, Cent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
R6, R7, R8: 2.2K 1%; R_0402_1005Metric; Part Description Resistor 2.2K M1005 1% 63mW
R12: 15K 1%; R_0402_1005Metric; Part Description Resistor 15K M1005 1% 63mW
U6: AP22653W6; SOT-23-6; Part Description Power Switch/Driver 1:1 P-Channel 2.1A 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
U12: RT9742SNGV; TSOT-23_HandSoldering; Part Description Power Switch/Driver 1:1 N-Channel 500mA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

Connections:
/+3.3v: J5.22, J16.22, R8.1; also elsewhere on the board
/+5v: C2.1, C12.1, U6.1 (IN), U12.1 (IN); also elsewhere on the board
/CM5_GPIO ( Ethernet, GPIO, SDCARD)/CAM_GPIO0: J5.17; also elsewhere on the board
/CM5_GPIO ( Ethernet, GPIO, SDCARD)/CAM_GPIO1: J5.18; also elsewhere on the board
/CM5_GPIO ( Ethernet, GPIO, SDCARD)/GPIO_VREF: R6.1, R7.1; also elsewhere on the board
/CM5_GPIO ( Ethernet, GPIO, SDCARD)/ID_SC: J6.1; also elsewhere on the board
/CM5_GPIO ( Ethernet, GPIO, SDCARD)/ID_SD: J6.3; also elsewhere on the board
/CM5_GPIO ( Ethernet, GPIO, SDCARD)/USBOTG: Module1.101 (USB_OTG_ID); also elsewhere on the board
/CM5_HighSpeed/DPHY0_C_N: J5.8, Module1.127 (MIPI0_C_N)
/CM5_HighSpeed/DPHY0_C_P: J5.9, Module1.129 (MIPI0_C_P)
/CM5_HighSpeed/DPHY0_D0_N: J5.2, Module1.115 (MIPI0_D0_N)
/CM5_HighSpeed/DPHY0_D0_P: J5.3, Module1.117 (MIPI0_D0_P)
/CM5_HighSpeed/DPHY0_D1_N: J5.5, Module1.121 (MIPI0_D1_N)
/CM5_HighSpeed/DPHY0_D1_P: J5.6, Module1.123 (MIPI0_D1_P)
/CM5_HighSpeed/DPHY0_D2_N: J5.11, Module1.133 (MIPI0_D2_N)
/CM5_HighSpeed/DPHY0_D2_P: J5.12, Module1.135 (MIPI0_D2_P)
/CM5_HighSpeed/DPHY0_D3_N: J5.14, Module1.139 (MIPI0_D3_N)
/CM5_HighSpeed/DPHY0_D3_P: J5.15, Module1.141 (MIPI0_D3_P)
/CM5_HighSpeed/DPHY1_C_N: J16.8, Module1.187 (MIPI1_C_N)
/CM5_HighSpeed/DPHY1_C_P: J16.9, Module1.189 (MIPI1_C_P)
/CM5_HighSpeed/DPHY1_D0_N: J16.2, Module1.175 (MIPI1_D0_N)
/CM5_HighSpeed/DPHY1_D0_P: J16.3, Module1.177 (MIPI1_D0_P)
/CM5_HighSpeed/DPHY1_D1_N: J16.5, Module1.181 (MIPI1_D1_N)
/CM5_HighSpeed/DPHY1_D1_P: J16.6, Module1.183 (MIPI1_D1_P)
/CM5_HighSpeed/DPHY1_D2_N: J16.11, Module1.193 (MIPI1_D2_N)
/CM5_HighSpeed/DPHY1_D2_P: J16.12, Module1.195 (MIPI1_D2_P)
/CM5_HighSpeed/DPHY1_D3_N: J16.14, Module1.194 (MIPI1_D3_N)
/CM5_HighSpeed/DPHY1_D3_P: J16.15, Module1.196 (MIPI1_D3_P)
/CM5_HighSpeed/HDMI0_CEC: J22.13 (CEC), Module1.151 (HDMI0_CEC)
/CM5_HighSpeed/HDMI0_CK_N: J22.12 (CK-), Module1.190 (HDMI0_CLK_N)
/CM5_HighSpeed/HDMI0_CK_P: J22.10 (CK+), Module1.188 (HDMI0_CLK_P)
/CM5_HighSpeed/HDMI0_D0_N: J22.9 (D0-), Module1.184 (HDMI0_TX0_N)
/CM5_HighSpeed/HDMI0_D0_P: J22.7 (D0+), Module1.182 (HDMI0_TX0_P)
/CM5_HighSpeed/HDMI0_D1_N: J22.6 (D1-), Module1.178 (HDMI0_TX1_N)
/CM5_HighSpeed/HDMI0_D1_P: J22.4 (D1+), Module1.176 (HDMI0_TX1_P)
/CM5_HighSpeed/HDMI0_D2_N: J22.3 (D2-), Module1.172 (HDMI0_TX2_N)
/CM5_HighSpeed/HDMI0_D2_P: J22.1 (D2+), Module1.170 (HDMI0_TX2_P)
/CM5_HighSpeed/HDMI0_HOTPLUG: J22.19 (HPD/HEAC-), Module1.153 (HDMI0_HOTPLUG)
/CM5_HighSpeed/HDMI0_SCL: J22.15 (SCL), Module1.200 (HDMI0_SCL)
/CM5_HighSpeed/HDMI0_SDA: J22.16 (SDA), Module1.199 (HDMI0_SDA)
/CM5_HighSpeed/HDMI1_CEC: J10.13 (CEC), Module1.149 (HDMI1_CEC)
/CM5_HighSpeed/HDMI1_CK_N: J10.12 (CK-), Module1.166 (HDMI1_CLK_N)
/CM5_HighSpeed/HDMI1_CK_P: J10.10 (CK+), Module1.164 (HDMI1_CLK_P)
/CM5_HighSpeed/HDMI1_D0_N: J10.9 (D0-), Module1.160 (HDMI1_TX0_N)
/CM5_HighSpeed/HDMI1_D0_P: J10.7 (D0+), Module1.158 (HDMI1_TX0_P)
/CM5_HighSpeed/HDMI1_D1_N: J10.6 (D1-), Module1.154 (HDMI1_TX1_N)
/CM5_HighSpeed/HDMI1_D1_P: J10.4 (D1+), Module1.152 (HDMI1_TX1_P)
/CM5_HighSpeed/HDMI1_D2_N: J10.3 (D2-), Module1.148 (HDMI1_TX2_N)
/CM5_HighSpeed/HDMI1_D2_P: J10.1 (D2+), Module1.146 (HDMI1_TX2_P)
/CM5_HighSpeed/HDMI1_HOTPLUG: J10.19 (HPD/HEAC-), Module1.143 (HDMI1_HOTPLUG)
/CM5_HighSpeed/HDMI1_SCL: J10.15 (SCL), Module1.147 (HDMI1_SCL)
/CM5_HighSpeed/HDMI1_SDA: J10.16 (SDA), Module1.145 (HDMI1_SDA)
/CM5_HighSpeed/HDMI_5v: C13.1, J10.18 (+5V), J22.18 (+5V), U12.2 (OUT)
/CM5_HighSpeed/PCIE_CLK_N: Module1.112 (PCIe_CLK_N); also elsewhere on the board
/CM5_HighSpeed/PCIE_CLK_P: Module1.110 (PCIe_CLK_P); also elsewhere on the board
/CM5_HighSpeed/PCIE_PWR_EN: Module1.106 (PCIE_PWR_EN); also elsewhere on the board
/CM5_HighSpeed/PCIE_RX_N: Module1.118 (PCIe_RX_N); also elsewhere on the board
/CM5_HighSpeed/PCIE_RX_P: Module1.116 (PCIe_RX_P); also elsewhere on the board
/CM5_HighSpeed/PCIE_TX_N: Module1.124 (PCIe_TX_N); also elsewhere on the board
/CM5_HighSpeed/PCIE_TX_P: Module1.122 (PCIe_TX_P); also elsewhere on the board
/CM5_HighSpeed/PCIE_nCLKREQ: Module1.102 (PCIe_nCLKREQ); also elsewhere on the board
/CM5_HighSpeed/PCIE_nRST: Module1.109 (PCIe_nRST); also elsewhere on the board
/CM5_HighSpeed/PCIE_nWAKE: Module1.104 (PCIE_nWAKE); also elsewhere on the board
/CM5_HighSpeed/SCL0: J5.20; also elsewhere on the board
/CM5_HighSpeed/SCL1: J6.2, J16.20, R7.2
/CM5_HighSpeed/SDA0: J5.21; also elsewhere on the board
/CM5_HighSpeed/SDA1: J6.4, J16.21, R6.2
/CM5_HighSpeed/USB3-0-D_N: J12.A2 (D-), Module1.136 (USB3-0-D_N)
/CM5_HighSpeed/USB3-0-D_P: J12.A3 (D+), Module1.134 (USB3-0-D_P)
/CM5_HighSpeed/USB3-0-RX_N: J12.A6 (SSRX+), Module1.128 (USB3-0-RX_N)
/CM5_HighSpeed/USB3-0-RX_P: J12.A5 (SSRX-), Module1.130 (USB3-0-RX_P)
/CM5_HighSpeed/USB3-0-TX_N: J12.A9 (SSTX+), Module1.140 (USB3-0-TX_N)
/CM5_HighSpeed/USB3-0-TX_P: J12.A8 (SSTX-), Module1.142 (USB3-0-TX_P)
/CM5_HighSpeed/USB3-1-D_N: J12.B2 (D-), Module1.165 (USB3-1-D_N)
/CM5_HighSpeed/USB3-1-D_P: J12.B3 (D+), Module1.163 (USB3-1-D_P)
/CM5_HighSpeed/USB3-1-RX_N: J12.B6 (SSRX+), Module1.157 (USB3-1-RX_N)
/CM5_HighSpeed/USB3-1-RX_P: J12.B5 (SSRX-), Module1.159 (USB3-1-RX_P)
/CM5_HighSpeed/USB3-1-TX_N: J12.B9 (SSTX+), Module1.169 (USB3-1-TX_N)
/CM5_HighSpeed/USB3-1-TX_P: J12.B8 (SSTX-), Module1.171 (USB3-1-TX_P)
/CM5_HighSpeed/VBUS: C3.1, C7.1, C8.1, J12.A1 (VBUS), J12.B1 (VBUS), U6.6 (OUT)
/CM5_HighSpeed/VBUS_EN: Module1.111 (VBUS_EN), U6.3 (EN)
/USB2_N: Module1.103 (USB2_N); also elsewhere on the board
/USB2_P: Module1.105 (USB2_P); also elsewhere on the board
GND: C2.2, C3.2, C7.2, C8.2, C12.2, C13.2, J5.1, J5.4, J5.7, J5.10, J5.13, J5.16, J5.19, J10.2 (D2S), J10.5 (D1S), J10.8 (D0S), J10.11 (CKS), J10.17 (GND), J10.SH1 (SH), J10.SH2 (SH), J10.SH3 (SH), J10.SH4 (SH), J12.10 (SHIELD), J12.A4 (GND), J12.A7 (DRAIN), J12.B4 (GND), J12.B7 (DRAIN), J16.1, J16.4, J16.7, J16.10, J16.13, J16.16, J16.19, J22.2 (D2S), J22.5 (D1S), J22.8 (D0S), J22.11 (CKS), J22.17 (GND), J22.SH1 (SH), J22.SH2 (SH), J22.SH3 (SH), J22.SH4 (SH), Module1.107 (GND), Module1.108 (GND), Module1.113 (GND), Module1.114 (GND), Module1.119 (GND), Module1.120 (GND), Module1.125 (GND), Module1.126 (GND), Module1.131 (GND), Module1.132 (GND), Module1.137 (GND), Module1.138 (GND), Module1.144 (GND), Module1.150 (GND), Module1.155 (GND), Module1.156 (GND), Module1.161 (GND), Module1.162 (GND), Module1.167 (GND), Module1.168 (GND), Module1.173 (GND), Module1.174 (GND), Module1.179 (GND), Module1.180 (GND), Module1.185 (GND), Module1.186 (GND), Module1.191 (GND), Module1.192 (GND), Module1.197 (GND), Module1.198 (GND), R12.2, U6.2 (GND), U12.3 (GND); also elsewhere on the board
unnamed: J16.17, R8.2
unnamed: R12.1, U6.5 (ILIM)

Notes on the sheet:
USB 3 Pairs P/N swapped to help routing
Jumpers to be fitted if DPHY1 is used
Current Limit switch
DSI/CSI Connectors
Stacked USB connectors


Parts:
C4, C6, C14, C15, C16, C17: 10u; C_0805_2012Metric; Part Description 10uF 10% 10V Ceramic Capacitor X7R 0805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
C10, C19: 100n; C_0402_1005Metric; Part Description 0.1uF 10% 16V Ceramic Capacitor X7R 040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
C11: 4.7nF; C_0402_1005Metric; Part Description 4.7nF capacitor 0402
D3: LED Green; LED_0603_1608Metric; Part Description Green 572nm LED Indication - Discrete 2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
J4: Bus_M.2_Socket_M; M.2 M Key socket; Part Description M.2 M Key connector
L1: 2.2uH; L_Bourns_SRP5030CC; Part Description Inductor, SMT, 2520, 2u2, IRMS=7A, ISAT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
M1: M.2 Screw; Part Description M.2 Screw
M2, M3, M4, M5: M.2 Solder Nut; Part Description Solder nut for M.2 slot
R14: 100K 1%; R_0402_1005Metric; Part Description Resistor 100K M1005 1% 63mW
R15: 10K 1%; R_0402_1005Metric; Part Description Resistor 10K M1005 1% 63mW
R16: 2.2K 1%; R_0402_1005Metric; Part Description Resistor 2.2K M1005 1% 63mW
R17: 1k; R_0402_1005Metric; Part Description Resistor 1K M1005 1% 63mW
TP1: TestPoint; TestPoint_Pad_2.0x2.0mm; Part Description Test point; not fitted
U7: ASEK-32.768KHZ-L-R-T; Crystal_SMD_3225-4Pin_3.2x2.5mm; Part Description 32KHz Xtal oscilator
U8: AP3441SHE-7B; DFN-8-1EP_2x2mm_P0.5mm_EP1.05x1.75mm; Part Description 3A DC-DC converter

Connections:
/+5v: C4.1, C6.1, C10.1, U8.3 (VIN); also elsewhere on the board
/CM5_HighSpeed/PCIE_CLK_N: J4.53 (REFCLKn); also elsewhere on the board
/CM5_HighSpeed/PCIE_CLK_P: J4.55 (REFCLKp); also elsewhere on the board
/CM5_HighSpeed/PCIE_PWR_EN: R14.1, U8.7 (EN); also elsewhere on the board
/CM5_HighSpeed/PCIE_RX_N: J4.43 (PETp0); also elsewhere on the board
/CM5_HighSpeed/PCIE_RX_P: J4.41 (PETn0); also elsewhere on the board
/CM5_HighSpeed/PCIE_TX_N: J4.49 (PERp0); also elsewhere on the board
/CM5_HighSpeed/PCIE_TX_P: J4.47 (PERn0); also elsewhere on the board
/CM5_HighSpeed/PCIE_nCLKREQ: J4.52 (~CLKREQ); also elsewhere on the board
/CM5_HighSpeed/PCIE_nRST: J4.50 (~PERST); also elsewhere on the board
/CM5_HighSpeed/PCIE_nWAKE: J4.54 (~PEWAKE); also elsewhere on the board
/PCIe-M2/FB: C11.2, R15.2, R16.1, U8.1 (FB)
/PCIe-M2/M2_3v3: C11.1, C14.1, C15.1, C16.1, C17.1, C19.1, D3.2 (A), J4.2 (3.3V), J4.4 (3.3V), J4.12 (3.3V), J4.14 (3.3V), J4.16 (3.3V), J4.18 (3.3V), J4.70 (3.3V), J4.72 (3.3V), J4.74 (3.3V), L1.2, R15.1, U7.1 (EN), U7.4 (VDD)
GND: C4.2, C6.2, C10.2, C14.2, C15.2, C16.2, C17.2, C19.2, J4.1 (GND), J4.3 (GND), J4.9 (GND), J4.15 (GND), J4.21 (GND), J4.27 (GND), J4.33 (GND), J4.39 (GND), J4.45 (GND), J4.51 (GND), J4.57 (GND), J4.71 (GND), J4.73 (GND), J4.75 (GND), J4.M1 (GND2230), J4.M2 (GND2242), J4.M3 (GND2260), J4.M4 (GND2280), J4.S1, J4.S2, R14.2, R16.2, U7.2 (GND), U8.4 (PGND), U8.8 (SGND), U8.9 (PAD); also elsewhere on the board
unnamed: D3.1 (K), R17.1, TP1.1
unnamed: J4.10 (DAS/~DSS/~LED1), R17.2
unnamed: J4.68 (SUSCLK), U7.3 (Out)
unnamed: L1.1, U8.6 (LX)

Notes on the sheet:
Activity LED

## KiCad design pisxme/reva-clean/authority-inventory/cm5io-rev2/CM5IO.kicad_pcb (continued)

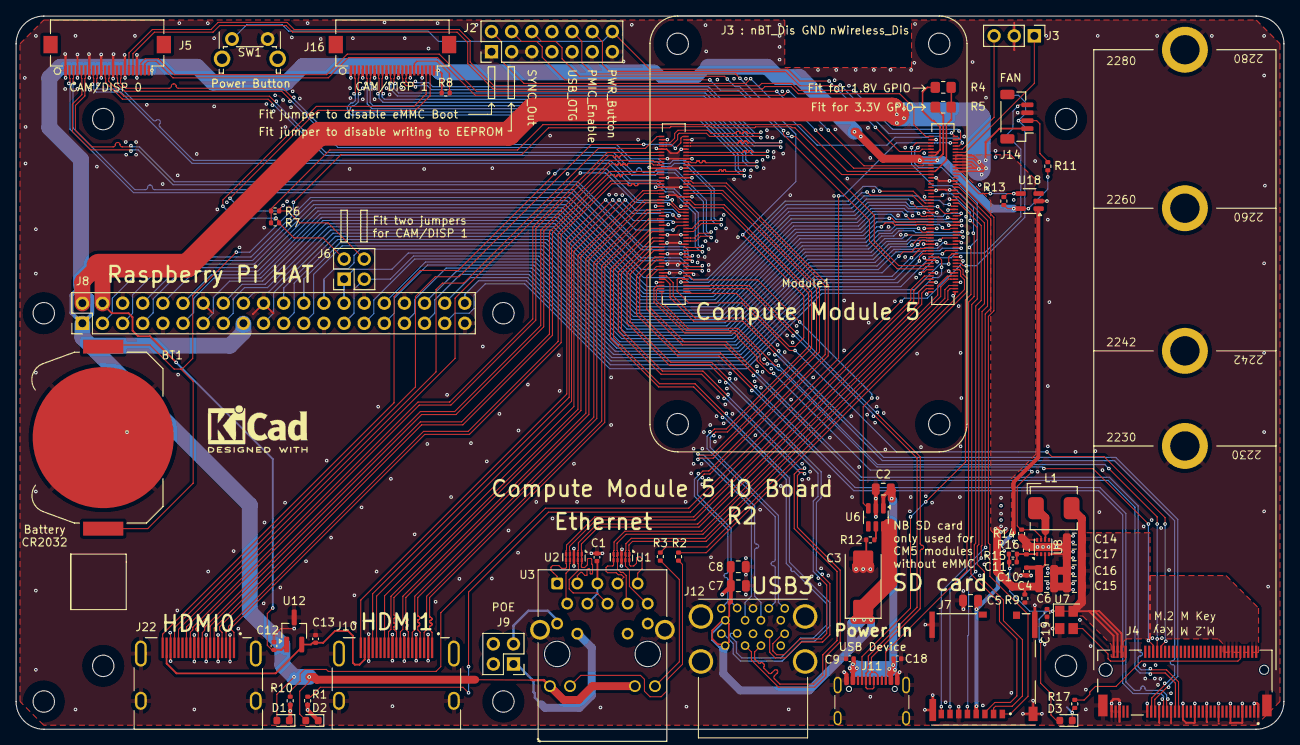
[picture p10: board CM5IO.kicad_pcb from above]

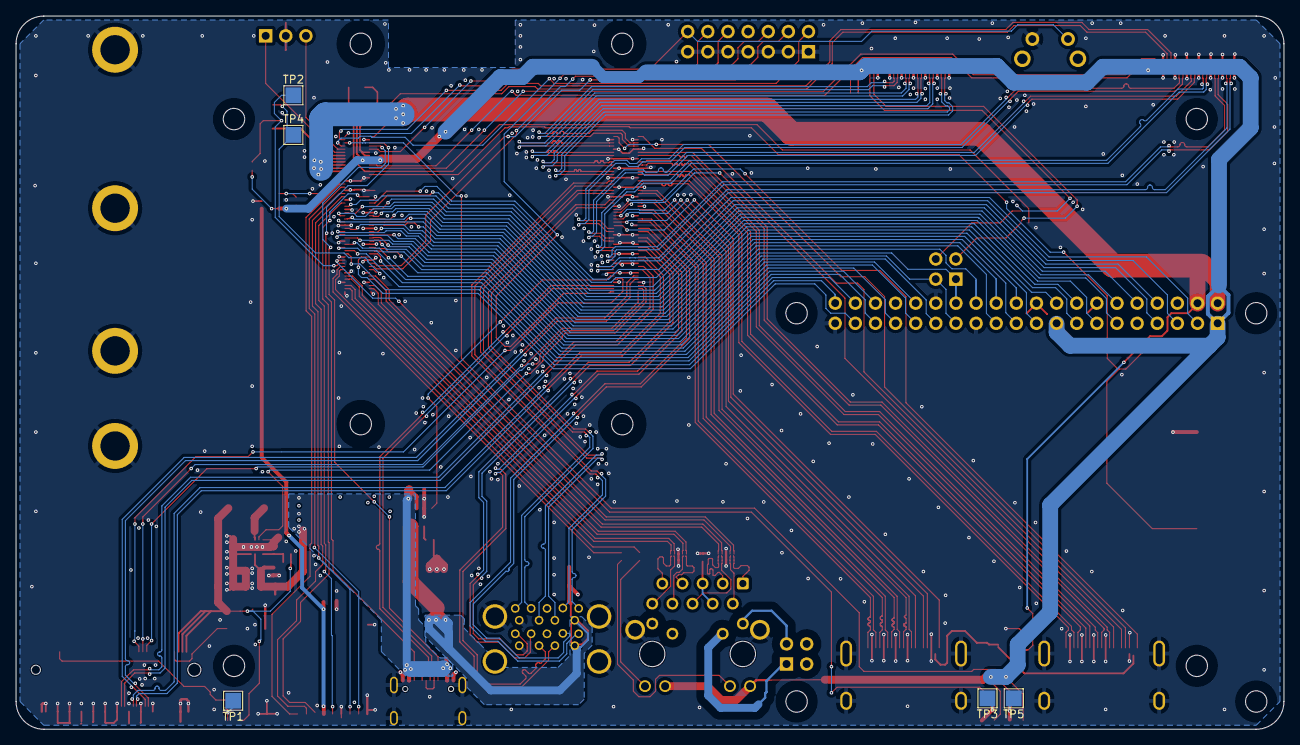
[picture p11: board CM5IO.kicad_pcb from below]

Board: 4 copper layers, 160.0 x 90.0 mm, 78 parts (5 on the bottom side), 160 nets.

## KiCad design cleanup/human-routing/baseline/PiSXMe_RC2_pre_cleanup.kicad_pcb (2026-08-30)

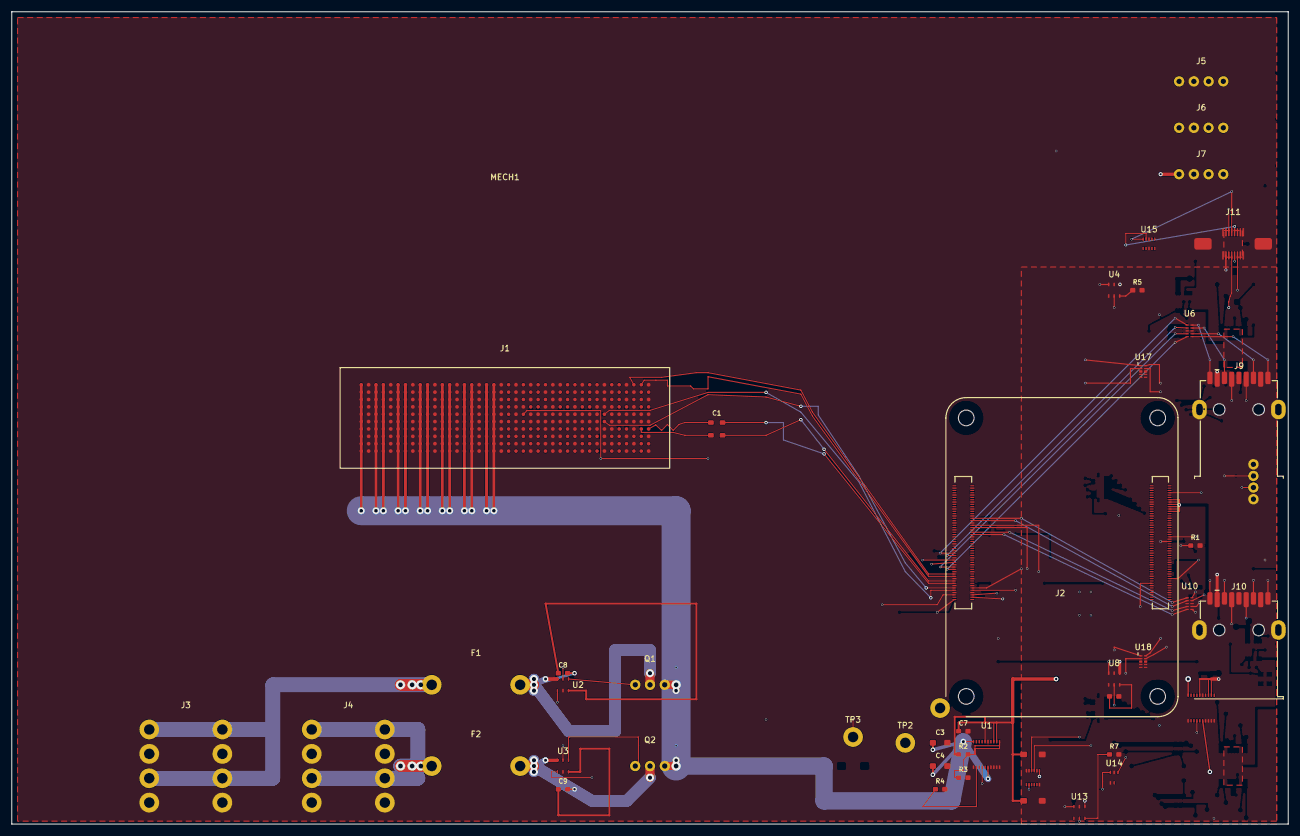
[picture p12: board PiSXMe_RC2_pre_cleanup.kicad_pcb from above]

Board: 6 copper layers, 220.0 x 140.0 mm, 49 parts (0 on the bottom side), 56 nets.

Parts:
C1, C2: GRM21BR71H224KA01# 220nF; ROUT_0805
C3, C4: 10uF 50V buck input; ROUT_1206
C5, C6: 22uF 25V buck output; ROUT_1210
C7: 100nF VLDOIN; ROUT_0603
C8: 100nF LM74700 VCAP A; ROUT_0603
C9: 100nF LM74700 VCAP B; ROUT_0603
F1, F2: Littelfuse 178.6165.0001 / 0297015.U 15A holder; ATO_FuseHolder
J1: 74221-101LF; SXM2_74221-101LF
J2: 2x 10164227-1004A1RLF; CM5_1004
J3, J4: Molex 39301082 / Mini-Fit Jr 8-circuit; MiniFitJr_8_RA
J5: Molex 22-23-2041 / PC PWM fan 1; Fan_2x2_2.54mm
J6: Molex 22-23-2041 / PC PWM fan 2; Fan_2x2_2.54mm
J7: Molex 22-23-2041 / pump or auxiliary fan; Fan_2x2_2.54mm
J8: JST B4B-PH-K-S / CM5 UART; JST_PH_4
J9, J10: USB3_A_Receptacle_Wuerth_692122030100; USB3_A_Wuerth_692122030100
J11: Amphenol 10171746-00021LF USB-C USB2 SERVICE; USB_C_SERVICE_10171746
MECH1: V100/SXM2 module envelope only; V100_MODULE_ENVELOPE
Q1, Q2: CSD19536KCS 100V 2.7mΩ N-MOSFET; CSD19536KCS_TO220
R1: 0R CLKREQ link DNP/POP; ROUT_0603
R2: 40.2k buck feedback; ROUT_0603
R3: 10.0k buck feedback; ROUT_0603
R4: 13.0k buck RT; ROUT_0603
R5: 16.9k 1% TPS2553 ILIM FAST A; ROUT_0603
R6: 16.9k 1% TPS2553 ILIM FAST B; ROUT_0603
R7: 52.3k TPS2553 ILIM; ROUT_0603
TP1: PERST# test point; TestPoint
TP2: REFCLK access marker (no probe stub); TestPoint
TP3: CM5 nRPIBOOT / internal recovery test point; TestPoint
U1: TPSM63606RDLR 12V-to-5V 6A module; TPSM63606
U2, U3: LM74700QDBVRQ1 reverse-polarity controller; LM74700_DBV
U4: TPS2553DBVR FAST A USB3 Type-A VBUS current limit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; TPS2553_DBV
U6: TPD4EUSB30 SuperSpeed ESD FAST A 1; TPD4E05U06_DQA_TI_FLOWTHROUGH
U8: TPS2553DBVR FAST B USB3 Type-A VBUS current limit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; TPS2553_DBV
U10: TPD4EUSB30 SuperSpeed ESD FAST B 1; TPD4E05U06_DQA_TI_FLOWTHROUGH
U12: TUSB320LAIRWBR USB-C DRP controller SERVICE; TUSB320LAI_RWB
U13: TPS2553DBVR USB2 SERVICE current limiter; TPS2553_DBV
U14: SN74LVC1G04DCKR SERVICE VBUS role inverter; SN74LVC1G04_DCK
U15: TPD2EUSB30A USB2 ESD SERVICE; TPD2EUSB30A_DQA
U16: TPSM63606RDLR dedicated USB 5V peripheral rail; TPSM63606_USB
U17, U18: TPD2EUSB30A USB2 companion ESD; TPD2EUSB30A_DQA_TI_FLOWTHROUGH

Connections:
/3V3: J2.84, J2.86, J8.4, U12.5, U12.12, U14.4
/CM5_5V: C5.1, C6.1, C7.1, J2.77, J2.79, J2.81, J2.83, J2.85, J2.87, R2.1, U1.5, U1.8, U1.9
/CM5_5V_FB: R2.2, R3.1, U1.10
/CM5_CLKREQ_N: J2.102, R1.1
/CM5_USB3_0_RX_N: J2.128, J9.5, U6.5, U6.6
/CM5_USB3_0_RX_P: J2.130, J9.6, U6.4, U6.7
/CM5_USB3_0_TX_N: J2.140, J9.8, U6.2, U6.9
/CM5_USB3_0_TX_P: J2.142, J9.9, U6.1, U6.10
/CM5_USB3_1_RX_N: J2.157, J10.5, U10.5, U10.6
/CM5_USB3_1_RX_P: J2.159, J10.6, U10.4, U10.7
/CM5_USB3_1_TX_N: J2.169, J10.8, U10.2, U10.9
/CM5_USB3_1_TX_P: J2.171, J10.9, U10.1, U10.10
/CM5_VBUS_EN: J2.111, U4.5, U8.5
/CM5_nRPIBOOT: J2.93, TP3.1
/FAN_PWM: J2.19, J5.4, J6.4, J7.4
/FAN_TACH: J2.16, J5.3, J6.3, J7.3
/FUSED_A_12V: C8.2, F1.2, Q1.2, U2.1
/FUSED_B_12V: C9.2, F2.2, Q2.2, U3.1
/GATE_A: Q1.1, U2.3
/GATE_B: Q2.1, U3.3
/GND: C3.2, C4.2, C5.2, C6.2, C7.2, J1.A1, J1.A4, J1.A7, J1.A10, J1.A13, J1.A14, J1.A17, J1.A19, J1.A21, J1.A24, J1.A27, J1.A30, J1.A33, J1.A36, J1.A39, J1.B3, J1.B6, J1.B7, J1.B8, J1.B11, J1.B14, J1.B15, J1.B18, J1.B19, J1.B21, J1.B24, J1.B27, J1.B30, J1.B33, J1.B36, J1.B39, J1.C1, J1.C4, J1.C7, J1.C10, J1.C13, J1.C14, J1.C17, J1.C19, J1.C21, J1.C24, J1.C27, J1.C30, J1.C33, J1.C36, J1.C39, J1.D3, J1.D6, J1.D7, J1.D8, J1.D11, J1.D14, J1.D15, J1.D18, J1.D19, J1.D21, J1.D24, J1.D27, J1.D30, J1.D33, J1.D36, J1.D39, J1.E1, J1.E2, J1.E3, J1.E4, J1.E5, J1.E6, J1.E8, J1.E9, J1.E10, J1.E11, J1.E12, J1.E13, J1.E14, J1.E15, J1.E16, J1.E17, J1.E19, J1.E21, J1.E24, J1.E27, J1.E30, J1.E33, J1.E36, J1.E39, J1.F1, J1.F2, J1.F3, J1.F4, J1.F5, J1.F6, J1.F8, J1.F9, J1.F10, J1.F11, J1.F12, J1.F13, J1.F14, J1.F15, J1.F16, J1.F17, J1.F19, J1.F21, J1.F24, J1.F27, J1.F30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
/PCIE_PWR_EN: J2.106, U1.14, U2.4, U3.4, U16.14
/PER0_N: J1.A3, J2.124
/PER0_P: J1.A2, J2.122
/PERST_N: J1.E18, J2.109
/PET0_N: C2.2, J2.118
/PET0_N_RAW: C2.1, J1.G2
/PET0_P: C1.2, J2.116
/PET0_P_RAW: C1.1, J1.G1
/RAW_A_12V: F1.1, J3.1, J3.3, J3.5, J3.7
/RAW_B_12V: F2.1, J4.1, J4.3, J4.5, J4.7
/REFCLK_N: J1.F7, J2.112
/REFCLK_P: J1.E7, J2.110
/RT_1MHZ: R4.1, U1.12
/SERVICE_ID_STATUS: U12.8, U14.1
/SERVICE_ILIM: R7.1, U13.6
/SERVICE_VBUS: J11.A4, J11.A9, J11.B4, J11.B9, U12.6, U13.3
/SERVICE_VBUS_EN: U13.5, U14.3
/UART_RX: J2.51, J8.3
/UART_TX: J2.55, J8.2
/USB_5V_PERIPH: U4.1, U8.1, U13.1, U16.5, U16.8, U16.9
/USB_FAST_A_DM: J2.136, J9.2, U17.2, U17.9
/USB_FAST_A_DP: J2.134, J9.3, U17.1, U17.10
/USB_FAST_A_ILIM: R5.1, U4.6
/USB_FAST_A_VBUS: J9.1, U4.3
/USB_FAST_B_DM: J2.165, J10.2, U18.2, U18.9
/USB_FAST_B_DP: J2.163, J10.3, U18.1, U18.10
/USB_FAST_B_ILIM: R6.1, U8.6
/USB_FAST_B_VBUS: J10.1, U8.3
/USB_SERVICE_CC1: J11.A5, U12.3
/USB_SERVICE_CC2: J11.B5, U12.4
/USB_SERVICE_DM: J2.103, J11.A7, J11.B7, U15.2
/USB_SERVICE_DP: J2.105, J11.A6, J11.B6, U15.1
/VCAP_A: C8.1, U2.6
/VCAP_B: C9.1, U3.6
/VPROT_12V: C3.1, C4.1, J1.A22, J1.A23, J1.A25, J1.A26, J1.A28, J1.A29, J1.A31, J1.A32, J1.A34, J1.A35, J1.A37, J1.A38, J1.A40, J1.B22, J1.B23, J1.B25, J1.B26, J1.B28, J1.B29, J1.B31, J1.B32, J1.B34, J1.B35, J1.B37, J1.B38, J1.B40, J1.C22, J1.C23, J1.C25, J1.C26, J1.C28, J1.C29, J1.C31, J1.C32, J1.C34, J1.C35, J1.C37, J1.C38, J1.C40, J1.D22, J1.D23, J1.D25, J1.D26, J1.D28, J1.D29, J1.D31, J1.D32, J1.D34, J1.D35, J1.D37, J1.D38, J1.D40, J1.E22, J1.E23, J1.E25, J1.E26, J1.E28, J1.E29, J1.E31, J1.E32, J1.E34, J1.E35, J1.E37, J1.E38, J1.E40, J1.F22, J1.F23, J1.F25, J1.F26, J1.F28, J1.F29, J1.F31, J1.F32, J1.F34, J1.F35, J1.F37, J1.F38, J1.F40, J1.G22, J1.G23, J1.G25, J1.G26, J1.G28, J1.G29, J1.G31, J1.G32, J1.G34, J1.G35, J1.G37, J1.G38, J1.G40, J1.H22, J1.H23, J1.H25, J1.H26, J1.H28, J1.H29, J1.H31, J1.H32, J1.H34, J1.H35, J1.H37, J1.H38, J1.H40, J1.J22, J1.J23, J1.J25, J1.J26, J1.J28, J1.J29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

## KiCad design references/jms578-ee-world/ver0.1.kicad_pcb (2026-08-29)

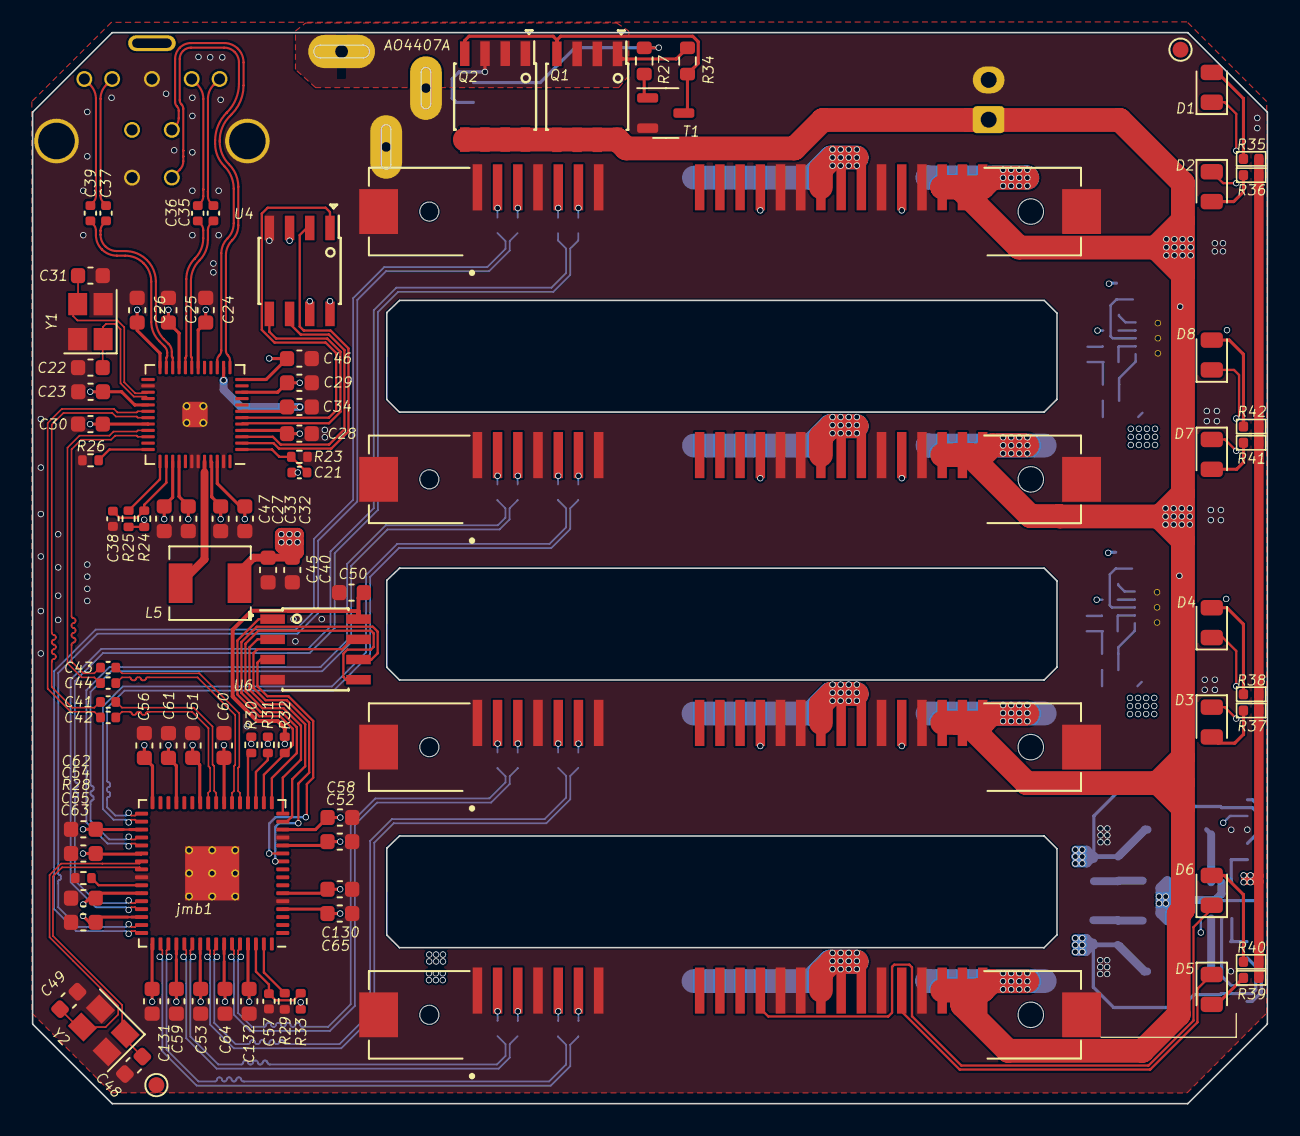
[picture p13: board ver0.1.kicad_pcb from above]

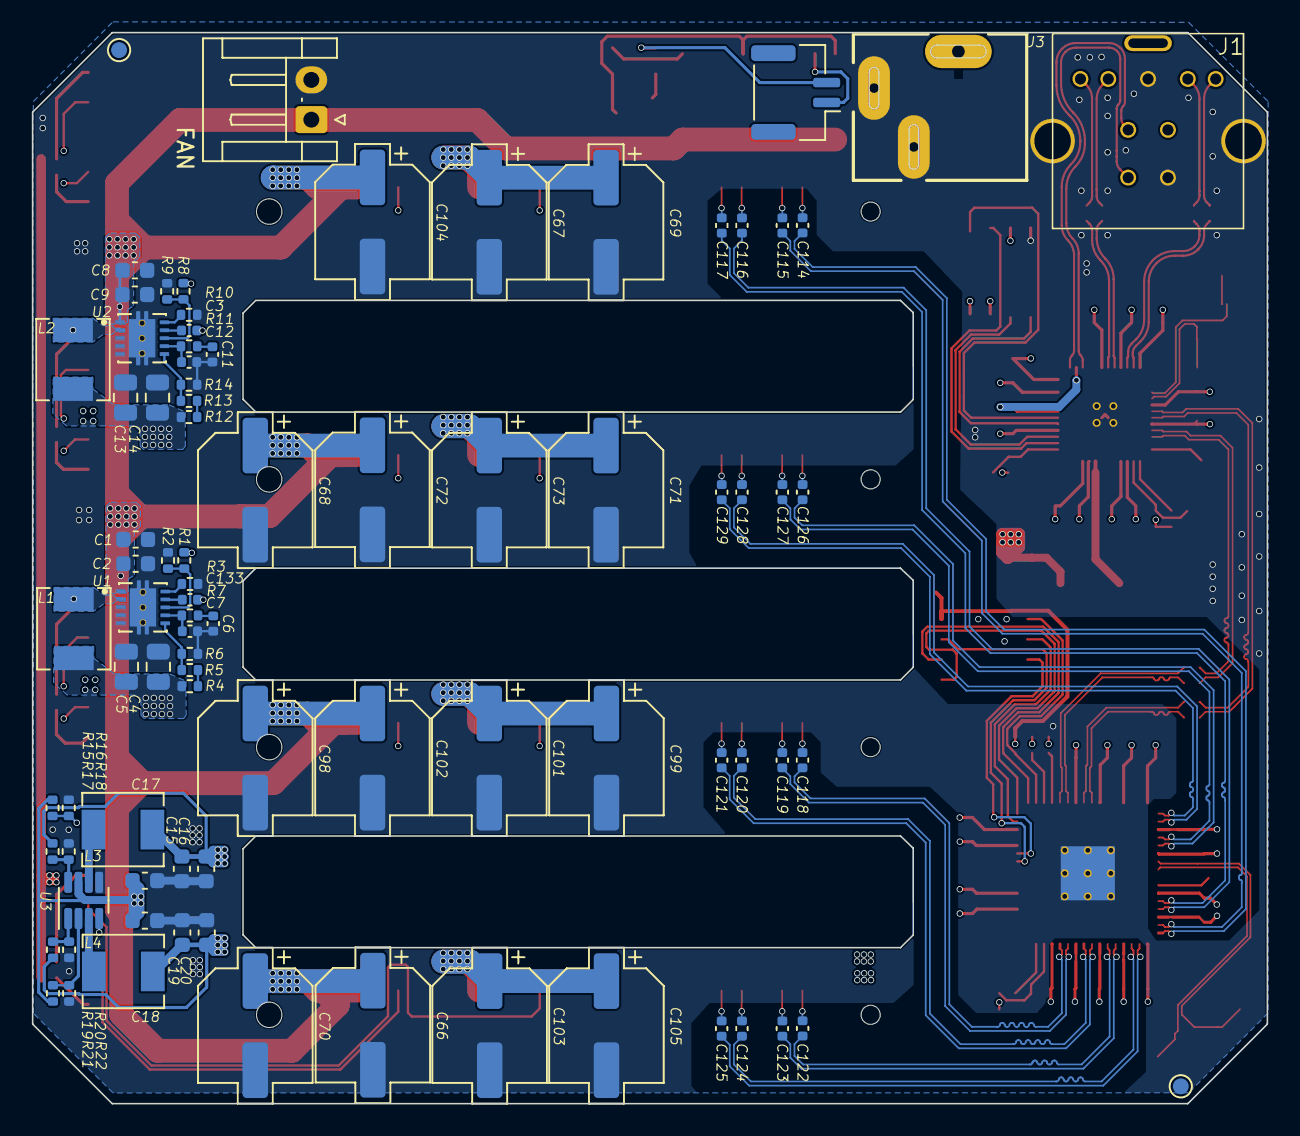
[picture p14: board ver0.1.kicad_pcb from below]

Board: 4 copper layers, 77.6 x 67.3 mm, 178 parts (86 on the bottom side), 124 nets.

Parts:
C1, C8, C15, C16, C19, C20, C40: 10uF; C_0603_1608Metric
C2, C9, C45: 0.1uF; C_0603_1608Metric
C3, C133: 0.1uF; C_0402_1005Metric
C4, C5, C13, C14: 47uF; C_0805_2012Metric
C6, C11: 0.012uF; C_0402_1005Metric
C7, C12: 120pF; C_0402_1005Metric
C17, C18: 22uF; C_0603_1608Metric
C21, C38, C57: 1uF; C_0402_1005Metric
C22, C31: 33pF; C_0603_1608Metric
C23, C24, C25, C26, C27, C28, C29, C30, C32, C33, C34, C46, C47, C50, C51, C52, C53, C54, C55, C56, C58, C59, C60, C61, C62, C63, C64, C65, C130, C131, C132: 100nF; C_0603_1608Metric
C35, C36: 100nF; C_0402_1005Metric
C37, C39: 0R; C_0402_1005Metric
C41, C42, C43, C44, C114, C115, C116, C117, C118, C119, C120, C121, C122, C123, C124, C125, C126, C127, C128, C129: 10nF; C_0402_1005Metric
C48, C49: 25pF; C_0603_1608Metric
C66, C67, C68, C69, C70, C71, C72, C73: 270uF; CP_Elec_6.3x5.4
C98, C99, C101, C102, C103, C104, C105: 22uF; CP_Elec_6.3x5.3
D1, D2, D3, D4, D5, D6, D7, D8: LED; LED_0805_2012Metric
FAN: fan2; JST_EH_S2B-EH_1x02_P2.50mm_Horizontal
FID1, FID2, FID3, FID4: Fiducial; TestPoint_Pad_D1.0mm
J1: USB 3.1 B; USB B 母座 直立
J2: SWITCH; JST_GH_BM02B-GHS-TBT_1x02-1MP_P1.25mm_Vertical
J3: dc 5.5mm; DC socket 5.5mm
J4, J5, J6, J7: SATA硬盘插头; SATA 29pin smd
L1, L2: 15uH; L_Chilisin_BMRA00040420
L3: 1uH; L_Chilisin_BMRA00040420
L4: 2uH; L_Chilisin_BMRA00040420
L5: 4.7uH; L_Chilisin_BMRA00040420
Q1, Q2: AO4407A; SOIC-8_3.9x4.9mm_Pitch1.27mm
R1, R8: 220k; R_0402_1005Metric
R2, R9: 43.2K; R_0402_1005Metric
R3, R10: 143K; R_0402_1005Metric
R4, R12: 51.1R; R_0402_1005Metric
R5, R13, R15, R21: 100k; R_0402_1005Metric
R6, R14: 19.1K; R_0402_1005Metric
R7, R11: 3.74K; R_0402_1005Metric
R16, R22: 43k; R_0402_1005Metric
R17, R19: 600K; R_0402_1005Metric
R18: 712K; R_0402_1005Metric
R20: 140K; R_0402_1005Metric
R23: 100K; R_0402_1005Metric
R24: 330K; R_0402_1005Metric
R25, R29, R30, R31, R32: 4.7K; R_0402_1005Metric
R26: 12K; R_0402_1005Metric
R27: 200Re; R_0603_1608Metric
R28: 12k; R_0402_1005Metric
R33: 10k; R_0402_1005Metric
R34: 4k; R_0603_1608Metric
R35, R36, R37, R38, R39, R40, R41, R42: 2k; R_0402
T1: T-BJT-NPN; SOT-23-3
U1, U2: TPS54335A; TPS54335ADRCR
U3: SOT-23-8
U4, U6: SOIC-8_3.9x4.9mm_Pitch1.27mm
U5: QFN-48-1EP_6x6mm_P0.4mm_EP4.2x4.2mm_ThermalVias
Y1, Y2: Crystal_GND24_Small; Crystal_SMD_Abracon_ABM8AIG-4Pin_3.2x2.5mm
jmb1: QFN-64-1EP_9x9mm_P0.5mm_EP3.4x3.4mm_ThermalVias

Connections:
+1V2: C15.2, C16.2, C58.2, C59.2, C60.2, C61.2, C62.2, C63.2, C64.2, C65.2, L3.1, R17.2, jmb1.4 (DV1.2), jmb1.14 (DV1.2), jmb1.23 (AV1.2), jmb1.29 (AV1.2), jmb1.35 (AV1.2), jmb1.46 (AV1.2), jmb1.52 (AV1.2), jmb1.58 (AV1.2)
+3V3: C19.2, C20.2, C50.2, C51.2, C52.2, C53.2, C54.2, C55.2, C56.2, C130.2, C131.2, C132.2, L4.2, R19.2, R30.2, R31.2, R32.2, R33.2, R35.1, R36.1, R37.1, R38.1, R39.1, R40.1, R41.1, R42.1, U6.8 (VCC), jmb1.6 (DV3.3), jmb1.12 (DV3.3), jmb1.26 (AV3.3), jmb1.32 (AV3.3), jmb1.38 (AV3.3), jmb1.43 (AV3.3), jmb1.49 (AV3.3), jmb1.55 (AV3.3), jmb1.61 (AV3.3)
+5V: C4.1, C5.1, C13.1, C14.1, C17.2, C18.2, C67.1, C69.1, C71.1, C73.1, C99.1, C101.1, C103.1, C105.1, J4.P7, J4.P8, J4.P9, J5.P7, J5.P8, J5.P9, J6.P7, J6.P8, J6.P9, J7.P7, J7.P8, J7.P9, L1.2, L2.2, R4.1, R12.1, R15.2, R21.2, U3.7 (IN)
/AGPIO0: U6.6 (SCLK), jmb1.17 (ZGPIO0)
/AGPIO1: U6.5 (SI), jmb1.16 (ZGPIO1)
/AGPIO2: U6.2 (SO), jmb1.15 (ZGPIO2)
/AGPIO3: U6.3 (WP#), jmb1.11 (ZGPIO3)
/AGPIO4: U6.7 (HOLD#), jmb1.10 (ZGPIO4)
/AGPIO12: R29.1, jmb1.63 (ZGPIO12)
/AGPIO13: R31.1, jmb1.19 (ZGPIO13)
/AGPIO14: R32.1, U6.1 (CS#), jmb1.18 (ZGPIO14)
/ARESETn: C57.1, R33.1, jmb1.62 (XRSTN)
/AREXT: R28.1, jmb1.42 (AREXT)
/ARXN0: C116.2, jmb1.45 (ARXN0)
/ARXN1: C120.2, jmb1.57 (ARXN1)
/ARXN2: C124.2, jmb1.51 (ARXN2)
/ARXN3: C128.2, jmb1.34 (ARXN3)
/ARXP0: C117.2, jmb1.44 (ARXP0)
/ARXP1: C121.2, jmb1.56 (ARXP1)
/ARXP2: C125.2, jmb1.50 (ARXP2)
/ARXP3: C129.2, jmb1.33 (ARXP3)
/ATESTn: R30.1, jmb1.20 (XTSTN)
/ATXN0: C115.2, jmb1.47 (ATXN0)
/ATXN1: C119.2, jmb1.59 (ATXN1)
/ATXN2: C123.2, jmb1.53 (ATXN2)
/ATXN3: C127.2, jmb1.36 (ATXN3)
/ATXP0: C114.2, jmb1.48 (ATXP0)
/ATXP1: C118.2, jmb1.60 (ATXP1)
/ATXP2: C122.2, jmb1.54 (ATXP2)
/ATXP3: C126.2, jmb1.37 (ATXP3)
/AXIN: C49.1, Y2.3, jmb1.39 (AXIN)
/AXOUT: C48.2, Y2.1, jmb1.40 (AXOUT)
/DAS1: D2.1 (K), J4.P11
/DAS2: D3.1 (K), J5.P11
/DAS3: D5.1 (K), J6.P11
/DAS4: D7.1 (K), J7.P11
/GPIO0: U4.2 (SO), U5.2 (GPIO0)
/GPIO1: U4.6 (SCLK), U5.3 (GPIO1)
/GPIO2: U4.5 (SI), U5.5 (GPIO2)
/GPIO3: U4.1 (CS#), U5.6 (GPIO3)
/HOT1: D1.1 (K), J4.P4
/HOT2: D4.1 (K), J5.P4
/HOT3: D6.1 (K), J6.P4
/HOT4: D8.1 (K), J7.P4
/HSD0+: J1.3 (D+), U5.15 (DP)
/HSD0-: J1.2 (D-), U5.13 (DM)
/LXO: L5.1, U5.44 (LXO)
/RST: C38.1, R24.2, U5.38 (RST#)
/RX_N: C41.1, U5.31 (RXN)
/RX_P: C42.1, U5.30 (RXP)
/SSRX0+: C39.1, J1.9 (STDB_SSRX+)
/SSRX0-: C37.1, J1.8 (STDB_SSRX-)
/SSTX0+: C35.1, J1.5 (STDB_SSTX-)
/SSTX0-: C36.1, J1.6 (STDB_SSTX+)
/TX_N: C44.1, U5.33 (TXN)
/TX_P: C43.1, U5.34 (TXP)
/XIN: C22.2, U5.28 (XIN), Y1.1
/XOUT: C31.1, U5.27 (XOUT), Y1.3
/cap-SSRX1+: C39.2, U5.23 (SSRXP)
/cap-SSRX1-: C37.2, U5.22 (SSRXN)
/cap-SSTX1+: C36.2, U5.20 (SSTXP)
/cap-SSTX1-: C35.2, U5.19 (SSTXN)
/net-RX_N: C41.2, jmb1.24 (ATXN5)
/net-RX_P: C42.2, jmb1.25 (ATXP5)
/net-TX_N: C44.2, jmb1.22 (ARXN5)
/net-TX_P: C43.2, jmb1.21 (ARXP5)
/vout1.2: C23.2, C24.2, C25.2, C26.2, C27.2, C28.2, C29.2, C30.2, C40.2, C45.2, L5.2, U5.4 (VCCK), U5.10 (VCCK), U5.18 (AVDDL), U5.21 (AVDDL), U5.24 (AVDDL), U5.29 (AVDDL), U5.32 (AVDDL), U5.40 (VCCK)
/vout3.3: C21.1, C32.2, C33.2, C34.2, R24.1, R25.2, U4.3 (WP#), U4.7 (HOLD#), U4.8 (VCC), U5.7 (VCCO), U5.14 (AV33O), U5.39 (VCCO), U5.46 (MODE0)
GND: C1.1, C2.1, C4.2, C5.2, C6.2, C7.2, C8.1, C9.1, C11.2, C12.2, C13.2, C14.2, C15.1, C16.1, C17.1, C18.1, C19.1, C20.1, C22.1, C23.1, C24.1, C25.1, C26.1, C27.1, C28.1, C29.1, C30.1, C31.2, C32.1, C33.1, C34.1, C38.2, C40.1, C45.1, C46.1, C47.1, C48.1, C49.2, C50.1, C51.1, C52.1, C53.1, C54.1, C55.1, C56.1, C57.2, C58.1, C59.1, C60.1, C61.1, C62.1, C63.1, C64.1, C65.1, C66.2, C67.2, C68.2, C69.2, C70.2, C71.2, C72.2, C73.2, C98.2, C99.2, C101.2, C102.2, C103.2, C104.2, C105.2, C130.1, C131.1, C132.1, FAN.2, J1.4 (GND), J1.7 (GND_DRAIN), J1.S1, J1.S2, J3.2, J3.3, J4.P5, J4.P6, J4.P10, J4.P12, J4.S1, J4.S4, J4.S7, J4.SH1 (SHIELD), J4.SH2 (SHIELD), J5.P5, J5.P6, J5.P10, J5.P12, J5.S1, J5.S4, J5.S7, J5.SH1 (SHIELD), J5.SH2 (SHIELD), J6.P5, J6.P6, J6.P10, J6.P12, J6.S1, J6.S4, J6.S7, J6.SH1 (SHIELD), J6.SH2 (SHIELD), J7.P5, J7.P6, J7.P10, J7.P12, J7.S1, J7.S4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
unnamed: C6.1, R7.2
unnamed: C11.1, R11.2
unnamed: C114.1, J4.S2
unnamed: C115.1, J4.S3
unnamed: C116.1, J4.S5
unnamed: C117.1, J4.S6
unnamed: C118.1, J5.S2
unnamed: C119.1, J5.S3
unnamed: C120.1, J5.S5
unnamed: C121.1, J5.S6
unnamed: C122.1, J6.S2
unnamed: C123.1, J6.S3
unnamed: C124.1, J6.S5
unnamed: C125.1, J6.S6
unnamed: C126.1, J7.S2
unnamed: C127.1, J7.S3
unnamed: C128.1, J7.S5
unnamed: C129.1, J7.S6
unnamed: D1.2 (A), R35.2
unnamed: D2.2 (A), R36.2
unnamed: D3.2 (A), R37.2
unnamed: D4.2 (A), R38.2
unnamed: D5.2 (A), R39.2
unnamed: D6.2 (A), R40.2
unnamed: D7.2 (A), R41.2
unnamed: D8.2 (A), R42.2
unnamed: J2.2, R27.1
unnamed: Q1.4 (G), Q2.4 (G), R34.2, T1.3 (E)
unnamed: R4.2, R5.1
unnamed: R12.2, R13.1
unnamed: R27.2, T1.1 (C)
unnamed: C133.1, U1.9 (BOOT)
unnamed: C7.1, R7.1, U1.7 (COMP)
unnamed: R1.2, R2.1, U1.8 (EN)
unnamed: C133.2, L1.1, U1.2 (PH)
unnamed: R3.1, U1.10 (RT)
unnamed: C3.1, U2.9 (BOOT)
unnamed: C12.1, R11.1, U2.7 (COMP)
unnamed: R8.2, R9.1, U2.8 (EN)
unnamed: C3.2, L2.1, U2.2 (PH)
unnamed: R10.1, U2.10 (RT)
unnamed: R15.1, R16.2, U3.4 (EN1)
unnamed: R21.1, R22.2, U3.2 (EN2)
unnamed: R17.1, R18.2, U3.8 (FB1)
unnamed: R19.1, R20.2, U3.1 (FB2)
unnamed: L3.2, U3.6 (SW1)
unnamed: L4.1, U3.3 (SW2)
unnamed: R26.1, U5.36 (REXT)
unnamed: C21.2, R23.1, U5.1 (TME)
unnamed: R25.1, U5.37 (UAO/GPIO8)
VBUS: C46.2, C47.2, J1.1 (VBUS), U5.12 (VBUS), U5.45 (VREG_IN)
VDC: J2.1, J3.1, Q1.1 (S), Q1.2 (S), Q1.3 (S), Q2.1 (S), Q2.2 (S), Q2.3 (S), R34.1
Vin_12V: C1.2, C2.2, C8.2, C9.2, C66.1, C68.1, C70.1, C72.1, C98.1, C102.1, C104.1, FAN.1, J4.P13, J4.P14, J4.P15, J5.P13, J5.P14, J5.P15, J6.P13, J6.P14, J6.P15, J7.P13, J7.P14, J7.P15, Q1.5 (D), Q1.6 (D), Q1.7 (D), Q1.8 (D), Q2.5 (D), Q2.6 (D), Q2.7 (D), Q2.8 (D), R1.1, R8.1, U1.1 (VIN), U2.1 (VIN)
Vsense-A: R5.2, R6.1, U1.6 (VSENSE)
Vsense-B: R13.2, R14.1, U2.6 (VSENSE)

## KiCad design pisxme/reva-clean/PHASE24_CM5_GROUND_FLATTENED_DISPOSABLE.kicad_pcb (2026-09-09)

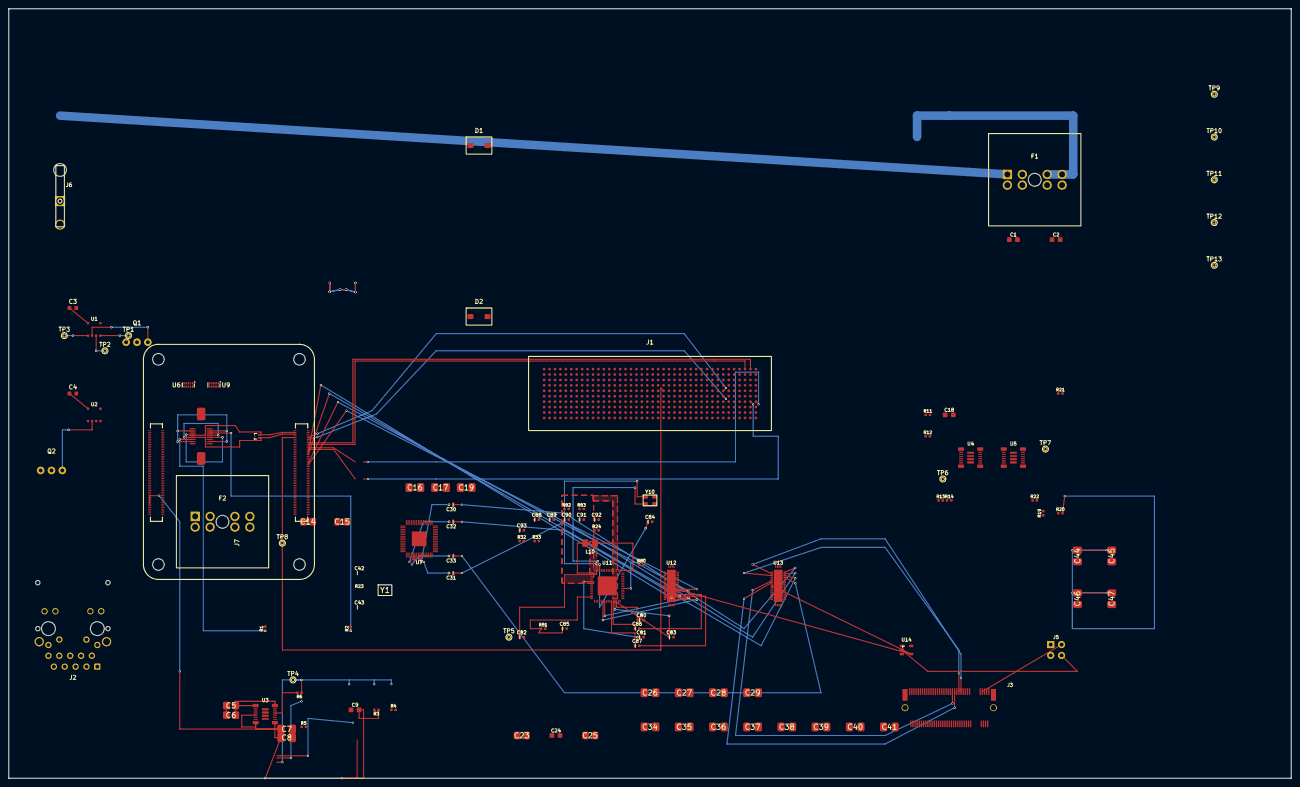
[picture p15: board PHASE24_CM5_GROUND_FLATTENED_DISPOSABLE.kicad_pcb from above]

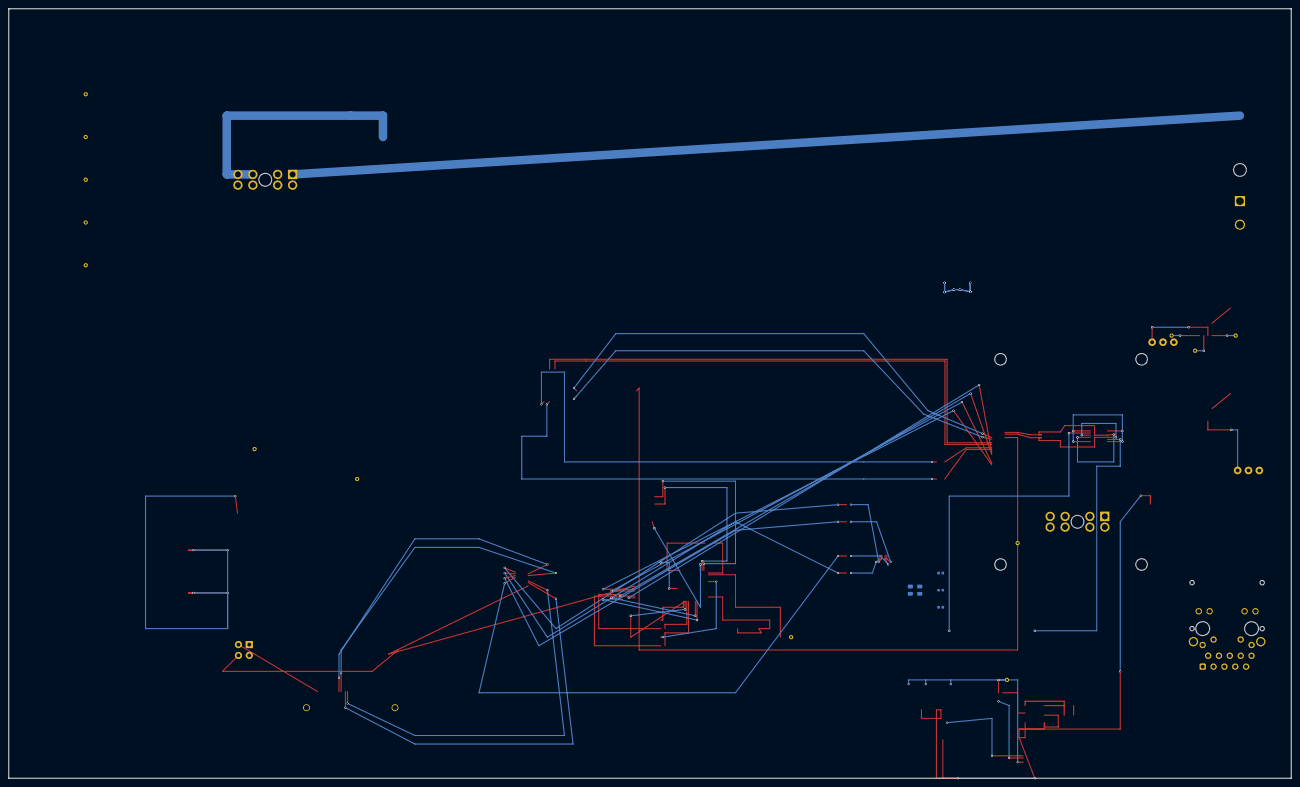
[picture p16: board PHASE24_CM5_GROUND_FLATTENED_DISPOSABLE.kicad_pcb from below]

Board: 6 copper layers, 300.0 x 180.0 mm, 119 parts (15 on the bottom side), 122 nets.

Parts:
C1, C2, C9, C18, C24: C_0805_2012Metric
C3, C4: C_0603_1608Metric
C5, C6, C14, C15, C23, C25: C_1206_3216Metric
C7, C8, C16, C17, C19, C26, C27, C28, C29, C34, C35, C36, C37, C38, C39, C40, C41, C44, C45, C46, C47: C_1210_3225Metric
C30, C31, C32, C33, C42, C43, C80, C81, C82, C83, C84, C85, C86, C87, C88, C89, C90, C91, C92, C93: C_0402_1005Metric
D1, D2: SMBJ18A; TVS_SMBJ18A_DO214AA
F1, F2: 178.6165.0001; ATO_FuseHolder_17861650001
J1: 74221-101LF; PiSXMeRevAClean_SXM2_74221_101LF
J2: A70-112-331N126; EDAC_A70_112_331N126
J3: 1-2199230-4; TE_1-2199230-4_MKEY
J4: Amphenol 10171746-00021LF USB-C USB2 SERVICE; USB_C_SERVICE_10171746
J5: MODE_JUMPER_1x04
J6: 0039300020; Molex_0039300020_5569_2P_RA
J7: Raspberry-Pi-5-Compute-Module; PiSXMeRevAClean_Raspberry_Pi_5_Compute_Module
L10: 4.7uH; L_2520_6332Metric
MECH_M2_2280: JAE SM3ZS067U410ABR1000 / 2280 card envelope; M2_2280_RETENTION_ENVELOPE
Q1, Q2: CSD19536KCS; CSD19536KCS_TO220
R1, R2, R3, R4, R5, R6, R11, R12, R13, R14, R19, R20, R21, R22, R23, R24, R32, R33, R80, R81, R82, R83: R_0402_1005Metric
TP1, TP2, TP3, TP4, TP5, TP6, TP7, TP8, TP9, TP10, TP11, TP12, TP13: REV_A_PROBE; TestPoint_THTPad_D1.0mm_Drill0.5mm
U1, U2: LM74700QDBVRQ1; LM74700QDBVRQ1_SOT23_6
U3, U4, U5: TPSM63606RDLR; TPSM63606RDLR_RDL0020
U6, U9: TPD4EUSB30; USON-10_2.5x1.0mm_P0.5mm
U7: TUSB9261IPVP; TUSB9261IPVP_PVP0064A
U8: Texas_DRT_3
U11: JMS583_QFN64_8x8
U12: HD3SS6126_RUA0042A
U13: HD3SS3412_RUA0042A
U14: SOT-23-5
Y1: Crystal_3225_4Pad
Y10: 25MHz; Crystal_3225_4Pad

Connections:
12V_PROTECTED: C5.1, C6.1, C14.1, C15.1, C23.1, C24.1, C25.1, J1.A22, J1.A23, J1.A25, J1.A26, J1.A28, J1.A29, J1.A31, J1.A32, J1.A34, J1.A35, J1.A37, J1.A38, J1.A40, J1.B22, J1.B23, J1.B25, J1.B26, J1.B28, J1.B29, J1.B31, J1.B32, J1.B34, J1.B35, J1.B37, J1.B38, J1.B40, J1.C22, J1.C23, J1.C25, J1.C26, J1.C28, J1.C29, J1.C31, J1.C32, J1.C34, J1.C35, J1.C37, J1.C38, J1.C40, J1.D22, J1.D23, J1.D25, J1.D26, J1.D28, J1.D29, J1.D31, J1.D32, J1.D34, J1.D35, J1.D37, J1.D38, J1.D40, J1.E22, J1.E23, J1.E25, J1.E26, J1.E28, J1.E29, J1.E31, J1.E32, J1.E34, J1.E35, J1.E37, J1.E38, J1.E40, J1.F22, J1.F23, J1.F25, J1.F26, J1.F28, J1.F29, J1.F31, J1.F32, J1.F34, J1.F35, J1.F37, J1.F38, J1.F40, J1.G22, J1.G23, J1.G25, J1.G26, J1.G28, J1.G29, J1.G31, J1.G32, J1.G34, J1.G35, J1.G37, J1.G38, J1.G40, J1.H22, J1.H23, J1.H25, J1.H26, J1.H28, J1.H29, J1.H31, J1.H32, J1.H34, J1.H35, J1.H37, J1.H38, J1.H40, J1.J22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
/CORE_CM5/CM5_5V: C7.1, C8.1, C9.2, J7.77, J7.79, J7.81, J7.83, J7.85, J7.87, R3.1, R6.1, TP4.1, U3.5, U3.8, U3.9
/CORE_CM5/CM5_PER0_N: J1.A3, J7.118
/CORE_CM5/CM5_PER0_P: J1.A2, J7.116
/CORE_CM5/CM5_PERST: J1.E18, J7.109, TP8.1
/CORE_CM5/CM5_PET0_N: C2.1, J7.124
/CORE_CM5/CM5_PET0_P: C1.1, J7.122
/CORE_CM5/CM5_REFCLK_N: J1.F7, J7.112
/CORE_CM5/CM5_REFCLK_P: J1.E7, J7.110
/CORE_CM5/SERVICE_USB2_DM: J4.A7, J4.B7, J7.103, U8.2
/CORE_CM5/SERVICE_USB2_DP: J4.A6, J4.B6, J7.105, U8.1
/ETHERNET/GBE_SHIELD: J2.19, J2.20
/POWER_INPUT/12V_IN_A: C3.2, F1.1, F1.2, F1.3, F1.4, TP1.1, U1.3
/POWER_INPUT/12V_IN_B: C4.2, F2.1, F2.2, F2.3, F2.4, J6.1, U2.3
/POWER_INPUT/FUSED_12V_A: D1.1, F1.5, F1.6, F1.7, F1.8, Q1.1, TP2.1, U1.6
/POWER_INPUT/FUSED_12V_B: D2.1, F2.5, F2.6, F2.7, F2.8, Q2.1, U2.6
/POWER_INPUT/GATE_A: Q1.3, U1.5
/POWER_INPUT/GATE_B: Q2.3, U2.5
/POWER_INPUT/VCAP_A: C3.1, U1.1
/POWER_INPUT/VCAP_B: C4.1, U2.1
/REGULATORS/BRIDGE_1V1: C26.1, C27.1, C28.1, C29.1, C34.1, C35.1, C36.1, C37.1, C38.1, C39.1, C40.1, C41.1, C44.1, C45.1, C46.1, C47.1, R19.1, R22.1, U5.5, U5.8, U5.9
/REGULATORS/BRIDGE_3V3: C16.1, C17.1, C18.2, C19.1, R11.1, R14.1, U4.5, U4.8, U4.9
/REGULATORS/FB_BRIDGE_1V1: R19.2, R20.1, U5.10
/REGULATORS/FB_BRIDGE_3V3: C18.1, R11.2, R12.1, U4.10
/REGULATORS/FB_CM5_5V: C9.1, R3.2, R4.1, U3.10
/REGULATORS/NC: U3.15, U4.15, U5.15
/REGULATORS/PG_BRIDGE_1V1: R22.2, TP7.1, U5.13
/REGULATORS/PG_BRIDGE_3V3: R14.2, TP6.1, U4.13
/REGULATORS/PG_CM5_5V: R6.2, U3.13
/REGULATORS/RT_BRIDGE_1V1: R21.1, U5.12
/REGULATORS/RT_BRIDGE_3V3: R13.1, U4.12
/REGULATORS/RT_CM5_5V: R5.1, U3.12
/SERVICE/SERVICE_RD_A: J4.A5, R1.1
/SERVICE/SERVICE_RD_B: J4.B5, R2.1
/SERVICE/SERVICE_VBUS_SENSE: J4.A4, J4.A9, J4.B4, J4.B9
/STORAGE/BRIDGE_SATA_RX_N: C33.2 (BRIDGE_SATA_RX_N), U7.59
/STORAGE/BRIDGE_SATA_RX_P: C32.2 (BRIDGE_SATA_RX_P), U7.60
/STORAGE/BRIDGE_SATA_TX_N: C31.2 (BRIDGE_SATA_TX_N), U7.56
/STORAGE/BRIDGE_SATA_TX_P: C30.2 (BRIDGE_SATA_TX_P), U7.57
/STORAGE/BRIDGE_VSSOSC: C42.2, C43.2, U7.53, Y1.2, Y1.4
/STORAGE/BRIDGE_XI: C42.1, R23.1, U7.52, Y1.1
/STORAGE/BRIDGE_XO: C43.1, R23.2, U7.54, Y1.3
/V100_PCIE/V100_PET0_N: C2.2, J1.G2
/V100_PCIE/V100_PET0_P: C1.2, J1.G1
AUTO_PEDET: J3.69 (AUTO_PEDET), J5.2 (AUTO_PEDET)
BRIDGE_1V1: U7.1, U7.12, U7.19, U7.32, U7.33, U7.41, U7.47, U7.49, U7.55, U7.61, U7.63
BRIDGE_3V3: U7.7, U7.24, U7.30, U7.31, U7.34, U7.40, U7.48, U7.51, U7.62
BRIDGE_R1: R24.1 (BRIDGE_R1), U7.38
BRIDGE_R1RTN: R24.2 (BRIDGE_R1RTN), U7.39
BRIDGE_USB_DM: U7.35, U12.32 (BRIDGE_USB_DM)
BRIDGE_USB_DP: U7.36, U12.31 (BRIDGE_USB_DP)
BRIDGE_USB_VBUS: R32.2 (BRIDGE_USB_VBUS), R33.1 (BRIDGE_USB_VBUS), U7.50
CM5_GBE_TD0_N: J2.2, J7.10, U6.2 (D1-), U6.9
CM5_GBE_TD0_P: J2.1, J7.12, U6.1 (D1+), U6.10
CM5_GBE_TD1_N: J2.6, J7.6, U6.4 (D2+), U6.7
CM5_GBE_TD1_P: J2.3, J7.4, U6.5 (D2-), U6.6
CM5_GBE_TD2_N: J2.8, J7.9, U9.2 (D1-), U9.9
CM5_GBE_TD2_P: J2.7, J7.11, U9.1 (D1+), U9.10
CM5_GBE_TD3_N: J2.10, J7.5, U9.4 (D2+), U9.7
CM5_GBE_TD3_P: J2.9, J7.3, U9.5 (D2-), U9.6
CM5_USB3_RX_N: J7.128, U7.42, U12.16 (CM5_USB3_RX_N)
CM5_USB3_RX_P: J7.130, U7.43, U12.15 (CM5_USB3_RX_P)
CM5_USB3_TX_N: J7.140, U7.45, U12.12 (CM5_USB3_TX_N)
CM5_USB3_TX_P: J7.142, U7.46, U12.11 (CM5_USB3_TX_P)
JMS_AVDD33: C80.1 (JMS_AVDD33), U11.19 (JMS_AVDD33)
JMS_AVDDL: C83.1 (JMS_AVDDL), J3.20 (JMS_AVDDL), J3.30 (JMS_AVDDL), J3.36 (JMS_AVDDL), J3.40 (JMS_AVDDL), J3.46 (JMS_AVDDL), U11.20 (JMS_AVDDL), U11.25 (JMS_AVDDL), U11.30 (JMS_AVDDL), U11.33 (JMS_AVDDL), U11.36 (JMS_AVDDL), U11.40 (JMS_AVDDL), U11.43 (JMS_AVDDL), U11.46 (JMS_AVDDL), U11.49 (JMS_AVDDL), U12.36 (JMS_AVDDL), U12.40 (JMS_AVDDL), U13.40 (JMS_AVDDL)
JMS_GPIO4_NC: J3.8 (JMS_GPIO4_NC), U11.8 (JMS_GPIO4_NC), U13.8 (JMS_GPIO4_NC)
JMS_PCIE_TXN0: C91.2 (JMS_PCIE_TXN0), U13.33 (JMS_PCIE_TXN0)
JMS_PCIE_TXN1: C93.2 (JMS_PCIE_TXN1), U13.24 (JMS_PCIE_TXN1)
JMS_PCIE_TXP0: C90.2 (JMS_PCIE_TXP0), U13.34 (JMS_PCIE_TXP0)
JMS_PCIE_TXP1: C92.2 (JMS_PCIE_TXP1), U13.25 (JMS_PCIE_TXP1)
JMS_RESET_N: C85.1 (JMS_RESET_N), R81.1 (JMS_RESET_N), U11.15 (JMS_RESET_N)
JMS_REXT: R80.1 (JMS_REXT), U11.39 (JMS_REXT)
JMS_SPI_SCK_DNP: U11.4 (JMS_SPI_SCK_DNP), U12.4 (JMS_SPI_SCK_DNP)
JMS_SPI_SI_DNP: U11.5 (JMS_SPI_SI_DNP), U12.5 (JMS_SPI_SI_DNP)
JMS_SPI_SO_DNP: U11.3 (JMS_SPI_SO_DNP), U12.3 (JMS_SPI_SO_DNP)
JMS_USB3_TXN: C87.2 (JMS_USB3_TXN), U12.24 (JMS_USB3_TXN)
JMS_USB3_TXP: C86.2 (JMS_USB3_TXP), U12.25 (JMS_USB3_TXP)
JMS_VBUS_SENSE: R82.2 (JMS_VBUS_SENSE), R83.1 (JMS_VBUS_SENSE), U11.10 (JMS_VBUS_SENSE)
JMS_VCCK: C82.1 (JMS_VCCK), U11.2 (JMS_VCCK), U11.31 (JMS_VCCK), U11.53 (JMS_VCCK), U12.2 (JMS_VCCK)
JMS_VCCO: C81.1 (JMS_VCCO), J3.6 (JMS_VCCO), J3.32 (JMS_VCCO), U11.6 (JMS_VCCO), U11.11 (JMS_VCCO), U11.32 (JMS_VCCO), U11.56 (JMS_VCCO)
JMS_VDDREG_5V: L10.2 (JMS_VDDREG_5V), U11.1 (JMS_VDDREG_5V), U12.1 (JMS_VDDREG_5V), U14.1 (JMS_VDDREG_5V)
JMS_XAVDDH: C84.1 (JMS_XAVDDH), U11.52 (JMS_XAVDDH)
LXO: L10.1 (LXO), U11.64 (LXO)
M2_3V3: J3.2 (M2_3V3), J3.4 (M2_3V3), J3.12 (M2_3V3), J3.14 (M2_3V3), J3.16 (M2_3V3), J3.18 (M2_3V3), J3.70 (M2_3V3), J3.72 (M2_3V3), J3.74 (M2_3V3)
M2_PCIE_TXN2: J3.23 (M2_PCIE_TXN2), U13.12 (M2_PCIE_TXN2)
M2_PCIE_TXN3: J3.11 (M2_PCIE_TXN3), U13.16 (M2_PCIE_TXN3)
M2_PCIE_TXP2: J3.25 (M2_PCIE_TXP2), U13.11 (M2_PCIE_TXP2)
M2_PCIE_TXP3: J3.13 (M2_PCIE_TXP3), U13.15 (M2_PCIE_TXP3)
M2_SATA_A_N_PCIE_TXN0: J3.47 (M2_SATA_A_N_PCIE_TXN0), U13.3 (M2_SATA_A_N_PCIE_TXN0)
M2_SATA_A_P_PCIE_TXP0: J3.49 (M2_SATA_A_P_PCIE_TXP0), U13.2 (M2_SATA_A_P_PCIE_TXP0)
M2_SATA_B_N_PCIE_RXP0: J3.43 (M2_SATA_B_N_PCIE_RXP0), U13.7 (M2_SATA_B_N_PCIE_RXP0)
M2_SATA_B_P_PCIE_RXN0: J3.41 (M2_SATA_B_P_PCIE_RXN0), U13.6 (M2_SATA_B_P_PCIE_RXN0)
MODE_IN: J5.4 (MODE_IN), U14.2 (MODE_IN)
NC_18: U12.18 (NC_18), U13.18 (NC_18)
NC_26: J3.26 (NC_26), U13.26 (NC_26)
NC_28: J3.28 (NC_28), U13.28 (NC_28)
NC_39: U12.39 (NC_39), U13.39 (NC_39)
NC_41: U12.41 (NC_41), U13.41 (NC_41)
NC_42: J3.42 (NC_42), U12.42 (NC_42), U13.42 (NC_42)
PCIE_TXN0: C91.1 (PCIE_TXN0), U11.44 (PCIE_TXN0)
PCIE_TXN1: C93.1 (PCIE_TXN1), U11.37 (PCIE_TXN1)
PCIE_TXP0: C90.1 (PCIE_TXP0), U11.45 (PCIE_TXP0)
PCIE_TXP1: C92.1 (PCIE_TXP1), U11.38 (PCIE_TXP1)
POWER_GND: C5.2, C6.2, C7.2, C8.2, C14.2, C15.2, C16.2, C17.2, C19.2, C23.2, C24.2, C25.2, C26.2, C27.2, C28.2, C29.2, C34.2, C35.2, C36.2, C37.2, C38.2, C39.2, C40.2, C41.2, C44.2, C45.2, C46.2, C47.2, C80.2 (POWER_GND), C81.2 (POWER_GND), C82.2 (POWER_GND), C83.2 (POWER_GND), C84.2 (POWER_GND), C85.2 (POWER_GND), D1.2, D2.2, J1.A21, J1.A24, J1.A27, J1.A30, J1.A33, J1.A36, J1.A39, J1.B21, J1.B24, J1.B27, J1.B30, J1.B33, J1.B36, J1.B39, J1.C21, J1.C24, J1.C27, J1.C30, J1.C33, J1.C36, J1.C39, J1.D21, J1.D24, J1.D27, J1.D30, J1.D33, J1.D36, J1.D39, J1.E21, J1.E24, J1.E27, J1.E30, J1.E33, J1.E36, J1.E39, J1.F21, J1.F24, J1.F27, J1.F30, J1.F33, J1.F36, J1.F39, J1.G21, J1.G24, J1.G27, J1.G30, J1.G33, J1.G36, J1.G39, J1.H21, J1.H24, J1.H27, J1.H30, J1.H33, J1.H36, J1.H39, J1.J21, J1.J24, J1.J27, J1.J30, J1.J33, J1.J36, J1.J39, J1.K21, J1.K24, J1.K27, J1.K30, J1.K33, J1.K36, J1.K39, J3.3 (POWER_GND), J3.9 (POWER_GND), J3.15 (POWER_GND), J3.27 (POWER_GND), J3.33 (POWER_GND), J3.39 (POWER_GND)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
STORAGE_3V3: R81.2 (STORAGE_3V3), U12.13 (STORAGE_3V3), U12.20 (STORAGE_3V3), U12.30 (STORAGE_3V3), U13.5 (STORAGE_3V3), U13.13 (STORAGE_3V3), U13.20 (STORAGE_3V3), U13.30 (STORAGE_3V3), U14.5 (STORAGE_3V3)
STORAGE_SEL: U12.9 (STORAGE_SEL), U13.9 (STORAGE_SEL), U14.4 (STORAGE_SEL)
TUSB_SATA_RXN: C33.1 (TUSB_SATA_RXN), U13.35 (TUSB_SATA_RXN)
TUSB_SATA_RXP: C32.1 (TUSB_SATA_RXP), U13.36 (TUSB_SATA_RXP)
TUSB_SATA_TXN: C31.1 (TUSB_SATA_TXN), U13.37 (TUSB_SATA_TXN)
TUSB_SATA_TXP: C30.1 (TUSB_SATA_TXP), U13.38 (TUSB_SATA_TXP)
USB_DM: U11.17 (USB_DM), U12.34 (USB_DM)
USB_DP: U11.18 (USB_DP), U12.33 (USB_DP)
USB_RXN1: U11.27 (USB_RXN1), U12.22 (USB_RXN1)
USB_RXP1: U11.26 (USB_RXP1), U12.23 (USB_RXP1)
USB_TXN1: C87.1 (USB_TXN1), U11.22 (USB_TXN1)
USB_TXN2: C89.1 (USB_TXN2), U11.23 (USB_TXN2)
USB_TXP1: C86.1 (USB_TXP1), U11.21 (USB_TXP1)
USB_TXP2: C88.1 (USB_TXP2), U11.24 (USB_TXP2)
VBUS: R82.1 (VBUS), U11.16 (VBUS)
XIN: U11.50 (XIN), Y10.1 (XIN)
XOUT: U11.51 (XOUT), Y10.2 (XOUT)

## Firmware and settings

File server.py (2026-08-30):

from __future__ import annotations

import json
import os
import base64
import subprocess
import uuid
from functools import wraps
from pathlib import Path
from typing import Any, Optional

from mcp.server.fastmcp import FastMCP

from bridge.core import (
    ApiRegistry,
    BridgeError,
    CliRunner,
    FileScope,
    KicadSession,
    _board_items,
    _infer_response_type,
    _kiid,
    _new_footprint,
    _new_text,
    enum_name,
    enum_value,
    item_id,
    item_summary,
    jsonable,
)
from bridge.schematic_backend import SchematicBackend, SchematicDocument
from kipy.board_types import (
    BoardCircle,
    BoardLayer,
    BoardRectangle,
    BoardSegment,
    BoardText,
    FootprintInstance,
    Net,
    Track,
    Via,
    ViaType,
)
from kipy.common_types import GraphicAttributes, TextAttributes
from kipy.geometry import Angle, Vector2
from kipy.proto.board import board_commands_pb2, board_types_pb2
from kipy.proto.common.commands import editor_commands_pb2, project_commands_pb2
from kipy.proto.common.types import base_types_pb2
from kipy.proto.common.types.base_types_pb2 import DocumentType, MapMergeMode
from kipy.proto.common.types.enums_pb2 import KiCadObjectType
from kipy.util import from_mm
from google.protobuf.empty_pb2 import Empty


ROOT = os.environ.get("KICAD_PROJECT_ROOT") or os.getcwd()
scope = FileScope(ROOT)
session = KicadSession(timeout_ms=int(os.environ.get("KICAD_IPC_TIMEOUT_MS", "5000")))
cli = CliRunner(scope.root)
registry = ApiRegistry()
schematic_backend = SchematicBackend()
schematic_documents: dict[str, SchematicDocument] = {}

mcp = FastMCP(
    "kicad-codex-bridge",
    instructions=(
        "Use official KiCad IPC through kicad-python for live PCB work. "
        "Check kicad_connection_status before writes. Live IPC requires KiCad's GUI PCB editor "
        "and the enabled API server. Use kicad_drc/kicad_erc or kicad_cli_export for validation "
        "and manufacturing outputs. Schematic authoring uses the scoped direct .kicad_sch backend "
        "and must be followed by native KiCad ERC/parity validation. All API errors are returned."
    ),
)


def _tool_error(fn):
    @wraps(fn)
    def wrapped(*args, **kwargs):
        try:
            return fn(*args, **kwargs)
        except BridgeError:
            raise
        except Exception as exc:
            raise BridgeError(f"{fn.__name__} failed: {type(exc).__name__}: {exc}") from exc

    return wrapped


def _doc_dict(doc: Any) -> dict[str, Any]:
    return jsonable(doc)


@mcp.tool()
@_tool_error
def kicad_connection_status(probe: bool = True) -> dict[str, Any]:
    """Discover KiCad IPC sockets and optionally perform a live version handshake."""
    return session.status(probe=probe)


@mcp.tool()
@_tool_error
def kicad_get_version() -> dict[str, Any]:
    """Return live KiCad version when IPC is available, plus the installed CLI version."""
    result: dict[str, Any] = {"installed_cli": cli.version(), "live": None}
    try:
        result["live"] = jsonable(session.call(lambda k: k.get_version()))
    except BridgeError as exc:
        result["live_error"] = str(exc)
    return result


@mcp.tool()
@_tool_error
def kicad_list_open_documents() -> dict[str, Any]:
    """List open KiCad documents by type through the live IPC server."""
    def collect(kicad):
        docs = []
        for doc_type in DocumentType.DESCRIPTOR.values:
            if doc_type.name == "DOCTYPE_UNKNOWN":
                continue
            try:
                found = kicad.get_open_documents(doc_type.number)
            except Exception as exc:
                docs.append({"type": doc_type.name, "error": str(exc)})
                continue
            docs.extend({"type": doc_type.name, "document": _doc_dict(doc)} for doc in found)
        return docs

    return {"documents": session.call(collect)}


@mcp.tool()
@_tool_error
def kicad_get_active_document() -> dict[str, Any]:
    """Return open documents and explain that KiCad 10 IPC does not expose active-document identity."""
    docs = kicad_list_open_documents()
    docs["active_document"] = None
    docs["limitation"] = "The installed KiCad 10 IPC messages expose open documents, not active-document identity."
    return docs


@mcp.tool()
@_tool_error
def kicad_open_file(path: str) -> dict[str, Any]:
    """Open a scoped KiCad project/board/schematic with the native macOS application association."""
    target = scope.resolve(path, must_exist=True)
    suffix = target.suffix.lower()
    if suffix not in {".kicad_pro", ".kicad_pcb", ".kicad_sch", ".kicad_sym", ".kicad_mod"}:
        raise BridgeError(f"Not a recognized KiCad design file: {target}")
    completed = __import__("subprocess").run(["open", str(target)], capture_output=True, text=True, check=False)
    return {"path": str(target), "returncode": completed.returncode, "stdout": completed.stdout, "stderr": completed.stderr}


def _schematic_document(path: str) -> tuple[Path, SchematicDocument]:
    target = scope.resolve(path, must_exist=True)
    if target.suffix.lower() != ".kicad_sch":
        raise BridgeError(f"Not a KiCad schematic: {target}")
    key = str(target)
    document = schematic_documents.get(key)
    if document is None:
        document = schematic_backend.open(target)
        schematic_documents[key] = document
    return target, document


@mcp.tool()
@_tool_error
def kicad_sch_open(path: str) -> dict[str, Any]:
    """Load a scoped .kicad_sch through the direct schematic backend."""
    target = scope.resolve(path, must_exist=True)
    if target.suffix.lower() != ".kicad_sch":
        raise BridgeError(f"Not a KiCad schematic: {target}")
    document = schematic_backend.open(target)
    schematic_documents[str(target)] = document
    return document.info()


@mcp.tool()
@_tool_error
def kicad_sch_create(name: str = "Untitled", path: Optional[str] = None) -> dict[str, Any]:
    """Create a new in-memory schematic, optionally saving it atomically to a scoped path."""
    document = schematic_backend.create(name)
    if path is None:
        raise BridgeError("A scoped .kicad_sch path is required for a durable schematic")
    target = scope.resolve(path)
    if target.suffix.lower() != ".kicad_sch":
        raise BridgeError(f"Not a KiCad schematic target: {target}")
    document.save(target, validate=False)
    schematic_documents[str(target)] = document
    return document.info()


@mcp.tool()
@_tool_error
def kicad_sch_get_info(path: str) -> dict[str, Any]:
    """Return schematic source identity and object statistics."""
    return _schematic_document(path)[1].info()


@mcp.tool()
@_tool_error
def kicad_sch_validate(path: str) -> dict[str, Any]:
    """Run direct-library structural validation; use kicad_erc for native KiCad ERC."""
    return _schematic_document(path)[1].validate()


@mcp.tool()
@_tool_error
def kicad_sch_add_symbol_library(path: str) -> dict[str, Any]:
    """Register a project-local .kicad_sym library before adding custom symbols."""
    target = scope.resolve(path, must_exist=True)
    return schematic_backend.add_symbol_library(target)


@mcp.tool()
@_tool_error
def kicad_sch_save(path: str, target: Optional[str] = None, validate: bool = True) -> dict[str, Any]:
    """Atomically save an open schematic after direct-library parse/reopen validation."""
    source, document = _schematic_document(path)
    destination = scope.resolve(target) if target else source
    result = document.save(destination, validate=validate)
    schematic_documents[str(destination)] = document
    if destination != source:
        schematic_documents.pop(str(source), None)
    return result


@mcp.tool()
@_tool_error
def kicad_sch_save_and_validate(
    path: str,
    target: Optional[str] = None,
    baseline_erc: Optional[str] = None,
    netlist_output: Optional[str] = None,
    timeout: int = 120,
) -> dict[str, Any]:
    """Promote a schematic only after native KiCad ERC and optional netlist export.

    A baseline KiCad JSON ERC report can be supplied for legacy sources.  In
    that case only newly introduced ERC errors block promotion; without a
    baseline, any native ERC error blocks it.  Warnings remain visible but do
    not block promotion.
    """
    source, document = _schematic_document(path)
    destination = scope.resolve(target) if target else source
    baseline = None
    if baseline_erc is not None:
        baseline_path = scope.resolve(baseline_erc, must_exist=True)
        try:
            baseline = json.loads(baseline_path.read_text(encoding="utf-8"))
        except (OSError, json.JSONDecodeError) as exc:
            raise BridgeError(f"Invalid baseline ERC JSON {baseline_path}: {exc}") from exc
    netlist = scope.resolve(netlist_output) if netlist_output else None
    result = document.save_and_native_validate(
        destination,
        cli,
        baseline=baseline,
        export_netlist=netlist,
        timeout=timeout,
    )
    schematic_documents[str(destination)] = document
    if destination != source:
        schematic_documents.pop(str(source), None)
    return result


@mcp.tool()
@_tool_error
def kicad_sch_add_symbol(
    path: str,
    lib_id: str,
    reference: Optional[str] = None,
    value: str = "",
    x_mm: float = 100.33,
    y_mm: float = 100.33,
    footprint: Optional[str] = None,
    unit: int = 1,
) -> dict[str, Any]:
    """Add a library-backed symbol; pin mapping remains owned by KiCad libraries."""
    document = _schematic_document(path)[1]
    component = schematic_backend.add_symbol(
        document,
        lib_id=lib_id,
        reference=reference,
        value=value,
        position=(x_mm, y_mm),
        footprint=footprint,
        unit=unit,
    )
    return {"reference": component.reference, "lib_id": component.lib_id, "pins": component.list_pins()}


@mcp.tool()
@_tool_error
def kicad_sch_remove_symbol(path: str, reference: str) -> dict[str, Any]:
    """Remove a symbol by reference from the in-memory schematic."""
    removed = schematic_backend.remove_symbol(_schematic_document(path)[1], reference)
    return {"reference": reference, "removed": removed}


@mcp.tool()
@_tool_error
def kicad_sch_set_symbol_property(path: str, reference: str, name: str, value: str) -> dict[str, Any]:
    """Set one symbol property without editing schematic S-expressions directly."""
    document = _schematic_document(path)[1]
    schematic_backend.set_symbol_property(document, reference, name, value)
    return {"reference": reference, "property": name, "value": value}


@mcp.tool()
@_tool_error
def kicad_sch_set_footprint(path: str, reference: str, footprint: str) -> dict[str, Any]:
    """Assign a footprint property to a schematic symbol."""
    document = _schematic_document(path)[1]
    schematic_backend.set_footprint(document, reference, footprint)
    return {"reference": reference, "footprint": footprint}


@mcp.tool()
@_tool_error
def kicad_sch_get_pins(path: str, reference: str) -> dict[str, Any]:
    """Return library-resolved pin numbers, names, types, and relative positions."""
    return {"reference": reference, "pins": schematic_backend.get_pins(_schematic_document(path)[1], reference)}


@mcp.tool()
@_tool_error
def kicad_sch_connect_pins(path: str, first_reference: str, first_pin: str, second_reference: str, second_pin: str) -> dict[str, Any]:
    """Connect two symbol pins with a backend-generated wire."""
    wire = schematic_backend.connect_pins(
        _schematic_document(path)[1], (first_reference, first_pin), (second_reference, second_pin)
    )
    return {"wire_uuid": wire, "first": [first_reference, first_pin], "second": [second_reference, second_pin]}


@mcp.tool()
@_tool_error
def kicad_sch_add_wire(path: str, start_x_mm: float, start_y_mm: float, end_x_mm: float, end_y_mm: float) -> dict[str, Any]:
    """Add a schematic wire in millimetres."""
    wire = schematic_backend.add_wire(_schematic_document(path)[1], (start_x_mm, start_y_mm), (end_x_mm, end_y_mm))
    return {"wire_uuid": wire}


@mcp.tool()
@_tool_error
def kicad_sch_remove_wire(path: str, wire_uuid: str) -> dict[str, Any]:
    """Remove one wire by UUID from the open schematic."""
    removed = schematic_backend.remove_wire(_schematic_document(path)[1], wire_uuid)
    return {"wire_uuid": wire_uuid, "removed": removed}


@mcp.tool()
@_tool_error
def kicad_sch_add_junction(path: str, x_mm: float, y_mm: float) -> dict[str, Any]:
    """Add an explicit schematic wire junction."""
    uuid = schematic_backend.add_junction(_schematic_document(path)[1], (x_mm, y_mm))
    return {"junction_uuid": uuid, "x_mm": x_mm, "y_mm": y_mm}


@mcp.tool()
@_tool_error
def kicad_sch_move_symbol(path: str, reference: str, x_mm: float, y_mm: float) -> dict[str, Any]:
    """Move a symbol using schematic-library coordinates."""
    schematic_backend.move_symbol(_schematic_document(path)[1], reference, (x_mm, y_mm))
    return {"reference": reference, "x_mm": x_mm, "y_mm": y_mm}


@mcp.tool()
@_tool_error
def kicad_sch_rotate_symbol(path: str, reference: str, rotation: float) -> dict[str, Any]:
    """Rotate a symbol; callers must re-check pin coordinates after rotation."""
    schematic_backend.rotate_symbol(_schematic_document(path)[1], reference, rotation)
    return {"reference": reference, "rotation": rotation}


@mcp.tool()
@_tool_error
def kicad_sch_get_pin_position(path: str, reference: str, pin: str) -> dict[str, Any]:
    """Return one resolved pin position."""
    point = schematic_backend.get_pin_position(_schematic_document(path)[1], reference, pin)
    return {"reference": reference, "pin": pin, "position": {"x": point.x, "y": point.y}}


@mcp.tool()
@_tool_error
def kicad_sch_add_label(path: str, text: str, x_mm: float, y_mm: float, hierarchical: bool = False) -> dict[str, Any]:
    """Add a local or hierarchical label at a specified schematic coordinate."""
    document = _schematic_document(path)[1]
    if hierarchical:
        label_uuid = schematic_backend.add_hierarchical_label(document, text, (x_mm, y_mm))
    else:
        label_uuid = schematic_backend.add_label(document, text, (x_mm, y_mm))
    return {"label_uuid": label_uuid, "text": text, "hierarchical": hierarchical}


@mcp.tool()
@_tool_error
def kicad_sch_add_global_label(path: str, text: str, x_mm: float, y_mm: float, shape: str = "input") -> dict[str, Any]:
    """Add a global label through the schematic backend."""
    label_uuid = schematic_backend.add_global_label(_schematic_document(path)[1], text, (x_mm, y_mm), shape=shape)
    return {"label_uuid": label_uuid, "text": text, "shape": shape}


@mcp.tool()
@_tool_error
def kicad_sch_add_power_symbol(path: str, lib_id: str, reference: str, x_mm: float, y_mm: float) -> dict[str, Any]:
    """Add a library-backed power symbol using the same symbol path as ordinary components."""
    document = _schematic_document(path)[1]
    component = schematic_backend.add_symbol(
        document, lib_id=lib_id, reference=reference, value=lib_id.rsplit(":", 1)[-1], position=(x_mm, y_mm)
    )
    return {"reference": component.reference, "lib_id": component.lib_id}


@mcp.tool()
@_tool_error
def kicad_sch_add_no_connect(path: str, x_mm: float, y_mm: float) -> dict[str, Any]:
    """Add a no-connect marker at a schematic coordinate."""
    marker = schematic_backend.add_no_connect(_schematic_document(path)[1], (x_mm, y_mm))
    return {"uuid": marker.uuid, "x_mm": x_mm, "y_mm": y_mm}


@mcp.tool()
@_tool_error
def kicad_sch_remove_no_connect(path: str, marker_uuid: str) -> dict[str, Any]:
    """Remove one no-connect marker by UUID."""
    removed = schematic_backend.remove_no_connect(_schematic_document(path)[1], marker_uuid)
    return {"uuid": marker_uuid, "removed": removed}


@mcp.tool()
@_tool_error
def kicad_sch_trace_net(path: str, reference: str, pin: str) -> dict[str, Any]:
    """Trace direct-library connectivity from a symbol pin."""
    return {"reference": reference, "pin": pin, "connected_pins": schematic_backend.trace_net(_schematic_document(path)[1], reference, pin)}


@mcp.tool()
@_tool_error
def kicad_sch_add_sheet(
    path: str,
    name: str,
    filename: str,
    x_mm: float,
    y_mm: float,
    width_mm: float = 50.8,
    height_mm: float = 38.1,
) -> dict[str, Any]:
    """Add a hierarchical sheet declaration to an open root schematic."""
    sheet_uuid = schematic_backend.add_sheet(
        _schematic_document(path)[1],
        name=name,
        filename=filename,
        position=(x_mm, y_mm),
        size=(width_mm, height_mm),
    )
    return {"sheet_uuid": sheet_uuid, "name": name, "filename": filename}


@mcp.tool()
@_tool_error
def kicad_sch_add_sheet_pin(
    path: str,
    sheet_uuid: str,
    name: str,
    pin_type: str,
    edge: str,
    position_along_edge_mm: float,
) -> dict[str, Any]:
    """Add a typed hierarchical pin to a sheet declaration."""
    pin_uuid = schematic_backend.add_sheet_pin(
        _schematic_document(path)[1],
        sheet_uuid=sheet_uuid,
        name=name,
        pin_type=pin_type,
        edge=edge,
        position_along_edge=position_along_edge_mm,
    )
    return {"pin_uuid": pin_uuid, "sheet_uuid": sheet_uuid, "name": name}


@mcp.tool()
@_tool_error
def kicad_sch_remove_sheet(path: str, sheet_uuid: str) -> dict[str, Any]:
    """Remove a hierarchical sheet declaration by UUID."""
    removed = schematic_backend.remove_sheet(_schematic_document(path)[1], sheet_uuid)
    return {"sheet_uuid": sheet_uuid, "removed": removed}


@mcp.tool()
@_tool_error
def kicad_sch_list_nets(path: str) -> dict[str, Any]:
    """Return direct-library net records for an open schematic."""
    nets = schematic_backend.list_nets(_schematic_document(path)[1])
    records = []
    for net in nets:
        to_dict = getattr(net, "to_dict", None)
        records.append(to_dict() if callable(to_dict) else {"name": getattr(net, "name", str(net))})
    return {"nets": records}


@mcp.tool()
@_tool_error
def kicad_sch_list_sheets(path: str) -> dict[str, Any]:
    """List hierarchical sheet declarations and pins."""
    return {"sheets": schematic_backend.list_sheets(_schematic_document(path)[1])}


@mcp.tool()
@_tool_error
def kicad_sch_validate_hierarchy(path: str) -> dict[str, Any]:
    """Validate sheet references and hierarchical pin connectivity."""
    return schematic_backend.validate_hierarchy(_schematic_document(path)[1])


@mcp.tool()
@_tool_error
def kicad_sch_find_unconnected_pins(path: str) -> dict[str, Any]:
    """Return library-level connectivity summary for follow-up native ERC."""
    return schematic_backend.find_unconnected_pins(_schematic_document(path)[1])


@mcp.tool()
@_tool_error
def kicad_sch_connectivity_report(path: str) -> dict[str, Any]:
    """Return deterministic structural/connectivity statistics."""
    return schematic_backend.connectivity_report(_schematic_document(path)[1])


@mcp.tool()
@_tool_error
def kicad_sch_search_symbols(pattern: str) -> dict[str, Any]:
    """Search installed and registered project-local symbol libraries."""
    return {"pattern": pattern, "symbols": schematic_backend.search_symbols(pattern)}


@mcp.tool()
@_tool_error
def kicad_sch_get_symbol(lib_id: str) -> dict[str, Any]:
    """Inspect a symbol definition without inferring pin mappings."""
    return {"lib_id": lib_id, "symbol": schematic_backend.get_symbol(lib_id)}


def _board() -> Any:
    return session.board()


def _find_footprint(board: Any, reference_or_id: str) -> FootprintInstance:
    for footprint in board.get_footprints():
        if footprint.reference_field.text.value == reference_or_id or item_id(footprint) == reference_or_id:
            return footprint
    raise BridgeError(f"No footprint found for reference or id {reference_or_id!r}")


@mcp.tool()
@_tool_error
def kicad_board_summary(include_raw: bool = False) -> dict[str, Any]:
    """Inspect the open PCB's file name, item counts, layers, nets, stackup, and title block."""
    def collect(_kicad):
        board = _board()
        collections = ["footprints", "pads", "tracks", "vias", "zones", "graphics", "text", "dimensions", "barcodes", "reference_images", "groups"]
        counts = {kind: len(_board_items(board, kind)) for kind in collections}
        result = {
            "name": board.name,
            "document": jsonable(board.document),
            "counts": counts,
            "copper_layer_count": board.get_copper_layer_count(),
            "enabled_layers": [enum_name(BoardLayer, layer) for layer in board.get_enabled_layers()],
            "nets": [{"name": net.name, "code": int(net.proto.code.value)} for net in board.get_nets()],
            "title_block": jsonable(board.get_title_block_info()),
        }
        if include_raw:
            result["board_sexpr"] = board.get_as_string()
        return result

    return session.call(collect)


@mcp.tool()
@_tool_error
def kicad_board_dimensions() -> dict[str, Any]:
    """Return KiCad-calculated bounding boxes for board items and a merged content extent."""
    def collect(_kicad):
        board = _board()
        all_items = []
        for kind in ("footprints", "tracks", "vias", "zones", "graphics", "text", "dimensions", "barcodes", "reference_images"):
            all_items.extend(_board_items(board, kind))
        boxes = []
        for item in all_items:
            try:
                box = board.get_item_bounding_box(item, include_text=True)
                if box is not None:
                    boxes.append(jsonable(box))
            except Exception:
                continue
        return {"item_count": len(all_items), "boxes": boxes, "note": "Extent is computed from all returned board items; an empty board has no content extent."}

    return session.call(collect)
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

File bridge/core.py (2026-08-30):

from __future__ import annotations

import base64
import importlib
import json
import os
import pkgutil
import re
import shutil
import stat
import subprocess
import tempfile
import threading
import uuid
from collections.abc import Iterable, Mapping, Sequence
from pathlib import Path
from typing import Any, Callable, Optional

from google.protobuf import json_format
from google.protobuf.descriptor import Descriptor, EnumDescriptor, FieldDescriptor
from google.protobuf.descriptor_pb2 import FieldDescriptorProto
from google.protobuf.message import Message
from google.protobuf.message_factory import GetMessageClass

from kipy import KiCad
from kipy.board import Board
from kipy.board_types import (
    BoardLayer,
    BoardText,
    FootprintInstance,
    Footprint,
    Field,
    Net,
    Pad,
    PadStackShape,
    PadType,
    PST_NORMAL,
    Track,
    Via,
    ViaType,
)
from kipy.common_types import LibraryIdentifier, TextAttributes
from kipy.errors import ApiError
from kipy.geometry import Angle, Vector2
from kipy.proto.board import board_types_pb2
from kipy.proto.common.types import base_types_pb2
from kipy.proto.common.types.base_types_pb2 import DocumentType
from kipy.proto.common.types.enums_pb2 import KiCadObjectType
from kipy.util import from_mm


class BridgeError(RuntimeError):
    """An observable, user-facing bridge failure."""


def _proto(value: Any) -> Optional[Message]:
    if isinstance(value, Message):
        return value
    candidate = getattr(value, "proto", None)
    if isinstance(candidate, Message):
        return candidate
    if callable(candidate):
        candidate = candidate()
        if isinstance(candidate, Message):
            return candidate
    return None


def jsonable(value: Any) -> Any:
    """Convert KiCad wrappers/protobufs/enum-like objects into JSON-safe values."""
    message = _proto(value)
    if message is not None:
        return json_format.MessageToDict(
            message,
            preserving_proto_field_name=True,
            use_integers_for_enums=False,
        )
    if isinstance(value, Message):
        return json_format.MessageToDict(
            value,
            preserving_proto_field_name=True,
            use_integers_for_enums=False,
        )
    if isinstance(value, (str, int, float, bool)) or value is None:
        return value
    if isinstance(value, bytes):
        return {"base64": base64.b64encode(value).decode("ascii")}
    if isinstance(value, Mapping):
        return {str(k): jsonable(v) for k, v in value.items()}
    if isinstance(value, Sequence) and not isinstance(value, (str, bytes, bytearray)):
        return [jsonable(v) for v in value]
    if isinstance(value, Iterable):
        return [jsonable(v) for v in value]
    if hasattr(value, "full_version"):
        return {
            "major": getattr(value, "major", None),
            "minor": getattr(value, "minor", None),
            "patch": getattr(value, "patch", None),
            "full_version": value.full_version,
        }
    return repr(value)


def enum_value(enum_cls: Any, value: Any) -> int:
    if isinstance(value, int):
        return value
    if not isinstance(value, str):
        raise BridgeError(f"Enum value must be a name or integer, got {value!r}")
    wanted = re.sub(r"[^A-Za-z0-9]", "", value).lower()
    options = enum_cls.DESCRIPTOR.values
    for option in options:
        normalized = re.sub(r"[^A-Za-z0-9]", "", option.name).lower()
        if wanted in (normalized, normalized.removeprefix("bl")):
            return option.number
    raise BridgeError(
        f"Unknown {enum_cls.DESCRIPTOR.full_name} value {value!r}; "
        f"choices are {[v.name for v in options]}"
    )


def enum_name(enum_cls: Any, value: int) -> str:
    try:
        return enum_cls.Name(value)
    except Exception:
        return str(value)


def item_id(item: Any) -> Optional[str]:
    identifier = getattr(item, "id", None)
    if isinstance(identifier, Message) and hasattr(identifier, "value"):
        return str(identifier.value)
    if isinstance(identifier, str):
        return identifier
    if identifier is not None:
        candidate = getattr(identifier, "value", None)
        if candidate:
            return str(candidate)
    raw = _proto(item)
    if raw is not None and raw.DESCRIPTOR.fields_by_name.get("id") is not None:
        raw_id = getattr(raw, "id")
        if hasattr(raw_id, "value") and raw_id.value:
            return str(raw_id.value)
    return None


def item_summary(item: Any, include_raw: bool = False) -> dict[str, Any]:
    result: dict[str, Any] = {
        "type": type(item).__name__,
        "id": item_id(item),
        "repr": repr(item),
    }
    raw = jsonable(item)
    if isinstance(raw, dict):
        result["data"] = raw
    if include_raw:
        result["raw"] = raw
    return result


def _kiid(value: str) -> Message:
    result = base_types_pb2.KIID()
    result.value = value
    return result
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

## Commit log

2026-08-30 correct EDAC hole group authority
2026-08-30 add native Phase 3 contract connectivity
    [COOLING.kicad_sch, CORE_CM5.kicad_sch, DEBUG.kicad_sch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]
2026-08-30 close native Phase 3 hierarchy association
    [COOLING.kicad_sch, CORE_CM5.kicad_sch, DEBUG.kicad_sch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]
2026-08-30 stabilize Phase 3 hierarchy netlist references
    [COOLING.kicad_sch, CORE_CM5.kicad_sch, DEBUG.kicad_sch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]
2026-08-30 add Phase 3 parity fixture
    [phase3_parity_fixture.kicad_pcb]
2026-08-30 close Phase 4 V100 lane 0 schematic
    [CORE_CM5.kicad_sch, PiSXMe_RevA_Clean.kicad_sch, V100_PCIE.kicad_sch]
2026-08-30 close Phase 5 power architecture
    [POWER_INPUT.kicad_sch, REGULATORS.kicad_sch]
2026-08-30 close Phase 6 Ethernet island
    [ETHERNET.kicad_sch]
2026-08-30 close Phase 7 storage island
    [STORAGE.kicad_sch]
2026-08-30 close Phase 8 SERVICE island
    [SERVICE.kicad_sch]
2026-08-30 close Phase 10 orientation study
    [ORIENTATION_BOTTOM.kicad_pcb, ORIENTATION_TOP.kicad_pcb]
2026-08-30 close acreage floorplan review
    [ACREAGE_FLOORPLAN.kicad_pcb]
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2026-08-30 rehydrate clean phase pipeline checkpoint
    [V100_PCIE.kicad_sch]
2026-08-30 start phase 14 footprint authority
    [ETHERNET.kicad_sch, POWER_INPUT.kicad_sch, REGULATORS.kicad_sch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]
2026-08-30 add JAE B-key socket footprint authority
    [STORAGE.kicad_sch]
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2026-08-30 close USB-C service footprint authority
    [SERVICE.kicad_sch]
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2026-08-30 fix KiCad annotation and netlist export
    [COOLING.kicad_sch, CORE_CM5.kicad_sch, DEBUG.kicad_sch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]
2026-08-30 close service ESD electrical authority
    [SERVICE.kicad_sch]
2026-08-30 close service ESD footprint authority
    [SERVICE.kicad_sch]
2026-08-30 correct Ethernet ESD and regulator authority
    [ACREAGE_CANDIDATE.kicad_pcb, ETHERNET.kicad_sch, REGULATORS.kicad_sch]
2026-08-30 promote native CM5 and materialize clean candidate
    [ACREAGE_CANDIDATE.kicad_pcb, CORE_CM5.kicad_sch, POWER_INPUT.kicad_sch]
2026-08-30 make power gate fail closed on circuit authority
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2026-08-30 close phase5 power architecture gate
    [ACREAGE_CANDIDATE.kicad_pcb, POWER_INPUT.kicad_sch, PiSXMe_RevA_Clean.kicad_sch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]
2026-08-30 fix SXM2 native mapping and power aliases
    [ACREAGE_CANDIDATE.kicad_pcb, PiSXMe_RevA_Clean.kicad_sch, V100_PCIE.kicad_sch]
2026-08-30 start phase14 V100 power routing candidate
    [ACREAGE_CANDIDATE.kicad_pcb, POWER_INPUT.kicad_sch, PiSXMe_RevA_Clean.kicad_sch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]
2026-08-30 record phase14 power candidate artifact
    [ACREAGE_POWER_PHASE14.kicad_pcb]
2026-08-30 connect V100 return to shared power ground
    [ACREAGE_POWER_PHASE14.kicad_pcb]
2026-08-30 add geometry-backed phase14 power analysis
    [ACREAGE_POWER_PHASE14.kicad_pcb]
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2026-08-30 add phase14 thermal design bound
    [ACREAGE_POWER_PHASE14.kicad_pcb]
2026-08-30 reject unsafe provisional phase14 tracks
    [ACREAGE_POWER_PHASE14.kicad_pcb]
2026-08-30 rebase phase14 analysis on canonical power budget
    [ACREAGE_CANDIDATE.kicad_pcb, ACREAGE_POWER_PHASE14.kicad_pcb]
2026-08-30 hold phase14 routing candidate fail closed
    [ACREAGE_POWER_PHASE14.kicad_pcb]
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2026-08-30 close Molex 5569-2P footprint authority
    [ACREAGE_CANDIDATE.kicad_pcb, ACREAGE_POWER_PHASE14.kicad_pcb]
2026-08-30 orient Molex retention peg to manufacturer drawing
    [ACREAGE_CANDIDATE.kicad_pcb, ACREAGE_POWER_PHASE14.kicad_pcb]
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2026-08-30 phase14: correct FLR authority and power candidate
    [ACREAGE_CANDIDATE.kicad_pcb, ACREAGE_POWER_PHASE14.kicad_pcb]
2026-08-30 phase14: clear power path DRC defects
    [ACREAGE_CANDIDATE.kicad_pcb, ACREAGE_POWER_PHASE14.kicad_pcb]
2026-08-30 phase14: close power path gate
    [ACREAGE_CANDIDATE.kicad_pcb, ACREAGE_POWER_PHASE14.kicad_pcb]
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2026-08-30 phase15: correct regulator pad-edge authority
    [ACREAGE_REGULATOR_PHASE15.kicad_pcb, ACREAGE_REGULATOR_POWER_ESCAPE_PHASE15.kicad_pcb]
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2026-08-30 phase15: correct regulator evidence counts
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2026-08-30 phase15: correct TDK voltage authority
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2026-09-03 phase17: publish SP3019 fixture blocker evidence
    [SP3019_ETHERNET_DISPOSABLE_FIXTURE.kicad_pcb, SP3019_ETHERNET_FIXTURE_BASE.kicad_pcb]
2026-09-03 phase17: isolate Ethernet fixture evidence
    [SP3019_ETHERNET_DISPOSABLE_FIXTURE.kicad_pcb, SP3019_ETHERNET_FIXTURE_BASE.kicad_pcb]
2026-09-03 phase17: preserve reoriented Ethernet fixture trial
    [SP3019_ETHERNET_DISPOSABLE_FIXTURE.kicad_pcb]
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2026-09-03 phase17: checkpoint current Ethernet fixture audit
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2026-09-03 phase17: correct ESDS304 authority and publish blocker
    [ESDS304_ETHERNET_DISPOSABLE_FIXTURE.kicad_pcb]
2026-09-03 phase17: align ESDS304 fixture endpoints
    [ESDS304_ETHERNET_DISPOSABLE_FIXTURE.kicad_pcb]
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2026-09-03 phase17: close CM5IO disposable fixture gate
    [CM5IO_PISXME_ETHERNET_TRANSPLANT_FIXTURE.kicad_pcb]
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2026-09-03 phase17: correct CM5IO Ethernet transplant authority
    [CM5IO_PISXME_ETHERNET_TRANSPLANT_FIXTURE.kicad_pcb, ETHERNET.kicad_sch]
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2026-09-03 phase17: publish corrected Ethernet placement trials
    [ACREAGE_CM5IO_TOP_ISLAND_BCU_CORRECTED_PHASE17.kicad_pcb, ACREAGE_CM5IO_TOP_ISLAND_FCU_CORRECTED_PHASE17.kicad_pcb]
2026-09-03 phase17: correct current ERC evidence
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2026-09-03 phase17: record rotated ethernet fixture
    [CM5IO_ROT180_WEST_FIXTURE.kicad_pcb]
2026-09-03 phase17: isolate rotated ethernet fixture evidence
    [CM5IO_ROT180_WEST_FIXTURE.kicad_pcb]
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2026-09-03 phase17: correct J7 source transitions
    [CM5IO_J7_LAUNCH_FIXTURE.kicad_pcb]
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2026-09-03 phase17: correct CM5IO adapter orientation
    [ACREAGE_CM5IO_MAPPED_CM5IO_PHASE17.kicad_pcb]
2026-09-03 phase17: record local island approach-side failure
    [ACREAGE_CM5IO_LOCAL_BOTTOM_SPLIT_PHASE17.kicad_pcb]
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2026-09-03 phase17: correct ethernet mode coordinates
    [ACREAGE_CM5IO_RIGHT_CHANNEL_PHASE17.kicad_pcb]
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2026-09-04 phase17: record J7 CM5IO bridge fixture
    [CM5IO_J7_CM5IO_BOUNDARY_FIXTURE.kicad_pcb]
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2026-09-04 phase17: correct ethernet handoff endpoints
    [CM5IO_J7_CM5IO_BOUNDARY_FIXTURE.kicad_pcb]
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2026-09-04 phase17: correct ethernet center tap mapping
    [CM5IO_DIRECT_J7_ETHERNET_FIXTURE.kicad_pcb]
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2026-09-04 phase17: close EDAC support fixture subgate
    [CM5IO_DIRECT_J7_ETHERNET_FIXTURE.kicad_pcb]
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2026-09-04 power: correct TPSM63606 VLDOIN source mapping
    [REGULATORS.kicad_sch]
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2026-09-04 phase17: repair CM5 power hierarchy and stage local reauthoring
    [CORE_CM5.kicad_sch, PiSXMe_RevA_Clean.kicad_sch]
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2026-09-04 phase17: record underside contract fixture retry
    [CM5IO_ROT180_WEST_FIXTURE.kicad_pcb]
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2026-09-04 phase17: correct top-edge transition vias
    [ACREAGE_PHASE17_TOP_EDGE_VIAFIX.kicad_pcb, ACREAGE_PHASE17_TOP_EDGE_VIAFIX_SOFT.kicad_pcb]
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2026-09-04 phase19: correct moved-pad synchronization
    [ACREAGE_PHASE19_STORAGE_SATA_ESCAPE2.kicad_pcb]
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2026-09-04 phase19: isolate usb3 corridor failures
    [ACREAGE_PHASE19_STORAGE_USB_DIRECT4.kicad_pcb, usb_direct4_only.kicad_pcb]
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2026-09-05 phase19: correct rotated clock footprint orientation
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2026-09-05 phase24 correct clock sweep evidence
    [PHASE24_CLOCK_SWEEP_nearwest.kicad_pcb]
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2026-09-05 phase24 record complete clock fixture
    [PHASE24_CLOCK_MINIMAL_ROT0.kicad_pcb]
2026-09-05 phase24 preserve strict clock fixture rejection
    [PHASE24_COMPLETE_CLOCK_FIXTURE.kicad_pcb]
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2026-09-05 phase24 prove u5 layer source return fixture
    [PHASE24_U5_LAYER_FIXTURE.kicad_pcb]
2026-09-05 phase24 correct u5 layer fixture
    [PHASE24_U5_LAYER_FIXTURE.kicad_pcb]
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2026-09-05 phase24 record corrected clock transform trial
    [PHASE24_U5_CLOCK_FIXTURE_TRANSFORMED.kicad_pcb]
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2026-09-05 phase24 fix native U5 connectivity audit
    [PHASE24_CLOCK_OBSTACLE_REGEN.kicad_pcb]
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2026-09-05 phase24 validate split-layer clock fixture
    [PHASE24_CLOCK_FIXTURE_V2_TRANSFORMED.kicad_pcb, PHASE24_COMPLETE_CLOCK_FIXTURE_V2.kicad_pcb]
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2026-09-05 phase24 correct macro floorplan authority
    [PHASE24_MACRO_ETH_SOUTH.kicad_pcb, PHASE24_MACRO_ETH_WEST.kicad_pcb]
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2026-09-05 phase24: checkpoint immutable macro parent and clean ethernet overlay
    [PHASE24_CLEAN_ETH_OVERLAY.kicad_pcb, PHASE24_SELECTED_MACRO_PARENT_20260905.kicad_pcb]
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2026-09-05 phase24: correct macro placement collision basis
    [PHASE24_CORRECTED_MACRO_PLACEMENT.kicad_pcb, PHASE24_MACRO_REVIEW2_STORAGE_LOCAL_CLEAR.kicad_pcb]
2026-09-05 phase24: promote corrected coherent routing basis
    [PHASE24_MACRO_REVIEW2_ETH_WEST_CLEAR_STORAGE_MID.kicad_pcb, PHASE24_MACRO_REVIEW2_ETH_WEST_OUTBOARD_STORAGE_CLEAR.kicad_pcb]
2026-09-05 phase24: preserve corrected Ethernet route trial
    [PHASE24_CORRECTED_ETHERNET_MDI_ROUTE.kicad_pcb]
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2026-09-05 phase24: derive Ethernet routing layers from native pads
    [PHASE24_CORRECTED_ETHERNET_LAYER_AUTH_ROUTE_V3.kicad_pcb]
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2026-09-06 phase24: close complete CM5IO Ethernet fixture oracle
    [CM5IO_DIRECT_J7_ETHERNET_FIXTURE.kicad_pcb, PHASE24_OFFICIAL_ETH_SUPPORT_MATERIALIZED.kicad_pcb]
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2026-09-06 phase24: correct obstacle probe receipt date
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2026-09-06 phase24: record selected macro ethernet regen failure
    [PHASE24_SELECTED_MACRO_ETH_MDI_REGEN.kicad_pcb]
2026-09-06 phase24: correct ethernet endpoint escape model
    [PHASE24_SELECTED_MACRO_ETH_MDI_REGEN_V2.kicad_pcb]
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2026-09-06 phase24: correct storage layer transition emission
    [PHASE24_STORAGE_LOCAL_J3_EDGE_USB3_DIRECT.kicad_pcb]
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2026-09-06 phase24: correct USB3 crossing evidence
    [PHASE24_STORAGE_USB3_REFERENCE_ESCAPE.kicad_pcb]
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2026-09-06 phase24: preserve minimal USB3 fixture evidence
    [PHASE24_USB3_MINIMAL_NATIVE_FIXTURE.kicad_pcb]
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2026-09-06 phase24: preserve integrated USB3 collision screen
    [PHASE24_STORAGE_LOCAL_J3_EDGE_USB3_CLEANPASS.kicad_pcb, PHASE24_USB3_CM5IO_SOURCE_ESCAPE_U7_ROT0_CLEANPASS.kicad_pcb]
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2026-09-06 phase24: record U7 support integration failure
    [PHASE24_STORAGE_NATIVE_ORACLE_SUPPORT_TRANSPLANT.kicad_pcb]
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2026-09-06 phase24: add TI U7 footprint authority fixture
2026-09-06 phase24: route U7 footprint generation to TI land pattern
    [STORAGE.kicad_sch]
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2026-09-06 phase24: validate TI footprint replacement fixture
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2026-09-06 phase24 correct source-local storage probe
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2026-09-06 phase24 validate TI U7 escape and reject fixed integration
    [PHASE24_SELECTED_MACRO_SWAP_ETH_STORAGE_TI_USB3_RX_SPLIT_V2.kicad_pcb, PHASE24_USB3_LOCAL_TI_RX_SPLIT_V2.kicad_pcb]
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2026-09-06 phase24 correct anchored USB3 lane channels
    [PHASE24_SELECTED_MACRO_SWAP_ETH_STORAGE_TI_CM5IO_PAIR_LAYER_SPLIT.kicad_pcb]
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2026-09-06 phase24 correct JMS583 authority and mode contract
    [STORAGE.kicad_sch]
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2026-09-06 phase24 correct storage mode reference collision
    [PHASE24_DUAL_MODE_STORAGE_PLACEMENT.kicad_pcb]
2026-09-06 phase24 correct storage selector instance reference
    [STORAGE.kicad_sch]
2026-09-06 phase24 route initial JMS583 support fixture
    [PHASE24_DUAL_MODE_STORAGE_SUPPORT_ROUTED.kicad_pcb, STORAGE.kicad_sch]
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2026-09-06 phase24 correct CM5 storage USB2 authority
    [CORE_CM5.kicad_sch, PHASE24_DUAL_MODE_STORAGE_PLACEMENT.kicad_pcb, PiSXMe_RevA_Clean.kicad_sch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]
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2026-09-06 phase24 correct TI selector land pattern
    [PHASE24_DUAL_MODE_STORAGE_PLACEMENT.kicad_pcb]
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2026-09-06 phase24 correct jms583 qfn64 authority
    [PHASE24_DUAL_MODE_STORAGE_PLACEMENT.kicad_pcb]
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2026-09-06 phase24 correct RTL9210B qualification footprint
2026-09-06 phase24 strengthen RTL9210B footprint audit
2026-09-06 phase24 reject RTL9210B crude fixture
    [PHASE24_RTL9210B_NATIVE_FIXTURE.kicad_pcb, pin-fact-boundary.csv]
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2026-09-06 phase24 pin corrected RTL9210B fixture mapping
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2026-09-07 phase24 correct SATA M2 contact authority
    [PHASE24_PATHA_SATA_NATIVE_ASTAR_M2CONTACTS_20260906.kicad_pcb, STORAGE.kicad_sch]
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2026-09-07 phase24 preserve dual mode high speed fixture
    [PHASE24_DUAL_MODE_STORAGE_HS_ISOLATED_SATA_V4_20260906.kicad_pcb]
2026-09-07 phase24 correct SATA selector authority
    [STORAGE.kicad_sch]
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2026-09-07 phase24 add RTL9210B bringup fixture
    [PHASE24_RTL9210B_BRINGUP_FIXTURE.kicad_pcb]
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2026-09-07 phase24 correct RTL9210B fixture layers
    [PHASE24_RTL9210B_LOCAL_OSCILLATOR.kicad_pcb, PHASE24_RTL9210B_LOCAL_OSCILLATOR_V2.kicad_pcb, PHASE24_RTL9210B_SUPPORT_LOCAL_V2.kicad_pcb]
2026-09-07 phase24 preserve RTL9210B oscillator route trials
    [PHASE24_RTL9210B_LOCAL_OSCILLATOR_V3.kicad_pcb, PHASE24_RTL9210B_LOCAL_OSCILLATOR_V4.kicad_pcb]
2026-09-07 phase24 close RTL9210B oscillator route subgate
    [PHASE24_RTL9210B_LOCAL_OSCILLATOR_V5.kicad_pcb, PHASE24_RTL9210B_LOCAL_OSCILLATOR_V6.kicad_pcb, PHASE24_RTL9210B_LOCAL_OSCILLATOR_V7.kicad_pcb]
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2026-09-07 phase24 add RTL9210B fixture ground reference
    [PHASE24_RTL9210B_SPI_V7_GND_PLANES.kicad_pcb, PHASE24_RTL9210B_SPI_V7_GND_PLANES_V2.kicad_pcb, PHASE24_RTL9210B_SPI_V7_GND_PLANES_V3.kicad_pcb]
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2026-09-07 phase24 close RTL9210B reset perst subgate
    [PHASE24_RTL9210B_CONTROL_V1.kicad_pcb, PHASE24_RTL9210B_PERST.kicad_pcb, PHASE24_RTL9210B_RESET_PERST_V2.kicad_pcb]
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2026-09-07 phase24 preserve Path A M2 launches V5 V6
    [PHASE24_PATHA_M2_LANE0_LAUNCH_ISOLATED_V5.kicad_pcb, PHASE24_PATHA_M2_LANE0_LAUNCH_ISOLATED_V6.kicad_pcb]
2026-09-07 phase24 preserve Path A M2 launches V7 V8
    [PHASE24_PATHA_M2_LANE0_LAUNCH_ISOLATED_V7.kicad_pcb, PHASE24_PATHA_M2_LANE0_LAUNCH_ISOLATED_V8.kicad_pcb]
2026-09-07 phase24 preserve Path A M2 launches V9 V10
    [PHASE24_PATHA_M2_LANE0_LAUNCH_ISOLATED_V10.kicad_pcb, PHASE24_PATHA_M2_LANE0_LAUNCH_ISOLATED_V9.kicad_pcb]
2026-09-07 phase24 preserve Path A M2 launches V11 V12
    [PHASE24_PATHA_M2_LANE0_LAUNCH_ISOLATED_V11.kicad_pcb, PHASE24_PATHA_M2_LANE0_LAUNCH_ISOLATED_V12.kicad_pcb]
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2026-09-07 phase24 preserve Path B 1V1 collectors V2 V3
    [PHASE24_RTL9210B_1V1_QFN_COLLECTOR_V2.kicad_pcb, PHASE24_RTL9210B_1V1_QFN_COLLECTOR_V3.kicad_pcb]
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2026-09-07 phase24 preserve Path B RTL_5V rail escapes V2 V3
    [PHASE24_RTL9210B_5V_PAD17_V2.kicad_pcb, PHASE24_RTL9210B_5V_PAD17_V3.kicad_pcb]
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2026-09-07 phase24 preserve rejected Path B 3V3 pad52 escapes
    [PHASE24_RTL9210B_3V3_PAD52_V1.kicad_pcb, PHASE24_RTL9210B_3V3_PAD52_V2.kicad_pcb]
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2026-09-07 phase24 preserve rejected Path B crystal layer split
    [PHASE24_RTL9210B_CRYSTAL_V2.kicad_pcb]
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2026-09-07 phase24 preserve rejected Path B U2 3V3 trunks
    [PHASE24_RTL9210B_3V3_U2_BCU_V1.kicad_pcb]
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2026-09-07 phase24 stabilize Path B support relocation baseline
    [PHASE24_RTL9210B_SUPPORT_BRANCH_RELOCATED_V1.kicad_pcb]
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2026-09-07 phase24 tighten lateral SPI proof
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2026-09-07 phase24 isolate fixture testpad findings
    [PHASE24_RTL9210B_FULL_LATERAL_SUPPORT_CRYSTAL_V4_NO_TESTPADS.kicad_pcb, PHASE24_RTL9210B_FULL_LATERAL_SUPPORT_CRYSTAL_V5_NO_FIXTURE_STUBS.kicad_pcb]
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2026-09-07 phase24 document RTL9210B SPICS escape failure
    [PHASE24_RTL9210B_SPICS_LAYER_PROBE_V1.kicad_pcb]
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2026-09-07 phase24 correct RTL9210B flash footprint frame
    [PHASE24_RTL9210B_ROTATE_U1_STAGGERED_SPI_V1.kicad_pcb, PHASE24_RTL9210B_U2_CORRECTED_FOOTPRINT_V1.kicad_pcb, PHASE24_RTL9210B_U2_LEFT_SPI_V1.kicad_pcb]
2026-09-07 phase24 test corrected rotated flash placement
    [PHASE24_RTL9210B_U2_CORRECTED_LEFT_ROT90_PLACEMENT_V1.kicad_pcb, PHASE24_RTL9210B_U2_CORRECTED_LEFT_ROT90_SPI_V1.kicad_pcb]
2026-09-07 phase24 test corrected far SPI partition
    [PHASE24_RTL9210B_U2_CORRECTED_FAR_PARTITION_SPI_V1.kicad_pcb]
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2026-09-07 phase24 test corrected flash handoff
    [PHASE24_RTL9210B_SPISO3_CORRECTED_U2_V2.kicad_pcb]
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2026-09-07 phase24 correct RTL9210B U1 footprint frame
    [PHASE24_RTL9210B_CORRECT_U1_FRAME_V47.kicad_pcb]
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2026-09-07 phase24 preserve RTL9210B 1v1 xtal collision
    [PHASE24_RTL9210B_1V1_BOTTOM60_V68.kicad_pcb]
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2026-09-07 promote RTL9210B V100 and reconcile Phase 24 status
    [PHASE24_RTL9210B_XTALOUT_U155_LEFT_ESCAPE_V100.kicad_pcb]
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2026-09-07 Record RTL9210B REFCLK V146 V147 failures
    [PHASE24_RTL9210B_REFCLK_F_CORRIDOR_V146.kicad_pcb, PHASE24_RTL9210B_REFCLK_OUTER_F_V147.kicad_pcb]
2026-09-07 Record RTL9210B local 1V1 relocation failures
    [PHASE24_RTL9210B_RELOCATE_1V1_FOR_REFCLK_V148.kicad_pcb, PHASE24_RTL9210B_RELOCATE_1V1_XTAL_OVERPASS_V149.kicad_pcb]
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2026-09-07 Record RTL9210B SPICLK route failures
    [PHASE24_RTL9210B_SPICLK_U119_U2_V194.kicad_pcb, PHASE24_RTL9210B_SPICLK_U119_U2_V196.kicad_pcb, PHASE24_RTL9210B_SPICLK_XTAL_V195.kicad_pcb]
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2026-09-07 Record RTL9210B SPISI allocation failure
    [PHASE24_RTL9210B_SPISI_U118_U2_V201.kicad_pcb]
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2026-09-07 Record RTL9210B V256 rail clearance evidence
    [.phase24_v256_negative_removed_trace.kicad_pcb, PHASE24_RTL9210B_RTL1V1_U136_U139_U152_V255.kicad_pcb, PHASE24_RTL9210B_RTL1V1_U136_U139_U152_V256.kicad_pcb]
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2026-09-08 Refine RTL9210B oscillator escape geometry
    [PHASE24_RTL9210B_SIGNAL_VIA_GEOMETRY_V393.kicad_pcb, PHASE24_RTL9210B_XTALIN_ESCAPE_V392.kicad_pcb, PHASE24_RTL9210B_XTALIN_VIA_OUTBOARD_V396.kicad_pcb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]
2026-09-08 Record RTL9210B local clearance trial
    [PHASE24_RTL9210B_LOCAL_CLEARANCE_V399.kicad_pcb]
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2026-09-08 Record RTL9210B 1V1 route collision
    [PHASE24_RTL9210B_QFN_COALLOCATE_V536.kicad_pcb]
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2026-09-08 Correct RTL9210B strict width baseline
    [PHASE24_RTL9210B_QFN_COALLOCATE_V558_STRICT.kicad_pcb]
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2026-09-08 Retain corrected RTL9210B support baseline
    [PHASE24_RTL9210B_SUPPORT_COALLOCATED_V562.kicad_pcb]
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2026-09-08 Reject RTL9210B source clearance nudge
    [PHASE24_RTL9210B_SUPPORT_COALLOCATED_V575_SOURCE_CLEARANCE.kicad_pcb]
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2026-09-08 Record RTL9210B SPI route failures
    [PHASE24_RTL9210B_SUPPORT_COALLOCATED_V596_SPICS.kicad_pcb, PHASE24_RTL9210B_SUPPORT_COALLOCATED_V597_SPICS_FCU.kicad_pcb]
2026-09-08 Record RTL9210B SPI corridor failures
    [PHASE24_RTL9210B_SUPPORT_COALLOCATED_V598_SPICS_WEST.kicad_pcb, PHASE24_RTL9210B_SUPPORT_COALLOCATED_V599_SPICS_OUTER_FCU.kicad_pcb]
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2026-09-08 Record RTL9210B SPISO3 route failures
    [PHASE24_RTL9210B_SUPPORT_COALLOCATED_V603_SPISO3_ESCAPE.kicad_pcb, PHASE24_RTL9210B_SUPPORT_COALLOCATED_V604_SPISO3_WEST_ENDPOINT.kicad_pcb]
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2026-09-08 Record RTL9210B SPISO corridor failure
    [PHASE24_RTL9210B_SUPPORT_COALLOCATED_V616_SPISO_LOWER_CORRIDOR.kicad_pcb]
2026-09-08 Record RTL9210B SPICLK source failures
    [PHASE24_RTL9210B_SUPPORT_COALLOCATED_V617_SPICLK_CHANNEL.kicad_pcb, PHASE24_RTL9210B_SUPPORT_COALLOCATED_V618_SPICLK_SOURCE_SEP.kicad_pcb, PHASE24_RTL9210B_SUP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]
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2026-09-08 Record V35 RTL9210B 1V1 field failure
    [PHASE24_RTL9210B_SUPPORT_CLUSTER_MOVE_V35_RTL1V1_PROBE.kicad_pcb]
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2026-09-08 record RTL9210B far perimeter escape failure
    [PHASE24_RTL9210B_QFN_ORIENTATION0_U139_FAR_ESCAPE.kicad_pcb]
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2026-09-08 correct live storage architecture metadata
    [PiSXMe_RevA_Clean.kicad_sch]
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2026-09-08 fix RTL9210B rail negative control
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2026-09-08 clear Path A storage placement shorts
    [PHASE24_DUAL_MODE_STORAGE_PLACEMENT_CURRENT.kicad_pcb]
2026-09-08 fix JMS583 crystal net authority
    [PHASE24_DUAL_MODE_STORAGE_PLACEMENT_CURRENT.kicad_pcb]
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2026-09-08 phase24 record native reset escape trial
    [PHASE24_JMS583_RESET_LOCAL_ESCAPE.kicad_pcb]
2026-09-08 phase24 preserve reset via corridor trial
    [PHASE24_JMS583_RESET_VIA_ESCAPE.kicad_pcb]
2026-09-08 phase24 validate lateral JMS reset escape
    [PHASE24_JMS583_RESET_SOUTH_PROBE.kicad_pcb, PHASE24_JMS583_RESET_SOUTH_PROBE_NEGATIVE.kicad_pcb]
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2026-09-08 phase24 validate JMS reset delay branch
    [PHASE24_JMS583_RESET_DELAY_NEGATIVE.kicad_pcb, PHASE24_JMS583_RESET_DELAY_PROBE.kicad_pcb]
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2026-09-08 phase24 preserve JMS REXT clearance evidence
    [PHASE24_JMS583_SUPPORT_COHORT_REXT_V1.kicad_pcb, PHASE24_JMS583_SUPPORT_COHORT_REXT_V2.kicad_pcb, PHASE24_JMS583_SUPPORT_COHORT_REXT_V3.kicad_pcb]
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2026-09-08 phase24 add JMS reset delay cohort
    [PHASE24_JMS583_SUPPORT_COHORT_PROBE.kicad_pcb, PHASE24_JMS583_SUPPORT_COHORT_V7_NEGATIVE.kicad_pcb]
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2026-09-08 phase24 recheck JMS crystal fixture
    [PHASE24_JMS583_CRYSTAL_ESCAPE_PROBE.kicad_pcb, PHASE24_JMS583_CRYSTAL_PAD20_NEGATIVE.kicad_pcb]
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2026-09-08 phase24 fix JMS support label authoring
    [STORAGE.kicad_sch]
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2026-09-08 phase24 fix JMS source association parity
    [PHASE24_DUAL_MODE_STORAGE_PLACEMENT_NC39.kicad_pcb, STORAGE.kicad_sch]
2026-09-08 phase24 record corrected JMS route trial
    [PHASE24_DUAL_MODE_STORAGE_NC39_SUPPORT_TRIAL.kicad_pcb]
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2026-09-08 phase24 fix U12 USB3 source mapping
    [PHASE24_DUAL_MODE_STORAGE_NC39_USB3_FULL5.kicad_pcb, STORAGE.kicad_sch]
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2026-09-08 phase24 use corrected USB3 authority
    [PHASE24_DUAL_MODE_STORAGE_USB3_LOCAL_FROM_FULL7.kicad_pcb, PHASE24_DUAL_MODE_STORAGE_USB3_LOCAL_NEXT.kicad_pcb]
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2026-09-08 phase24 map per-net support failures
    [PHASE24_STORAGE_JMS_AVDD33_TRIAL.kicad_pcb, PHASE24_STORAGE_JMS_RESET_N_TRIAL.kicad_pcb, PHASE24_STORAGE_JMS_REXT_TRIAL.kicad_pcb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]
2026-09-08 phase24 promote reset native route
    [PHASE24_DUAL_MODE_STORAGE_FULL7_RESET.kicad_pcb, PHASE24_DUAL_MODE_STORAGE_FULL7_RESET_NEGATIVE.kicad_pcb]
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2026-09-09 phase24 correct U13 SATA lane authority
    [PHASE24_DUAL_MODE_STORAGE_U13FIX_SATA_V2.kicad_pcb, STORAGE.kicad_sch]
2026-09-09 phase24 regenerate storage from corrected authority
    [PHASE24_STORAGE_AUTHORITY_CORRECTED_PLACEMENT.kicad_pcb, PHASE24_STORAGE_AUTHORITY_CORRECTED_SUPPORT.kicad_pcb, PHASE24_STORAGE_AUTHORITY_CORRECTED_USB3_SATA.k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]
2026-09-09 phase24 promote corrected storage support zones
    [PHASE24_STORAGE_AUTHORITY_CORRECTED_SUPPORT_ZONES.kicad_pcb, PHASE24_STORAGE_AUTHORITY_CORRECTED_USB3_SATA_ZONES_FINAL.kicad_pcb, PHASE24_STORAGE_AUTHORITY_COR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]
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2026-09-09 phase24: correct native SATA selector escapes
    [PHASE24_STORAGE_SELECTOR_SATA_ESCAPE_V1.kicad_pcb, PHASE24_STORAGE_SELECTOR_SATA_ESCAPE_V2.kicad_pcb, PHASE24_STORAGE_SELECTOR_SATA_ESCAPE_V3.kicad_pcb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]
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2026-09-09 phase24: repair CM5 USB3 launch and VCCO destination
    [PHASE24_STORAGE_USB3_RIGHT_LAUNCH_V2.kicad_pcb, PHASE24_STORAGE_VCCO_DEST_V1.kicad_pcb, PHASE24_STORAGE_VCCO_DEST_V1_NEGATIVE.kicad_pcb]
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2026-09-09 phase24: clear JMS VCCK support shorts
    [PHASE24_STORAGE_VCCK_LOCAL_V1.kicad_pcb, PHASE24_STORAGE_VCCK_LOCAL_V1_NEGATIVE.kicad_pcb, PHASE24_STORAGE_VCCK_LOCAL_V1_NEGATIVE_VCCO.kicad_pcb]
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

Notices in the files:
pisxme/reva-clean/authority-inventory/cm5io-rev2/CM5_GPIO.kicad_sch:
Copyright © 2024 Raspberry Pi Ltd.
